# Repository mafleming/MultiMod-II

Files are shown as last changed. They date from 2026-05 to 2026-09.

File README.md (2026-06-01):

HP-71B MultiMod II Repository

# MultiMod II, ROM and RAM Storage for the HP-71B

The MultiMod II is a follow-on development of the MultiMod ROM Emulator for the HP-71B handheld computer. The MultiMod was based on a Microchip PIC processor that stored ROM images in its flash memory and made those ROMs accessible to the HP-71B operator. However, the MultiMod could not provide RAM memory.

The MultiMod II is based on a Lattice iCE40UP5K FPGA with 128KB of single port RAM (SPRAM) and 15KB of dual port RAM. The FPGA fabric provides the logic needed to present the content of the SPRAM as a series of both ROM or RAM devices. The Winbond 16KB serial flash memory serves to hold up to four FPGA configuration bitstreams, and is also used to store ROM images that the HP-71B operator can dynamically plug and unplug into the HP-71B as needed.

# MultiMod II Board Design
The MultiMod II PCB is a four layer, two sided component design. The design was done in Kicad 9.0 and the design files can be found in the **board** directory.

# MultiMod II FPGA Configuration
To configure and provide content for ROM and RAM memories, a soft CPU is instantiated in fabric using the 15KB of dual port RAM for its programs. The J1a Forth CPU was selected in order to implement the intelligent functionality of the MultiMod II HP-71B accessory. The use of Forth as the base language complemented the availability of Forth for the HP-71B itself. The basis files can be found in the **mecrisp-ice-2.7** directory.

The mecrisp-ice project combines the J1a Forth CPU with the Mecrisp ANSI Forth implementation that targets the J1a instruction set. Details about the J1a implementation can be found at James Bowman's [github repository](https://github.com/jamesbowman/swapforth). More information about Mecrisp Forth can be found at its [Sourceforge](https://mecrisp.sourceforge.net/) site. [Unofficial documentation](https://mecrisp-stellaris-folkdoc.sourceforge.io/) for Mecrisp Forth can be found on Sourceforge as well.

This configuration was customized for two purposes; one configuration serves as a programmable bootloader when connected to a host, while the second is the production configuration when the MultiMod II is operating in the HP-71B.

## Bootloader Configuration
The bootloader Verilog and Forth files can be found in the **mmj1boot** subdirectory within the **mecrisp-ice** containing directory.

The bootloader configuration uses the standard mecrisp-ice j1a processor and USB device to communicate with a connected host. Going beyond the standard bootloader ability to update the production configuration, the interactive Forth console provides the means to transfer files and even extend its own capabilities.

## Production Configuration
The bootloader Verilog and Forth files can be found in the **multimod** subdirectory within the **mecrisp-ice** containing directory.

The production bitstream configuration replaces the mecrisp-ice USB device interface with a serial interface. The serial device data and control registers are mapped into the HP-71B address space so that the HP-71B can interact with the Forth console. This gives the HP-71B operator the ability to configure the MultiMod II, plugging and unplugging ROMs at will. Independent RAM (IRAM) device content can be saved to flash, allowing the operator to compose collections of programs that can be saved to flash and later loaded when needed. All the functional capability of an external storage device are provided by the MultiMod II.

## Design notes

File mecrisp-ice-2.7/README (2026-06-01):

-------------------------------------------------------------------------------

Mecrisp-Ice - A conveniently enhanced fork of Swapforth by James Bowman

  It makes your Lattice Icestick FPGA development board
  to behave just like a microcontroller.

The original Swapforth and J1a processor implementation can be found here:
http://www.excamera.com/sphinx/article-j1a-swapforth.html

I would not have been possible without the first open-source FPGA toolchain:
http://www.clifford.at/icestorm/

Many, many thanks to James Bowman and the whole Icestorm team !

http://mecrisp.sourceforge.net/
m-atthias@users.sf.net

-------------------------------------------------------------------------------

HIC SUNT DRACONES - HIC SUNT DRACONES - HIC SUNT DRACONES

This is the first experimental release, so beware: Monsters may be inside !

-------------------------------------------------------------------------------

Shortly after Clifford Wolff, Mathias Lasser and Cotton Seed managed to build
the first working completely open-source FPGA toolchain for the iCE40-HX1K,
James Bowman started porting his elegant J1 processor design.

I have been involved in testing and enhanced the resulting monumental work
with stronger optimisations and a handfull of features for convenience.

-------------------------------------------------------------------------------

What you need:

* A Lattice Icestick with an iCE40-HX1K FPGA
    http://www.latticesemi.com/icestick

* Or a Nandland Go with iCE40-HX1K FPGA
    https://www.nandland.com/goboard/introduction.html

* Or a Lattice HX8K breakout board with an iCE40-HX8K FPGA

* The Iceprog tool to flash the included binary
    http://www.clifford.at/icestorm/

* A terminal, picocom is fine.

-------------------------------------------------------------------------------

Which board for you ?

If you just wish to play with a stack processor,
if you have small ideas,
if you desire to have IrDA communication,
if you wish a cheap, cool looking board,
if you are fine without tinkering with additional logic

  --> HX1K Icestick is your choice.

If you wish to experiment with VGA video,
if you like 7-segment displays,
if you need buttons on your board

  --> HX1K Nandland Go should be the right for you.

If you have large ideas in Forth,
if you need a lot of IO pins,
if you wish to wire in additional peripherals, opcodes or whatever you imagine,
if you love to have single cycle multiplier and barrel shifters

  --> HX8K breakout board will give you a nice time.

-------------------------------------------------------------------------------

Basic usage, same for HX1K and HX8K:

  Flash the binary:
  iceprog -b j1a.bin

  Open a terminal:

(HX1K)  picocom -b 230400 /dev/ttyUSB$n --imap lfcrlf,crcrlf --omap delbs,crlf --send-cmd "ascii-xfr -s -l 30 -n"
(HX8K)  picocom -b 115200 /dev/ttyUSB$n --imap lfcrlf,crcrlf --omap delbs,crlf --send-cmd "ascii-xfr -s -l 30 -n"

  Toggle DTR line to Reset by pressing Crtl+A Ctrl+T Crtl+A Ctrl+T

  You should get a welcome message.

  If you hard crash it, iceprog -t or a power cycle should recover.

-------------------------------------------------------------------------------

Some notes for Forth users new to this target and its peripheral possibilities:

The Icestick has 8 kb of initialised RAM which is mapped from address
$0000 to $1FFF and a SPI flash to store the FPGA bitstream and additional
user generated memory images.

Data and return stack are 16 elements deep. James implemented them as
part of the CPU itself, so they are not accessible through memory.

Pinout and board layout:

       /--------------------------------------
      /                 Header 1:  76543210-+
     /            ________              ++
    /            |        |      R      --
[USB]  FT        |  FPGA  |    R G R    73   Ir
[USB]  DI        |        |      R      62   DA
    \            |________|             51
     \                                  40
      \                 Header 2:  01234567-+
       \--------------------------------------

  Numbers are bit numbers
  + is 3.3 V   - is GND
  G Green LED  R Red LEDs

There is a separate IO address space, with those registers available:

     Addr  Bit READ            WRITE

     0001  0   PMOD in
     0002  1   PMOD out        PMOD out
     0004  2   PMOD dir        PMOD dir
     0008  3   misc.out        misc.out

     0010  4   header 1 in
     0020  5   header 1 out    header 1 out
     0040  6   header 1 dir    header 1 dir
     0080  7

     0100  8   header 2 in
     0200  9   header 2 out    header 2 out
     0400  10  header 2 dir    header 2 dir
     0800  11

     1000  12  UART RX         UART TX
     2000  13  misc.in
     4000  14  ticks           set ticks
     8000  15

Contents of misc.out and misc.in:

   Bitmask Bit  misc.out        misc.in

     0001    0  SPI CS          UART Ready to Transmit
     0002    1  SPI MOSI        UART Character received
     0004    2  SPI SCK         SPI MISO
     0008    3  IrDA-TXD        IrDA-RXD
     0010    4  IrDA-Sleep      RTS
     0020    5  CTS             Random
     0040    6  Green LED
     0080    7  Red LED
     0100    8  Red LED
     0200    9  Red LED
     0400   10  Red LED

If you are already familiar with MSP430 chips,
you will know this IO port style:

* The IN register gives the current electrical state
* The contents of the OUT registers determine what level the outputs should be
* The DIR register let you switch a pin to be an output by writing an one into

You can set two registers at once if you OR together their addresses.
  255 $440 io! should set all header pins as outputs.

Inputs can ORed together the same way and give an ORed result.

You can detect short-circuited pins -
  for example if a pin is set to output and low, but shortened to Vcc,
  then the OUT register will read back low, as set by you, but the
  IN register will read high for that pin.

Misc.out and misc.in are a mixed back of wires and flags available.

No fear to destroy the IrDA transceiver with too long pulses as it turns off
the IR LED itself when IrDA-TXD is high for more than 50 us.

The UART data register is for both incoming and outgoing data,
a read from it will clear the "Character received" flag
and you should only write to it when "Ready to Transmit" is set.

Ticks contains a 16 bit cycle counter that counts up with 48 MHz and
you can set it to any value you wish by writing to it.

Memory location $0002 is an interrupt vector for the ticks counter overflow.
You can place an opcode there, perhaps ALU Exit ($608C) or a JMP to a handler.
Interrupts can be enabled with eint and disabled with dint.

-------------------------------------------------------------------------------

Notes on HX8K:
--------------

This feels very similiar to Mecrisp-Ice on HX1K, just with a few differences:

  + Double amount of memory: 16 kb instead of 8 kb
  + Double stack depth: 32 elements each instead of 16
  + Barrel shifter for single cycle lshift rshift arshift
  + Single cycle multiplication
  + Fast opcodes for 1+ and 1-
  + rdepth
  + 8 LEDs instead of 5
  + Lots of gates free for experiments
  - 36 MHz only
  - No IrDA
  - Variable @ needs 2 instructions and 5 cycles instead of 1 instruction and 2 cycles

The peripheral map is the same, but the IN, OUT and DIR registers
are up to 16 bits wide, with the following connections:

 $0001 Port A IN     $0010 Port B IN     $0100 Port C IN
 $0002 Port A OUT    $0020 Port B OUT    $0200 Port C OUT
 $0004 Port A DIR    $0040 Port B DIR    $0400 Port C DIR

                     Red LEDs
                     76543210
  1.2V 3.3V   oo                 oo   oo
  1.2V B13    oo                 oo   oo
  A12  B12    oo     ________    oo   oo
  GND  GND    oo    |        |   oo   oo
  A11  B11    oo    |  FPGA  |   oo   oo
  A10  B10    oo    |        |   oo   oo
  A9   B9     oo    |________|   oo   oo
  GND  GND    oo                 oo   oo
  A8   B8     oo                 oo   oo
  A7   B7     oo                 oo   oo
  A6   B6     oo  Jumper config: oo   oo
  GND  GND    oo                 oo   oo
  A5   B5     oo     |     ||    oo   oo
  A4   B4     oo                 oo   oo
  A3   B3     oo        Green    oo   oo
  GND  GND    oo        LED      oo   oo
  A2   B2     oo     FT          oo   oo
  A1   B1     oo     DI          oo   oo
  A0   B0     oo                 oo   oo
  GND  GND    oo     [USB]       oo   oo
                     [USB]

  Port C is currently unconnected, you can wire the bits as you wish
  in the constraints PCF file.

Ticks contains a 16 bit cycle counter that counts up with 36 MHz and
you can set it to any value you wish by writing to it.

Memory location $0002 is an interrupt vector for the ticks counter overflow.
You can place an opcode there, perhaps ALU Exit ($608C) or a JMP to a handler.
Interrupts can be enabled with eint and disabled with dint.

-------------------------------------------------------------------------------

Notes on Nandland Go:
---------------------

S4 is Reset button, as DTR line is not connected on this board.

     Addr  Bit READ            WRITE

     0001  0   PMOD in
     0002  1   PMOD out        PMOD out
     0004  2   PMOD dir        PMOD dir
     0008  3   misc.out        misc.out

     0010  4                   VGA Colours
     0020  5                   VGA HSYNC
     0040  6                   VGA VSYNC
     0080  7   Segments        Segments

     0100  8
     0200  9
     0400  10
     0800  11

     1000  12  UART RX         UART TX
     2000  13  misc.in
     4000  14  ticks           set ticks
     8000  15

Contents of misc.out and misc.in:

   Bitmask Bit  misc.out        misc.in

     0001    0  SPI CS          UART Ready to Transmit
     0002    1  SPI MOSI        UART Character received
     0004    2  SPI SCK         SPI MISO
     0008    3  Green LED 1     Random
     0010    4  Green LED 2     S1
     0020    5  Green LED 3     S2
     0040    6  Green LED 4     S3

Note that you can OR together the VGA lines.

    VSYNC HSYNC Blue 2 Blue 1 Blue 0 Green 2 Green 1 Green 0 Red 2 Red 1 Red 0

$10:               256    128     64      32      16       8     4     2     1
$20:        512
$40: 1024

So by writing IO Register $60, you can set HSYNC and VSYNC independently
from the colour register bits. If you prefer to have all VGA signals
in one register, use IO port $70.

Ticks contains a 16 bit cycle counter that counts up with 25 MHz and
you can set it to any value you wish by writing to it.

Memory location $0002 is an interrupt vector for the ticks counter overflow.
You can place an opcode there, perhaps ALU Exit ($608C) or a JMP to a handler.
Interrupts can be enabled with eint and disabled with dint.

-------------------------------------------------------------------------------

Special features included in Mecrisp-Ice:
-----------------------------------------

You can save the complete current memory contents into the SPI flash
sectors 1 to 63. Sector 0 contains the FPGA bitstream, sector 1 will be
loaded automatically on startup if you save a memory image into this.

sector# load
sector# save
sector# erase

There is a variable "init" which is executed after loading an image.

So if you wish to create a turnkey application, prepare everything in RAM
and type:

  ' fireworks init !
  1 save

Replace fireworks with whatever you wish to be executed on startup.
Nothing is executed if init contains a zero, which is the default.

If you are not sure if it will work properly, save to any other sector
and load manually. The init mechanism works the same on all sectors.

On HX8K: Sectors 0, 1 and 2 contain the bitstream.
         Sector 3 will be loaded automatically if available.

The Nandland Go has a smaller SPI Flash with four sectors only:

  0: Bitstream
  1: Autoload
  2:  Free
  3:  Free

-----------------------------------------

For your convenience, some introspection features are preloaded for default.

Things to try:

  0 8192 dump
  insight
  see +

They will be removed by typing "new" so that you have more space available.

-----------------------------------------

Inline optimisations and constant folding are included !

-------------------------------------------------------------------------------

Main differences to Mecrisp and Mecrisp-Stellaris:

Unlike Mecrisp and Mecrisp-Stellaris, this is running completely
in RAM memory. So there is no need for special memory handling !

You can use CREATE with DOES> and if you need a buffer,
just CREATE ... ALLOT it.

By the way: If you save a memory image, the last contents of the variables
are saved during the process and reloaded with the image. Variables are
initialised, but there is no logic to reinitialise them on Reset to the
values assigned at compilation.

-------------------------------------------------------------------------------

If you wish to build the whole package yourself:

* Gforth
* Freepascal
* Yosys for synthesis
* Arachne-PNR for place and route
* Icestorm tools for bitstream generation

... and their dependencies.

In a nutshell, you need to type:

  compile
  iceprog -b j1a.bin

That's all.

;------------------------------------------------------------------------------
Here comes a word list,                                          -- Glossary --
  with short descriptions of all currently included words:
View it with fixed-width font !
;------------------------------------------------------------------------------

;------------------------------------------------------------------------------
; Terminal-IO
;------------------------------------------------------------------------------

        emit?           ( -- Flag ) Ready to send a character ?
        key?            ( -- Flag ) Checks if a key is waiting
        key             ( -- Char ) Waits for and fetches the pressed key
        emit            ( Char -- ) Emits a character.

;------------------------------------------------------------------------------
; Stack Jugglers
;------------------------------------------------------------------------------

Single-Jugglers:

        depth           ( -- +n ) Gives number of single-cell stack items.
        rdepth          ( -- +n ) HX8K only: Number of items on return stack.
        nip             ( x1 x2 -- x2 )
        drop            ( x -- )
        rot             ( x1 x2 x3 -- x2 x3 x1 )
        -rot            ( x1 x2 x3 -- x3 x1 x2 )
        swap            ( x1 x2 -- x2 x1 )
        tuck            ( x1 x2 -- x2 x1 x2 )
        over            ( x1 x2 -- x1 x2 x1 )
        ?dup            ( x -- 0 | x x )
        dup             ( x -- x x )

        >r              ( x -- ) (R: -- x )
        r>              ( -- x ) (R: x -- )
        r@              ( -- x ) (R: x -- x )
        rdrop           (  --  ) (R: x -- )

Double-Jugglers:        They perform the same for double numbers.

        2drop           ( x1 x2 -- )
        2swap           ( x1 x2 x3 x4 -- x3 x4 x1 x2 )
        2over           ( x1 x2 x3 x4 -- x1 x2 x3 x4 x1 x2 )
        2dup            ( x1 x2 -- x1 x2 x1 x2 )

;------------------------------------------------------------------------------
; Logic
;------------------------------------------------------------------------------

        arshift         ( x1 u -- x2 ) Arithmetric right-shift of u bit-places
        rshift          ( x1 u -- x2 ) Logical right-shift of u bit-places
        lshift          ( x1 u -- x2 ) Logical  left-shift of u bit-places
        invert          ( x1 -- x2 )   Invert all bits
        not             ( x1 -- x2 )   Invert all bits = Bitwise not
        xor             ( x1 x2 -- x3 ) Bitwise Exclusive-OR
        or              ( x1 x2 -- x3 ) Bitwise OR
        and             ( x1 x2 -- x3 ) Bitwise AND
        false           ( --  0 ) False-Flag
        true            ( -- -1 ) True-Flag

;------------------------------------------------------------------------------
; Arithmetic for single numbers
;------------------------------------------------------------------------------

        /mod            ( n1 n2 -- n3 n4 ) n1 / n2 = n4 rem n3
        mod             ( n1 n2 -- n3 ) n1 / n2 = remainder n3
        /               ( n1 n2 -- n3 ) n1 / n2 = n3
        *               ( u1|n1 u2|n2 -- u3|n3 ) 16*16 = 16 Multiplication
        min             ( n1 n2 -- n1|n2 ) Keeps smaller of top two items
        max             ( n1 n2 -- n1|n2 ) Keeps greater of top two items
        umin            ( u1 u2 -- u1|u2 ) Keeps unsigned smaller
        umax            ( u1 u2 -- u1|u2 ) Keeps unsigned greater
        1-              ( u1|n1 -- u2|n2 ) Subtracts one, optimized
        1+              ( u1|n1 -- u2|n2 ) Adds one, optimized

        2*              ( n1 -- n2 ) Arithmetric  left-shift
        2/              ( n1 -- n2 ) Arithmetric right-shift
        abs             ( n -- u ) Absolute value
        negate          ( n1 -- n2 ) Negate
        sgn             ( u1 n1 -- n2 ) Give u1 the sign of n2
        -               ( u1|n1 u2|n2 -- u3|n3 ) Subtraction
        +               ( u1|n1 u2|n2 -- u3|n3 ) Addition

;------------------------------------------------------------------------------
; Arithmetic involving double numbers
;------------------------------------------------------------------------------

        um*             ( u1 u2 -- ud )    16*16 = 32 Multiplication

        um/mod          ( ud u1 -- u2 u3 ) ud / u1 = u3 remainder u2

        m+              ( d1 n -- d2 ) Addition of a double with a single
        m*              ( n1 n2 -- d )     n1 * n2 = d
        fm/mod          ( d n1 -- n2 n3 )  d / n1 = n3 remainder r2 floored
        sm/rem          ( d n1 -- n2 n3 )  d / n1 = n3 remainder r2 symmetric

        */              ( n1 n2 n3 -- n4 )     n1 * n2 / n3 = n4
        */mod           ( n1 n2 n3 -- n4 n5 )  n1 * n2 / n3 = n5 remainder n4

        d2*             ( d1 -- d2 ) Arithmetric  left-shift

        dabs            ( d -- ud ) Absolute value
        dnegate         ( d1 -- d2 ) Negate
        d-              ( ud1|d1 ud2|d2 -- ud3|d3 ) Subtraction
        d+              ( ud1|d1 ud2|d2 -- ud3|d3 ) Addition
        s>d             ( n -- d ) Makes a signed single number double length

;------------------------------------------------------------------------------
; Comparisons
;------------------------------------------------------------------------------

        u<=             ( u1 u2 -- flag )   Unsigned comparisons
        u>=             ( u1 u2 -- flag )
        u>              ( u1 u2 -- flag )
        u<              ( u1 u2 -- flag )
        <=              ( n1 n2 -- flag )   Signed comparisons
        >=              ( n1 n2 -- flag )
        >               ( n1 n2 -- flag )
        <               ( n1 n2 -- flag )
        0>              ( n -- flag )       Positive ?
        0<              ( n -- flag )       Negative ?
        0<>             ( x -- flag )
        0=              ( x -- flag )
        <>              ( x1 x2 -- flag )
        =               ( x1 x2 -- flag )

        d0=             ( d -- flag )

        within          ( x1 x2 x3 -- ? )   Check if x1 is within x2 and x3.

;------------------------------------------------------------------------------
; Extension for double and s15.16 fixpoint numbers
;------------------------------------------------------------------------------

        2constant name  ( ud|d -- ) Makes a double constant.
        2variable name  ( ud|d -- ) Makes an initialized double variable

        du<=            ( ud1 ud2 -- flag )   Unsigned double comparisons
        du>=            ( ud1 ud2 -- flag )
        du>             ( ud1 ud2 -- flag )
        du<             ( ud1 ud2 -- flag )

        d<=             ( d1 d2 -- flag )     Signed double comparisons
        d>=             ( d1 d2 -- flag )
        d>              ( d1 d2 -- flag )
        d<              ( d1 d2 -- flag )

        d0<             ( d -- flag )         Negative ?
        d<>             ( xd1 xd2 -- flag )
        d=              ( xd1 xd2 -- flag )

        dmax            ( d1 d2 -- d1|d2 ) Keeps smaller of top two items
        dmin            ( d1 d2 -- d1|d2 ) Keeps greater of top two items

        2rot            ( xd1 xd2 xd3 -- xd2 xd3 xd1 )
        2nip            ( xd1 xd2 -- xd2 )

        2xor            ( xd1 xd2 -- xd3 ) Bitwise Exclusive-OR
        2or             ( xd1 xd2 -- xd3 ) Bitwise OR
        2and            ( xd1 xd2 -- xd3 ) Bitwise AND

        d2/             ( d1 -- d2 )   Arithmetric right-shift
        dshr            ( xd1 -- xd2 ) Logic right-shift

        2arshift        ( xd1 u -- xd2 ) Arithmetric right-shift of u bit-places
        2rshift         ( xd1 u -- xd2 ) Logical right-shift of u bit-places
        2lshift         ( xd1 u -- xd2 ) Logical  left-shift of u bit-places

        ud/mod          ( ud1 ud2 -- ud3 ud4 ) 32/32 = 32 rem 32 Division
                                               ud1 / ud2 = ud4 remainder ud3

Fixpoint numbers are stored ( n-comma n-whole ) and can be handled
like signed double numbers.

        s>f             ( n -- df ) Single integer to s15.16 fixpoint

        f/              ( df1 df2 -- df3 ) Division of two fixpoint numbers
        f*              ( df1 df2 -- df3 ) Multiplication

        hold<           ( char -- )
                        Adds character to pictured number output buffer
                        from behind.
        f#              ( n-comma1 -- n-comma2 )
                        Adds one comma-digit to number output
        f.              ( df -- )
                        Prints a fixpoint number with 16 fractional digits
        f.n             ( df n -- )
                        Prints a fixpoint number with n fractional digits

For internal usage:

        (ud/mod)        ( -- ) Common part of ud/mod and f/
        divisor         ( -- a-addr ) Double variable
        shift           ( -- a-addr ) Double variable
        dividend        ( -- a-addr ) Double variable

;------------------------------------------------------------------------------
; Tools for number input
;------------------------------------------------------------------------------

        number          ( c-addr len -- 0 )
                                     -- n 1 )
                                     -- n-low n-high 2 )
                        Tries to convert a string to a number.

;------------------------------------------------------------------------------
; Number base
;------------------------------------------------------------------------------

        binary          ( -- ) Sets base to 2
        decimal         ( -- ) Sets base to 10
        hex             ( -- ) Sets base to 16
        base            ( -- a-addr ) Base variable address

;------------------------------------------------------------------------------
; Memory access
;------------------------------------------------------------------------------

        cmove           ( c-addr1 c-addr2 u -- ) Moves backward
        cmove>          ( c-addr1 c-addr2 u -- ) Moves forward
        move            ( c-addr1 c-addr2 u -- ) Moves u Bytes in Memory
        fill            ( c-addr u c ) Fill u Bytes of Memory with value c

        constant  name  ( u|n -- )  Makes a single constant.
        variable  name  ( u|n -- )  Makes an initialized single variable

        2@              ( a-addr -- ud|d ) Fetches double number from memory
        2!              ( ud|d a-addr -- ) Stores double number in memory

        @               ( a-addr -- u|n ) Fetches single number from memory
        !               ( u|n a-addr -- ) Stores single number in memory
        +!              ( u|n a-addr -- ) Add to memory location

        c@              ( c-addr -- char ) Fetches byte from memory
        c!              ( char c-addr ) Stores byte in memory

IO memory area:

        io@             ( c-addr -- x ) Fetches from IO register
        io!             ( x c-addr -- ) Stores  into IO register

        xor!            ( mask c-addr -- ) Toggle bits
        bic!            ( mask c-addr -- ) Clear BIts
        bis!            ( mask c-addr -- ) Set BIts

;------------------------------------------------------------------------------
; Strings and beautiful output
;------------------------------------------------------------------------------

String routines:

        type            ( c-addr length -- )
                        Prints a string.

        rtype           ( c-addr length u -- )
                        Prints a string in a field u characters wide.

        s" Hello"       Compiles a string and
                        ( -- c-addr length )
                        gives back its address and length when executed.

        ." Hello"       Compiles a string and
                        ( -- )
                        prints it when executed.

        ( Comment )     Ignore Comment
        \ Comment       Comment to end of line

        cr              ( -- ) Emits line feed
        bl              ( -- 32 ) ASCII code for Space
        space           ( -- ) Emits space
        spaces          ( n -- ) Emits n spaces if n is positive

        accept          ( c-addr maxlength -- length ) Read input into a string.

Counted string routines:

        count           ( cstr-addr -- c-addr length )
                        Convert counted string into addr-length string

Pictured numerical output:

        [char] *        Compiles code of following char
                        ( -- char ) when executed

        char *          ( -- char ) gives code of following char
        hold            ( char -- ) Adds character to pictured number
                                    output buffer from the front.

        sign            ( n -- ) Add a minus sign to pictured number
                                 output buffer, if n is negative

        #S              ( ud1|d1 -- 0 0 ) Add all remaining digits
                        from the double length number to output buffer
        #               ( ud1|d1 -- ud2|d2 ) Add one digit from the
                        double length number to output buffer
        #>              ( ud|d -- c-addr len )
                        Drops double-length number and finishes
                        pictured numeric output ready for type
        <#              ( -- ) Prepare pictured number output buffer
        u.              ( u -- ) Print unsigned single number
        .               ( n -- ) Print single number
        ud.             ( ud -- ) Print unsigned double number
        d.              ( d -- ) Print double number

        u.r             ( u width -- ) Print      unsigned right aligned
         .r             ( n width -- ) Print        signed right aligned
        d.r             ( d width -- ) Print double signed right aligned

        buf0            ( -- a-addr ) Start of number output buffer
        buf             ( -- a-addr ) End   of number output buffer
        hld             ( -- a-addr ) Variable with current position

Deep insights:

        words           ( -- ) Prints list of defined words.
        .x2             ( c -- ) Prints  8 bit unsigned in hex base
        .x              ( u -- ) Prints 16 bit unsigned in hex base
                                 This is independent of number subsystem.

;------------------------------------------------------------------------------
; User input and its interpretation
;------------------------------------------------------------------------------

        tib             ( -- c-addr ) Input buffer
        pad             ( -- c-addr ) Location to hold temporary data

        refill          ( -- ? ) Refill input buffer, return true if successful
        source!         ( c-addr len -- ) Change source
        source          ( -- c-addr len ) Current source
        >in             ( -- addr ) Variable with current offset into source

        /string         ( c-addr1 u1 n -- c-addr2 u2 ) Cut n leading characters
        parse-name      ( -- c-addr len ) Get next token from input buffer
        parse           ( char -- c-addr len )
                        Cuts anything delimited by char out of input buffer

        evaluate        ( any addr len -- any ) Interpret given string
        quit            ( many -- ) (R: many -- ) Resets Stacks
        abort           ( many -- ) (R: many -- ) Print ? and quit

;------------------------------------------------------------------------------
; Dictionary expansion
;------------------------------------------------------------------------------

        align           ( -- ) Aligns dictionary pointer
        aligned         ( c-addr -- a-addr ) Advances to next aligned address
        cell+           ( x -- x+2 ) Add size of one cell
        cells           ( n -- 2*n ) Calculate size of n cells

        allot           ( n -- ) Tries to advance Dictionary Pointer by n bytes
        here            ( -- a-addr|c-addr )
                        Gives current position in Dictionary

        ,               ( u|n -- ) Appends a single number to dictionary
        c,              ( char -- ) Appends a byte to dictionary

        unused          ( -- u ) How many free space is still available ?

        cornerstone name    Create a permanent dictionary wayback point
        new                 Core wayback point.

;------------------------------------------------------------------------------
; Dictionary expansion  (more internal)
;------------------------------------------------------------------------------

        s,              ( c-addr len -- ) Inserts a string with a maximum
                                          of 255 characters without runtime
        sliteral        ( c-addr len -- ) Insert a string with runtime

        literal         ( u|n -- ) Compiles a literal

        compile,        ( a-addr -- ) Compiles a call to a subroutine

        forth           ( -- a-addr ) Variable with entry point for dictionary

        ahead           ( -- a-addr ) Prepare a forward jump

;------------------------------------------------------------------------------
; Flags and inventory
;------------------------------------------------------------------------------

        immediate       ( -- ) Makes current definition immediate.
        foldable        ( n -- ) Current word becomes foldable with n constants

        sfind           ( c-addr len -- c-addr len 0 | a-addr flags )
                               Searches for a string in Dictionary.

;------------------------------------------------------------------------------
; Compiler essentials
;------------------------------------------------------------------------------

        execute         ( a-addr -- ) Calls subroutine
        recurse         ( -- ) Lets the current definition call itself
        ' name          ( -- a-addr ) Tries to find name in dictionary
                                      gives back executable address
        ['] name        ( -- a-addr)  Tick that compiles the executable address
                                      of found word as literal
        postpone name   ( -- ) Helps compiling immediate words.
        does>           ( -- ) executes: ( -- a-addr )
                               Gives address to where you have stored data.
        create name     ( -- ) Create a definition with default action
        >body           ( a-addr -- a-addr ) Address of data field after create
        state           ( -- a-addr ) Address of state variable
        ]               ( -- ) Switch to compile state
        [               ( -- ) Switch to execute state
        ;               ( -- ) Finishes new definition
        : name          ( -- ) Opens new definition
        :noname         ( -- a-addr ) Opens new definition without name

;------------------------------------------------------------------------------
; Control structures
;------------------------------------------------------------------------------

Decisions:

flag if ... then
flag if ... else ... then

        then            ( -- )           This is the common
        else            ( -- )           flag if ... [else ...] then
        if              ( flag -- )      structure.

Case:

n case
     m1   of ... endof
     m2   .. ... .....
    all others
  endcase

        case            ( n -- n )       Begins case structure
        of              ( m -- )         Compares m with n, choose this if n=m
        endof           ( -- )           End of one possibility
        endcase         ( n -- )         Ends case structure, discards n

Indefinite Loops:

begin ... again
begin ... flag until
begin ... flag while ... repeat

        repeat          ( -- ) Finish of a middle-flag-checking loop.

        while           ( flag -- ) Check a flag in the middle of a loop

        until           ( flag -- ) begin ... flag until
                                    loops until flag is true
        again           ( -- )  begin ... again
                                is an endless loop
        begin           ( -- )

Definite Loops:

limit index   do ... [one or more leave(s)] ... loop
             ?do ... [one or more leave(s)] ... loop
              do ... [one or more leave(s)] ... n +loop
             ?do ... [one or more leave(s)] ... n +loop

        j               ( -- u|n ) Gives second loop index
        i               ( -- u|n ) Gives innermost loop index

        unloop          (R: old-limit old-index -- )
                        Drops innermost loop structure,
                        pops back old loop structures to loop registers

        exit            ( -- ) Returns from current definition.

        leave           ( -- ) (R: old-limit old-index -- )
                        Leaves current innermost loop promptly

        +loop           ( u|n -- )
                        (R: unchanged | old-limit old-index -- )
                        Adds number to current loop index register
                        and checks whether to continue or not

        loop            ( -- )
                        (R: unchanged | old-limit old-index -- )
                        Increments current loop index register by one
                        and checks whether to continue or not.

        ?do             ( Limit Index -- )
                        (R: unchanged | -- old-limit old-index )
                        Begins a loop if limit and index are not equal

        do              ( Limit Index -- )
                        (R: -- old-limit old-index )
                        Begins a loop

        bounds          ( addr len -- limit index )
                        Calculate values to loop over a string

;------------------------------------------------------------------------------
; SPI and low-level flash memory access
;------------------------------------------------------------------------------

        spix            ( c1 -- c2 ) Exchange one byte on SPI
        >spi            ( c -- ) Send one byte to SPI
        spi>            ( -- c ) Receive one byte from SPI
        idle            ( -- ) Set SPI flash to idle state
        spiwe           ( -- ) Write enable on SPI flash
        waitspi         ( -- ) Wait for write or erase to finish

;------------------------------------------------------------------------------
; Memory images
;------------------------------------------------------------------------------

Sectors from 1 to 63. Sector 1 is automatically loaded after Reset.

        load            ( sector# -- ) Loads an image
        save            ( sector# -- ) Saves an image
        erase           ( sector# -- ) Erase an image

        init            ( -- a-addr ) Variable containing either zero
                                      or the address of a turnkey definition
                                      which is executed automatically

;------------------------------------------------------------------------------
; Misc hardware
;------------------------------------------------------------------------------

        us              ( u -- ) Wait u microseconds
        ms              ( u -- ) Wait u milliseconds

        ticks           ( -- u ) Read current ticks
        nextirq         ( u -- ) Trigger next interrupt u cycles
                                 after the last one

        randombit       ( -- 0 | 1 ) Gives a random bit
        random          ( -- x ) Gives a random number

        eint?           ( -- ? ) Are interrupts enabled ?
        eint            ( -- ) Enable ticks counter overflow interrupt
        dint            ( -- ) Disable interrupt

;------------------------------------------------------------------------------
; Insight tools that are gone after NEW in targets with 8 kb only
;------------------------------------------------------------------------------

        .s              ( many -- many ) Prints stack contents

        dump            ( addr len -- ) Dump memory contents

        insight         ( -- ) Complete printout of dictionary structure

        name.           ( a-addr -- ) If this is the code-start of a definition,
                                      try to print its name.
        memstamp        ( a-addr -- ) Show memory location nicely
        disasm-$        ( -- a-addr ) Variable for current disasm position
        disasm-cont     ( -- a-addr ) Variable: Continue up to this position
        disasm-step     ( -- ) Disassemble one more instruction

        seec            ( -- ) Continue to see at disasm-$
        see name        ( -- ) See the definition

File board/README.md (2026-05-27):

# MultiMod-II Production Board Design
The Kicad design files and BOM for the MultiMod-II are contained here. An image of the board and its components appear below.

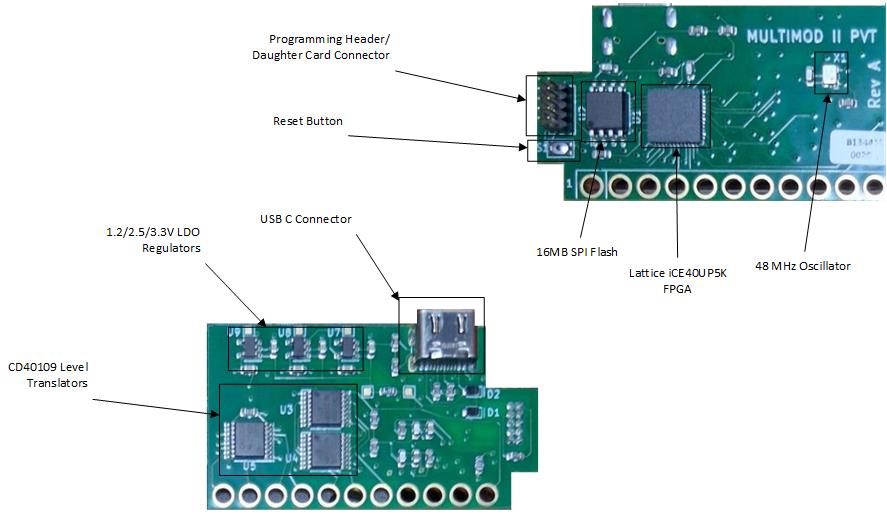
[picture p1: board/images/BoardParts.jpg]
MultiMod-II Board Components


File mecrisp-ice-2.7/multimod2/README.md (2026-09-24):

# Forth HP-71B Memory Manager for the MultiMod II
The J1a soft Forth CPU was selected in order to implement the intelligent functionality of the MultiMod II as an HP-71B accessory. The use of Forth as the base language complemented the availability of Forth for the 71B itself.

The mecrisp-ice project combines the J1a Forth CPU with the Mecrisp ANSI Forth implementation that targets the J1a instruction set. Details about the J1a implementation can be found at James Bowman's [github repository](https://github.com/jamesbowman/swapforth). More information about Mecrisp Forth can be found at its [Sourceforge](https://mecrisp.sourceforge.net/) site. [Unofficial documentation](https://mecrisp-stellaris-folkdoc.sourceforge.io/) for Mecrisp Forth can be found on Sourceforge as well.

This FPGA configuration consists of two parts; the j1a processor, and the HP71B bus Memory Manager. The manager presents the content of the 128KB SPRAM memory in the FPGA as a set of 16KB ROM or RAM devices to the HP71B Saturn processor. Up to eight 16KB devices can be connected to the HP71B four-bit bus, and respond to bus commands to read or write data to the devices.

This version of the J1a is designed to support the 71B Memory Manager by configuring the manager and copying images between SPRAM memory and SPI flash memory. The Forth console is a serial device whose data and control registers are mapped to the HP71B address space so that a program can communicate commands and receive responses.

## Project Layout
Board design and documentation for the mecrisp Forth implementation can be found in separate directories beneath the main MultiMod-II directory. The ```mecrisp-ice-x.xx``` directory contains only the board support directories for the MultiMod II. The ```multimod2``` directory contains the necessary build scripts, the default Forth files that support MultiMod II operation, and the board definition files. See the Build section of this documentation for details.

## Forth Operation
The current mecrisp-ice configuration supports the default implementation that communicates using a serial device for the default user console. Details are provided in the appropriate sections of the Notes directory.

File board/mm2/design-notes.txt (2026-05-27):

Some comments on the design for the FPGA-based MultiMod II.

I'm basing the design on the iCE40UP5K Fomu development board found at
     https://github.com/im-tomu/fomu-hardware

The FPGA flash has a boot image that can interface directly to USB. Controlled
by a RISC-V core, the Fomu appears as a DFU device for programming the attached
SPI flash chip. The FPGA is then reset to load a new configuration bitstream
from SPI flash. The RISC-V core can be directed to execute custom code on reset.
This feature has been used to configure the Fomu as a RISC-V CPU running
micropython. More details on the boot loader can be found at
     https://github.com/im-tomu/foboot

I have a few questions on the design, some of which are comments on the
schematic pages.

On the Power schematic page (second page, 3/6) I added a pullup resistor on the
Done output as you did with the Timer board. Both Fomu and Upduino leave this
pin unconnected. The datasheet notes it has a weak pullup internally. I assume
you added this because of your warning about pullups and Iq. The boot and reset
section is also from the Fomu.

You mentioned the problem of high current consumption on powering up, which you
resolved with a 47 ohm resistor in the Vcc path. Was that between the 1.2V or
the 3.3V LDO and the FPGA?

Although two power sources are shown, the 71B battery and the USB connector,
both sources are mutually exclusive. No one will be able to connect a USB cable
while the board is in the 71B. The Schottky diode is there so I can determine
which source is used and respond accordingly.

On the fourth page with the FPGA and SPI flash I just copied your Timer
connector. I'm considering just having pads that pogo pins can make contact with
and making a programming jig for boards. The Fomu does something similar and their
schematic notes that the FPGA should be reset to program the SPI flash and the
flash should have Hold asserted to program the FPGA. I believe this setup will
allow me to configure both devices on a new board.

The last page has an oscillator needed for the USB device when it is in use. It
will also be used for the Forth CPU that controls the MultiMod II operation.
I'm hoping to gate the clock to the CPU when it's not in use to save power, and
I'm considering gating the oscillator itself. Startup time is given as 5 ms max
and I think that should be more than fast enough to respond to interrupt events.
We'll see. I can switch to an internal oscillator to respond more quickly while
waiting for the external oscillator, or just use the external oscillator only
when connected to USB.

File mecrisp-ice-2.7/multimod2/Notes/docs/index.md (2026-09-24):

# Forth Embedded Controller for the MultiMod II
The J1a soft Forth CPU was selected in order to implement the intelligent functionality of the MultiMod II as an HP-71B accessory. The use of Forth as the base language complemented the availability of Forth for the 71B itself.

The **mecrisp-ice** project combines the J1a Forth CPU with the Mecrisp ANSI Forth implementation that targets the J1a instruction set. Details about the J1a implementation can be found at James Bowman's [github repository](https://github.com/jamesbowman/swapforth). More information about Mecrisp Forth can be found at its [Sourceforge](https://mecrisp.sourceforge.net/) site. [Unofficial documentation](https://mecrisp-stellaris-folkdoc.sourceforge.io/) for Mecrisp Forth can be found on Sourceforge as well.

This version of the J1a has the software functionality and the hardware needed to interact with the HP-71B peripheral bus in order to present RAM and ROM device plug-ins. The 128 KB of Single Port RAM (SPRAM) in the FPGA can present up to eight 16 KB ROM, RAM, or Independent RAM (IRAM) devices. The 16 KB devices can be chained together to form larger storage units. The content of those storage units can be initialized from the 16 MB boot flash device, giving the HP-71B owner the impression of plugging in ROM memory modules on demand.

## MultiMod II Embedded Controller Purpose
An FPGA will load its design configuration, stored as a bitstream in external flash memory, when it first powers up or is forced to reset. Putting this configuration in flash requires equipment that is likely unavailable to a MultiMod II owner. A bootloader is a design configuration that will sense whether the MultiMod II is connected to a USB host. If so, it allows the host to update a working design configuration and then transfer control to that "production" configuration. If not connected to a USB host, control is immediately transferred to the working production configuration. In addition to updating the production FPGA configuration, the bootloader also allows the owner to transfer ROM and IRAM images between their personal computer and the MultiMod II flash memory.

The production configuration contains the digital logic necessary to present the 128 KB of SPRAM as memory devices to the HP-71B Saturn processor. The role of the j1a Forth CPU and its software is to configure the SPRAM as one or more memory devices and transfer content from the 16 MB boot flash device to these devices through owner command.

The owner communicates with the Forth console via control and data registers that appear as a pseudo-serial device in the HP-71B address space, specifically the register space reserved for the HP-71B Card Reader device. The owner uses commands such as **PLUG** and **UNPLUG** to emulate the action of inserting or removing actual physical ROM or RAM modules. Independent RAM (IRAM) modules can also be loaded, modified, and later saved back to the 16 MB boot flash.

## Project Layout
Board design and documentation for the mecrisp Forth implementation can be found in separate directories beneath the main MultiMod-II directory. The `mecrisp-ice-x.xx` directory contains the board support directories for the MultiMod II. The `mmj1boot` directory contains the necessary build scripts, the default Forth files that support MultiMod II bootloader operation, and the board definition files. The `multimod2` directory (this directory) contains the FPGA configuration, Forth files, and build scripts to create the production FPGA bitstream. See the Build section of this documentation for details.

## Forth Operation
The current mecrisp-ice configuration supports a serial device implementation that communicates with the default user console. An initial Forth dictionary that is a part of the production configuration bitstream contains Forth words needed to support desired interactivity.

The j1a hardware design controls the HP-71B memory management logic via registers mapped into the j1a I/O address space. The j1a hardware design has also been augmented with the necessary warm boot design components so that control can be transferred to alternative FPGA bitstream configurations. Details are provided in the appropriate sections of these Notes.

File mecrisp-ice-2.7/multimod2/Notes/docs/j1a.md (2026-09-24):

# The J1A Forth CPU Verilog File

## iCE40UP5K FPGA Pin Assignments
The various MultiMod II signal connections are given in the table below. Signals are grouped by function rather than IO block/pin number.

**HP-71B Bus Signals**
```
Signal         FPGA Name           SG48 Pin
------------   -----------------   ------------
Data IO 0      IOB_0a              46
Data IO 1      IOB_2a              47
Data IO 2      IOB_5b              45
Data IO 3      IOB_3b_G6           44
StrobeN        IOT_45a_G1          37
Cmd/DatN       IOT_48b             36
DaisyIn        IOT_44b             34
```
**HP-71B Bus Level Shifter Control Signals**
```
Signal         FPGA Name           SG48 Pin
------------   -----------------   ------------
Data Out Enb   IOB_4a              48
Data In Enb    IOT_51a             42
Cntrl In Enb   IOB_50b             38
```
**External Device Control Signals**
```
Signal         FPGA Name           SG48 Pin
------------   -----------------   ------------
USB Pos        IOT_38b             27
USB Neg        IOT39a              26
USB Active     IOB_6a               2
USB Pullup     IOT_42b             31
Osc Enable     IOT_46b_G0          35
Osc Output     IOT_36b             25
```
**External Flash Storage Signals**
```
Signal         FPGA Name           SG48 Pin       Flash         Pin
------------   -----------------   ------------   -----------   -----
SPI_SO         IOB_32a             14             DI (IO0)       5
SPI_SI         IOB_33b             17             DO (IO1)       2
SPI_SCK        IOB_34a             15             CLK            6
SPI_SS         IOB_35b             16             /CS            1
GPIO           IOB_24a             13             IO3 (/HOLD)    7
GPIO           IOB_25b_G3          20             IO2 (/WP)      3
```

## CPU External Signal Modifications
The J1A module definition was modified to include an output pin for the external clock oscillator enable signal. The ```clk_en``` signal should be set to logic high by default.

The pins associated with the USB data signals and pullup are ```usb_dn```, ```usb_dp```, and ```usb_pu```. These signals are mapped to FPGA pins not enumerated in the default J1a CPU.

Likewise, the ```to71```, ```from71```, and ```ctrl71``` outputs that control the tristate level shifters are added to the default J1a CPU interface. These also should be set to logic low so that the buffers are tri-stated. These may not be necessary since the enable inputs are pulled low and unconfigured IO pins are likely left floating.

> ***Check this in the FPGA data sheet***

The header is 
```
module top (
    input  clki,   // 48 MHz clock input
    output clk_en, // Enable external clock

    inout  data_1,   // Four user pins
    inout  data_2,
    inout  data_3,
    inout  data_4,

    output rgb0,   // LED outputs
    output rgb1,
    output rgb2,

    output spi_cs,      // SPI Flash
    output spi_clk,
    inout  spi_mosi,
    inout  spi_miso,
    inout  spi_io2,
    inout  spi_io3,

    inout  usb_dp,    // USB pins
    inout  usb_dn,
    output usb_dp_pu,
    input  usb_activ,

    output to71,  // Tristate buffer control
    output from71,
    output ctrl71,

    input  din71,  // HP71B bus control signals
    input  cdn71,
    input  strn71
);
```

The three RGB pins could be removed for power saving reasons, though doing so would require further modification to the Verilog source to remove references to the signals. The pins are unconnected to any external device.

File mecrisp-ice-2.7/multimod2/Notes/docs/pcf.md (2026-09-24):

# The MultiMod II Pin Definitions
The pin assignments in the ```multimod-evt.pcf``` file map the signals declared in the module header of ```j1a.v``` to actual pins in the Lattice FPGA SG48 package.

## Pin Assignments
The ```pmod_(1,2,3,4)``` names match those declared in the j1a.v module declaration and will need to be renamed in both files to something like the ```Bio(0,1,2,3)``` names found on the MultiMod II schematic.

```
set_io rgb0 39
set_io rgb1 40
set_io rgb2 41

set_io data_0 46
set_io data_1 47
set_io data_2 45
set_io data_3 44

set_io to71   48
set_io from71 42
set_io ctrl71 38

set_io din71  34
set_io cdn71  36
set_io strn71 37

set_io spi_mosi 17
set_io spi_miso 14
set_io spi_clk  15
set_io spi_io2  20
set_io spi_io3  13
set_io spi_cs   16

set_io usb_dn    26
set_io usb_dp    27
set_io usb_dp_pu 31
set_io usb_activ  2

set_io clki    25
set_io clki_en 35
```

## Trivia
In the original MultiMod II design the pins for ```clki``` and ```clki_en``` were swapped. This worked fine for the mecrisp-ice design and so four test boards were ordered. It quickly turned out after receiving the test boards that the two candidate bootloader designs could not be synthesized using this pin assignment, and so the pins were swapped, new boards were orderd, and the old test boards were scrapped.

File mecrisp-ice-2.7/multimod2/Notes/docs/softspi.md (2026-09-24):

# Acknowledgements
Select Forth code in this file is derived from UPduino-Mecrisp-Ice-15kB by Igor-m
BSD 3-Clause license

See: https://github.com/igor-m/UPduino-Mecrisp-Ice-15kB

# Flash Memory Structure
Flash memory can't be written on an individual memory cell basis; a cell must be erased and then the contents of the cell written back. An entire sector must be erased before data can be written to cells in the sector. In the Winbond standard SPI flash device, sectors can be erased in 4 KB, 32 KB or 64 KB sized blocks.

The MultiMod II treats its 16 MB flash memory as a array of 1024 blocks of 16 KB size, with each block on a 16 KB address boundary. The flash memory is divided into three sections; section one for FPGA bitstreams and their associated data, section two for Forth dictionary images and data files, and the third section for 71B ROM and IRAM images. ROM and IRAM images are 1,  2, or 4 blocks in size (16/32/64 KB).

# SPI Flash Memory Support
The words in this file provide support for SPI flash memory devices using a "bit-bang" approach to communication. This admittedly simple approach to implementing an SPI interface is nonetheless fast enough for purposes of the MultiMod II project.

The Low Level Support section describes the software implementation of the SPI hardware protocol. Should the built-in hard SPI fabric be used (or soft SPI driver), its code would replace the words found in the Low Level Support section.

The API Functions section are words used by the remainder of the MultiMod II support code. These functions treat the SPI flash memory as a sequence of 16 KB pages - in the case of a 16 MB flash device, pages 0 to 1023.

## Constants and Variables
The following definitions define boundaries within flash for bitstream, Forth dictionaries, and ROM/IRAM images. Low level words use these values to partition flash and protect critical sections.

- **core4th -** Mark The End Of Mecrisp Forth Words.  
This word marks the default dictionary words provided by Mecrisp Forth. It cn be used to purge all dictionary entries that follow if the entirety of the MultiMod II words are to be completely replaced with a new version, starting here at the SPI interface found in the *soft-spi.fs* file.  
<br>

- **bitfence (constant 8) - ** Bitstream Partition Point.  
The 16KB page below which no writes can occur. Flash address $20000 or 128KB.  

- **frtstart (constant 64) - ** Start Of Forth Dictionary Images.  
Starting 16KB page where Forth dictionary image storage begins. The first two pages are reserved for the image directory. Flash address $100000 or 1MB.  

- **romstart (constant 128) - ** Start Of HP-71B ROM/IRAM Images.  
Starting 16KB page where HP-71B image storage begins. The first two pages are reserved for the image directory. Flash address $200000 or 2MB.  
<br>

## Low Level Support
The Forth words in this section implement the software-based SPI interface. These functions are not used by ordinary user functions.

- **spimode_std ( -- ) -** Set FPGA I/O to Standard mode.  
Commands and Data are sent in Standard transfer mode wherein **MISO** is an input to the FPGA and **MOSI**, **IO2**, and **IO3** are outputs.  

- **spidual_out ( -- ) -** Set FPGA I/O to Dual output mode.  
Data is sent in Dual transfer mode wherein **MISO** and **MOSI** are outputs.  

- **spidual_in ( -- ) -** Set FPGA I/O to Dual input mode.  
Data is received in Dual transfer mode wherein **MISO** and **MOSI** are inputs.  

- **spiquad_out ( -- ) -** Set FPGA I/O to Quad output mode.  
Data is sent in Quad transfer mode wherein **MISO**, **MOSI**, **IO2** and **IO3** are outputs.  

- **spiquad_in ( -- ) -** Set FPGA I/O to Quad input mode.  
Data is received in Quad transfer mode wherein **MISO**, **MOSI**, **IO2**, and **IO3** are inputs.  

- **idle ( -- ) -** Disable Device.  
Deasserting the Chip Select pin will put the flash memory chip in a quiescent power mode. But it is also needed for other commands, such as the sector erase commands where the chip must be deselected immediately after sending the command. The SPI transfer mode is also set to Standard.  

- **spixbit ( x -- y ) -** Read/Write Data Bit.  
The high order bit of the 16-bit word **x** is shifted out to the SPI data out pin and then the SPI data in pin is shifted into the low bit of **x** returning **y**.  

- **spix ( outdata -- indata ) -** Read/Write Data Byte.  
Used follow a Read or Write command. Data on the stack is written to flash following a Write command but is ignored following a Read command. Data returned by this function is valid following a Read command but is an undefined value following a Write command.   

- **\>spi ( -- byte ) -** Read Data Byte.  
Use `spix` to return a read data byte (zero if used with a write command).  

- **spi\> ( byte -- ) -** Write Data Byte.  
A zero byte is shifted out while the read data is shifted in and the data byte is returned on the stack.  

- **waitspi ( -- ) -** Wait For Device Ready.  
Checking for the Write In Progress flag to go low is needed immediately after sending an Erase Sector command.  

- **spiwe ( -- ) -** Enable Writing To Device.  
On application of power, the flash device will not allow erase or write commands until it is unlocked. There is a corresponding disable command. though it is currently not needed. In addition, there are sector write disable commands that could be added to protect the bitstream section of the chip from accidental overwrite.  

- **spi_powerdn ( -- ) -** Power Down The Flash Device.
The standby current can drop from 10uA to 1uA in power down mode. The drawback is the delay needed to power up the device before it will respond to commands. Best used when the HP-71B CPU issues the Shutdown command.

- **spi_powerup ( -- ) -** Restore From Power Down Sleep.
Brings the flash device back to the operational state, ready to accept commands.  

## API Support Functions
The words in this section are used only by the API function words. These functions do not implement any address range restrictions.

- **sect2addr ( sector16k -- double_rom_addr ) -** Sector Number to 24-bit Address.  
Convert a 10-bit sector address word ( 0~1023 ) into a 24-bit double-word address suitable for an SPI Read or Write command.  

- **addr2sect ( double_rom_addr -- sector16k ) -** 24-bit Address to Sector Number.  
Convert a double-word containing a 24-bit flash address to a sector number. The lower 14 bits are truncated.  

- **addr2spi ( double_rom_addr -- ) -** Output 24-bit Address to SPI.  
The 24-bit address in a double-word is written as three bytes to the SPI interface, high byte first. Bytes are written high bit first.  

- **spiread ( double_rom_addr -- ) -** Address A General Memory Location.  
This function can be used to read from flash memory starting at any location. Subsequent >spi commands will return each sequential data byte after a first dead read cycle.  

- **spiread16k ( sector16k -- ) -** Address Start Of Memory Sector.  
This function is passed a 16 KB sector number in the range of 0 to 1023 for the 16 MB SPI flash memory device. Sets up a read operation like the `spiread` command.  

## SPI Utility Functions

- **spiflush ( Nbytes -- ) -** Read And Discard Memory Bytes.  
This function is provided as a means of advancing the read memory address without having to reissue an spiread/spiread16k command.  

- **spidump ( Nbytes -- ) -** Read And Display Memory Bytes.  
This function is provided as a means of examining the read memory address content.  

- **numsectors ( -- sector16k_count ) -** Return Number Of Memory Sectors.  
This function uses the second byte from a Manufacturer ID, returned by the Read JEDEC ID command, to determine flash memory capacity. Useful in place of a hard coded size value.

## API Functions
These words, developed for the MultiMod II, are the formal interface to flash memory. User programs can use them to access or update image or data files. These words prevent write access to bitstream data in section one of flash memory. They **do not** limit Forth dictionary images to section two of flash memory.

- **erase4k ( sector4k -- ) -** Erase A 4 KB Sector.  
This command uses a standard JEDEC command to erase the smallest size sector in flash memory. Rather than pass a full 24 bit memory address, the function is given a sector number from 0 to 4095. This insures the address sent in the command is at the beginning of a given sector.  

- **erase ( sector16k -- ) -** Erase A 16 KB Page.  
Since the MultiMod II treats flash memory as a sequence of 16 KB blocks, this command is used to erase one such block in preparation for writing. The function takes a block number from 0 to 1023.  

- **load ( sector16k -- ) -** Load Forth Dictionary.  
The Forth CPU dictionary is in the 15 KB Dual-Port Memory of the FPGA. This command will overwrite that internal memory with the content of a specified 16 KB block in flash memory. Input is the range 0 to 1023.  

- **save ( sector16k -- ) -** Save Forth Dictionary.  
The content of the Forth CPU dictionary is written to a specified 16 KB block location in flash memory. The state of the Forth CPU can thus be restored using this command, allowing different Forth configurations for different tasks.  

- **hp71b-1 -** Mark Top of Fixed Dictionary Words.  
The words defined in this and the constants file are the basis of all other code accessing the SPI flash memory. This marks the root of all other versions of the Forth dictionary.

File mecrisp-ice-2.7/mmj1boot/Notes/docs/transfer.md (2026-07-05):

# File Transfer Support
These Forth words support the transfer of ROM/IRAM images to and from the MultiMod II as well as transferring FPGA bitstream images to the MultiMod II flash storage. The latter capability is used to update the production configuration of the MultiMod II as well as to install optional configurations.

File transfer is done using the Kermit protocol, which is supported by most terminal emulators.

## Forth Dictionary Images
Forth dictionary images can be loaded or saved via the Forth dictionary using the following commands. Note that Forth words in a text file can be simply sent via a terminal emulator to the Forth console rather than typing in definitions by hand.

- **forthsave ( name -- ) -** Save Forth Dictionary Image.  
If `name` doesn't exist in the dictionary it is created, otherwise the current image updates the image stored in flash.  

- **forthload ( name -- ) -** Load Forth Dictionary By Name.  
The current Forth dictionary is replaced by the `name` image in flash. If that name doesn't exist in the dictionary, then no change occurs.  

- **forthlist ( -- ) -** List Forth Dictionary Entries.  
This uses the `dir_list` command from the `directory.fs` set of words to list entries in the Forth directory.  

## HP-71B ROM/IROM Images
ROM image `.bin` files can be sent using the Kermit protocol. ROM/IRAM images in flash can be downloaded and automatically given the `.bin` extension.

- **romverify ( ram# name -- ram_addr flag ) -** Verify Flash Image By Name.  
Given a name in the ROM directory and the starting point of an image in SPRAM, verify the content in SPRAM matches that of the image in SPRAM. The size of the image in the directory entry is used to determine the length of the image in 16KB sectors. The last memory address examined is returned along with a Pass/Fail flag. If the images don't match the **ram_addr** indicates the point of first mismatch.  

- **writeflash ( name type -- ) -** Upload ROM/IROM Image To Flash.  
Uploads a file and stores the file in flash, adding *name* to the ROM/IROM directory.  

- **readflash ( name -- ) -** Download Flash Image By Name.  
Downloads the *name* ROM/IROM image using the Kermit receive protocol.  

- **romlist ( -- ) -** List HP-71B Directory Entries.  
This uses the `dir_list` command from the `directory.fs` set of words to list ROM/IRAM image entries in the HP-71B directory.

## FPGA Bitstream Images
There are four locations, slots 0 through 3, in the first megabyte of flash memory that store bitstream images. The first, slot 0, is the bootloader and cannot be erased or altered. The second, slot 1, is the MultiMod II production configuration that is loaded while the MultiMod II is in the HP-71B card reader cavity. Slots 2 and 3 are for alternate configurations that can be loaded via a warm boot.

- **bitstream ( slot -- ) -** Transfer FPGA Bitstream.
<br>
Uploads a bitstream file to flash and loads it as bitstream number `slot`. The slot number does not include 0, the bootloader bitstream image itself.
<br>

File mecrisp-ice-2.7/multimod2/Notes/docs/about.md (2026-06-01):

# MultiMod II for the Hewlett Packard HP-71B Pocket Computer
The MultiMod II is a successor to the [MultiMod ROM](https://github.com/mafleming/HP71MultiMod) emulator board for the HP71B. The original board fit into the card reader slot of the HP-71B and could emulate up to 120 KB of ROMs.

The MultiMod II can emulate up to 128 KB of mixed ROM, RAM, and Independent RAM (IRAM). ROM and IRAM images are stored in a 16 MB flash memory device. Images can be loaded, unloaded, or saved by user command. The HP-71B owner can configure ROM and RAM on the fly to match current needs, and backup IRAM content to flash so that no work is lost if batteries fail.

## Design Decision Issues
There are several design decisions that affect the functionality and usability of the MultiMod II. First and formost is the choice of a bootloader. The are a number of suitable bootloaders for the Lattice FPGA platform, but they are limited to making production updates, with little or no support for other operations.

The choice of how to implement a file system in flash for Forth dictionary images and for HP-71B ROM/IRAM images has a number of constraints that must be managed. Another issue is whether to have separate directories for Forth images and HP-71B images, or just a single combined directory.

The user interface for the MultiMod II when plugged into a USB host has important implications for ease of use by owners of differing technical sophistication. The interface should make software updates simple, while also supporting files transfers with a minimal host-side client requirement.

## Future Enhancements

The MultiMod II is designed to easily update the FPGA configuration and Forth support software via its USB connection. Plans also include support for the embedded Forth machine to access IRAM file systems when installed in an HP-71B and to act as a coprocessor for the 71B itself.

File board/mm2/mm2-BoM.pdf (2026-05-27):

Source: | C:\Users\Mark\Documents\GitHub\HP71MultiMod2\board\mm2\mm2.kicad_sch
Date: | | 11/24/2023 11:04
Tool: | | Eeschema 7.0.6
Generator: | C:\Program Files\KiCad\7.0\bin\scripting\plugins/bom_csv_grouped_by_value.py
Component Count: | 44

Collated Components:

Item | Qty | Reference(s) | Value
1 | 5 | C1, C2, C3, C4, C5 | 100nF
2 | 7 | C6, C7, C8, C9, C10, C11, C12 | 1uF
3 | 1 | C13 | 4.7uF
4 | 2 | D1, D2 | CDBUC00340‐HF
5 | 1 | J1 | Conn_01x11
6 | 1 | J2 | USB_C_Receptacle_USB2.0
7 | 1 | J3 | Conn_02x05_Odd_Even_1.27
8 | 1 | R1 | 1 Ohm, 1%
9 | 2 | R2, R3 | 22 Ohm
10 | 1 | R4 | 100 Ohm
11 | 2 | R5, R6 | 5K1
12 | 3 | R7, R8, R9 | 10K
13 | 1 | R10 | 51K
14 | 4 | R11, R12, R13, R15 | 100K
15 | 1 | S1 | Alps PB SW
16 | 2 | TP1, TP2 | TestPoint
17 | 1 | U1 | ICE40UP5K‐SG48ITR
18 | 1 | U2 | W25Q128JVS
19 | 3 | U3, U4, U5 | CD40109BPWR
20 | 1 | U7 | AP2127K‐1.2
21 | 1 | U8 | AP2127K‐3.3
22 | 1 | U9 | AP2127K‐2.5
23 | 1 | X1 | ECS‐2520MV‐480‐BN

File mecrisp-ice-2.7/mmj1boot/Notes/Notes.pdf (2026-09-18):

# MultiMod II Bootloader

A Forth CPU Based Customizable Bootloader

Mark A Fleming

BSD 3-Clause "New" or "Revised" License

Table of contents

1. Home | 4
1.1 Forth Bootloader for the MultiMod II | 4
1.2 MultiMod II for the Hewlett Packard HP-71B Pocket Computer | 6
1.3 License | 7
2. Build Instructions | 8
2.1 MultiMod II Bootloader Build Instructions | 8
3. Build Files | 12
3.1 The J1A Forth CPU Verilog File | 12
3.2 The MultiMod II Pin Definitions | 14
4. Functionality | 15
4.1 Features and Requirements for the MultiMod II Bootloader | 15
4.2 MultiMod II Flash Memory | 17
5. File System | 19
5.1 MultiMod II Flash File System | 19
5.2 Directory Implementation | 21
6. Forth System | 23
6.1 The j1a Forth CPU | 23
6.2 Mecrisp Forth Implementation | 25
7. Forth Files | 26
7.1 Acknowledgements | 26
7.2 Flash Memory Structure | 26
7.3 SPI Flash Memory Support | 26
7.4 Lattice FPGA Multiboot Support | 32
7.5 SPI Flash Security Related Functions | 33
7.6 Flash <--> SPRAM Transfer Support | 34
7.7 Hex File Transfer Support | 36
7.8 Flash File System Directory | 37

Table of contents

- 2/44 - | BSD 3-Clause "New" or "Revised" License

7.9 File Transfer Support | 43 Table of contents
- 3/44 - | BSD 3-Clause "New" or "Revised" License

### 1. Home

### 1.1 Forth Bootloader for the MultiMod II

The J1a soft Forth CPU was selected in order to implement the intelligent functionality of the MultiMod II as an HP-71B accessory. The use of Forth as the base language complemented the availability of Forth for the 71B itself.

The mecrisp-ice project combines the J1a Forth CPU with the Mecrisp ANSI Forth implementation that targets the J1a instruction set. Details about the J1a implementation can be found at James Bowman's github repository. (https://github.com/jamesbowman/swapforth) More information about Mecrisp Forth can be found at its Sourceforge (https://mecrisp.sourceforge.net/) site. Unofficial documentation (https://mecrisp-stellaris-folkdoc.sourceforge.io/) for Mecrisp Forth can be found on Sourceforge as well.

This version of the J1a its functionality with the hardware needed to perform USB detection and warm boot of a selected bitstream. The warm boot capability will also be present in the default working bitstream configuration so that the MultiMod II can be rebooted into a different configuration of the owners choice.

### 1.1.1 Bootloader Purpose

An FPGA will load its design configuration, stored as a bitstream in external flash memory, when it first powers up or is forced to reset. Putting this configuration in flash requires equipment that is likely unavailable to a MultiMod II owner. A bootloader is a design configuration that will sense whether the MultiMod II is connected to a USB host. If so, it allows the host to update a working design configuration and then transfer control to that "production" configuration. If not connected to a USB host, control is immediately transferred to the working production configuration.

There are a number of available bootloaders for the Lattice iCE40 FPGAs. A bootloader provides the means of updating the working FPGA bitstream configuration without the need for equipment to update the flash memory storing the configuration. Most bootloaders are a simple affair, providing only the means of updating the working FPGA bitstream configuration. However, the MultiMod II also requires a means of transferring user data files between the MultiMod II flash memory and the user PC.

1. Home
- 4/44 - | BSD 3-Clause "New" or "Revised" License

The desired interactivity with the MultiMod II is complex enough to use the J1A Forth CPU in place of a simple single-purpose bootloader. This also means that the bootloader program itself can be augmented by the MultiMod II owner to extend its capability even after its purchase.

### 1.1.2 Project Layout

Board design and documentation for the mecrisp Forth implementation can be found in
separate directories beneath the main MultiMod-II directory. The | mecrisp-ice-x.xx | directory
contains only the board support directories for the MultiMod II. The | mmj1boot | directory
contains the necessary build scripts, the default Forth files that support MultiMod II operation, and the board definition files. See the Build section of this documentation for details.

### 1.1.3 Forth Operation

The current mecrisp-ice configuration supports the default implementation that communicates using the USB device for the default user console. An initial Forth dictionary that is a part of the bootloader configuration bitstream contains Forth words needed to support desired interactivity. The J1A hardware design has also been augmented with the necessary warm boot design components so that control can be transferred by loading an alternative FPGA bitstream configuration such as the production bitstream design to interface the MultiMod II with the HP-71B bus. Details are provided in the appropriate sections of these Notes.

1.1.2 Project Layout

- 5/44 - | BSD 3-Clause "New" or "Revised" License

### 1.2 MultiMod II for the Hewlett Packard HP-71B Pocket Computer

The MultiMod II is a successor to the MultiMod ROM (https://github.com/mafleming/HP71MultiMod) emulator board for the HP71B. The original board fit into the card reader slot of the HP-71B and could emulate up to 120 KB of ROMs.

The MultiMod II can emulate up to 128 KB of mixed ROM, RAM, and Independent RAM (IRAM). ROM and IRAM images are stored in a 16 MB flash memory device. Images can be loaded, unloaded, or saved by user command. The HP-71B owner can configure ROM and RAM on the fly to match current needs, and backup IRAM content to flash so that no work is lost if batteries fail.

### 1.2.1 Design Decision Issues

There are several design decisions that affect the functionality and usability of the MultiMod II. First and formost is the choice of a bootloader. The are a number of suitable bootloaders for the Lattice FPGA platform, but they are limited to making production updates, with little or no support for other operations.

The choice of how to implement a file system in flash for Forth dictionary images and for HP-71B ROM/IRAM images has a number of constraints that must be managed. Another issue is whether to have separate directories for Forth images and HP-71B images, or just a single combined directory.

The user interface for the MultiMod II when plugged into a USB host has important implications for ease of use by owners of differing technical sophistication. The interface should make software updates simple, while also supporting files transfers with a minimal host-side client requirement.

### 1.2.2 Future Enhancements

The MultiMod II is designed to easily update the FPGA configuration and Forth support software via its USB connection. Plans also include support for the embedded Forth machine to access IRAM file systems when installed in an HP-71B and to act as a coprocessor for the 71B itself.

1.2 MultiMod II for the Hewlett Packard HP-71B Pocket Computer

- 6/44 - | BSD 3-Clause "New" or "Revised" License

### 1.3 License

The Forth software and modified Verilog for the MultiMod II adheres to the overall license for James Bowman's mecrisp-ice (BSD 3-Clause "New" or "Revised" License) distribution.

1.3 License

- 7/44 - | BSD 3-Clause "New" or "Revised" License

### 2. Build Instructions

### 2.1 MultiMod II Bootloader Build Instructions

These instructions assume a Linux build environment, specifically Pop!_OS. (https://pop.system76.com/) Other Linux distributions are likely sufficient if they are supported by the toolchains used herein. The author has used WSL (Windows System for Linux) as well for early exploration.

### 2.1.1 Setup

This version begins by building the design in the | mmj1boot | directory using the Fomu (https://www.crowdsupply.com/sutajio-kosagi/fomu)
development platform's designer-provided toolset. The tar file containing the icestorm tools (https://github.com/im-tomu/fomu-toolchain) should be installed in /opt/fomu-toolchain-Linux. Place its bin subdirectory FIRST in your PATH environment variable.

export PATH=/opt/fomu-toolchain-Linux/bin:$PATH

Use | sudo apt install gforth | to install an old version of gforth in order to compile the latest
Gforth (https://gforth.org) source files. The older default version of gforth works fine, though I did build the latest version from source just in case any significant changes or improvements to gforth occurred.

### 2.1.2 Compilation and Synthesis

Within the | mmj1boot | directory use the | compile | command script to create an initial Forth
dictionary image using | compilenucleus | and using the above icestorm toolset to synthesize the
J1A CPU design. An unrecognized option appears in the first command in the compile script
that invokes yosys, the | -noabc9 | option. The build completes successfully with this option
removed.
The script needs a seed value when invoking the | nextpnr-ice40 | place and route program. The
value used (11) was determined by successively trying values, starting with 1, until a seed was found that allowed synthesis to complete with all clock constraints satisfied. At the end of the
build the bitstream file | j1a.dfu | will appear in the | mmj1boot | directory.
Within the build directory will be found the | j1a.bin | and | multiboot.bin | files. These binary files
can be used to program flash memory on the MultiMod II board. The | multiboot.bin | file
incorporates both this bootloader bitstream and the production bitstream configuration as the second image.
2. Build Instructions
- 8/44 - | BSD 3-Clause "New" or "Revised" License

### 2.1.3 Development Testbed

Developing the Forth code to support interaction with the FPGA and the external SPI flash memory can be done with a development environment that replicates some of the MultiMod II physical board. One such testbed is the Fomu (https://github.com/im-tomu/fomu-hardware) development board that fits in a USB slot.

Using the Fomu testbed:

Run | ./compile | in the | fomu | subdirectory to build a new bitstream image.
Run | sudo /opt/fomu-toolchain-Linux/bin/dfu-util -l | to list the attached DFU device(s) identification
status.
Run | sudo /opt/fomu-toolchain-Linux/bin/dfu-util -D j1a.dfu | in the fomu subdirectory to load the
newly built bitstream image. You may need to supply the vendor and device id as parameters to the command if more than one DFU capable device is attached. I recommend having only the Fomu attached to avoid confusion or mistake.
Run | sudo /opt/fomu-toolchain-Linux/bin/dfu-util -e | in the fomu subdirectory.
Run | sudo dmesg | grep tty | to identify the tty to which Fomu is attached. By default it should be /
dev/ttyACM0```

Communication

Use | minicom -b 115200 -D /dev/ttyACM0 | to connect to the Forth CPU. Note that you'll need to add
yourself to the dialout group. An alternative terminal program is GTKTerm, which is more easily configurable.

Invoke minicom communication (control-A Z) then set lineWrap on/off (control-A Z W) followed by Add Carriage Ret (control-A Z U). Set the comm parameters to 8N2 (control-A Z P X). You'll need to add some delay to each character sent by minicom to the Forth console via the terminal settings (control-A Z T). Set the character send delay to 1 milliseconds and the line end delay to 50 milliseconds. The same character delay will be needed by other terminal emulators, such as TeraTerm.

For the above settings to work properly, use the | dint | command at the start of your
working session to disable interrupts.

2.1.3 Development Testbed

- 9/44 - | BSD 3-Clause "New" or "Revised" License

Note: to avoid using sudo each time you run dfu-util, you can change the permissions for the
usb device. First, identify the device using the lsusb command

lsusb Bus 004 Device 001: ID 1d6b:0003 Linux Foundation 3.0 root hub Bus 003 Device 113: ID 1209:5bf0 Generic Fomu PVT running DFU Bootloader v2.0.3 Bus 003 Device 111: ID 0c45:7692 Microdia USB Keyboard Bus 003 Device 110: ID 045e:0773 Microsoft Corp. Microsoft® Nano Transceiver v1.0 Bus 003 Device 112: ID 1209:2211 Generic Mathpad Bus 003 Device 109: ID 1a40:0101 Terminus Technology Inc. Hub Bus 003 Device 004: ID 8087:0033 Intel Corp. Bus 003 Device 098: ID 0483:5740 STMicroelectronics Virtual COM Port Bus 003 Device 001: ID 1d6b:0002 Linux Foundation 2.0 root hub Bus 002 Device 001: ID 1d6b:0003 Linux Foundation 3.0 root hub Bus 001 Device 001: ID 1d6b:0002 Linux Foundation 2.0 root hub
The device is identified as Generic Fomu PVT running DFU Bootloader v2.0.3. Note the Bus
and Device numbers. For the above example, go to /dev/bus/usb/003, then do a chmod 0777
113 to give permissions to all. From there, you can run dfu_util as a regular user.

### 2.1.4 Production Build

To build a bitstream image for the MultiMod II board itself, change to the | mmj1boot
subdirectory then execute the ./compile script. Use the | build/multiboot.bin | file to program the
MultiMod II flash memory.

MultiMod II Board Programming With The CH341A

First, if not already present, install IMSProg using the commands

sudo add-apt-repository ppa:bigmdm/imsprog sudo apt update sudo apt install imsprog
Using the programming adapter board, connect the header cable to the MultiMod II header and to the programming adapter board. The red orientation stripe should be at the top of the MultiMod II header and at the top of the programming board header. Put the pins of the adapter board in the lower half of the CH431A programmer socket, then plug the programmer
into a USB socket. The programmer presence can be verified with the | lsusb | command and
should appear similarly to that below.

Bus 003 Device 053: ID 1a86:5512 Qin Heng Electronics CH341 in EPP/MEM/I2C mode, EPP/I2C adapter
The following command will bring up the program utility GUI (be sure you are in the dialout group)

IMSProg

2.1.4 Production Build

- 10/44 - | BSD 3-Clause "New" or "Revised" License

Pressing the | Detect | button should show the Winbond 16 MB SPI flash device with JEDEC ID EF
40 18. Use the Open button to read in the | multiboot.bin | file, then press Go to program the
bootloader into flash.

2.1.4 Production Build

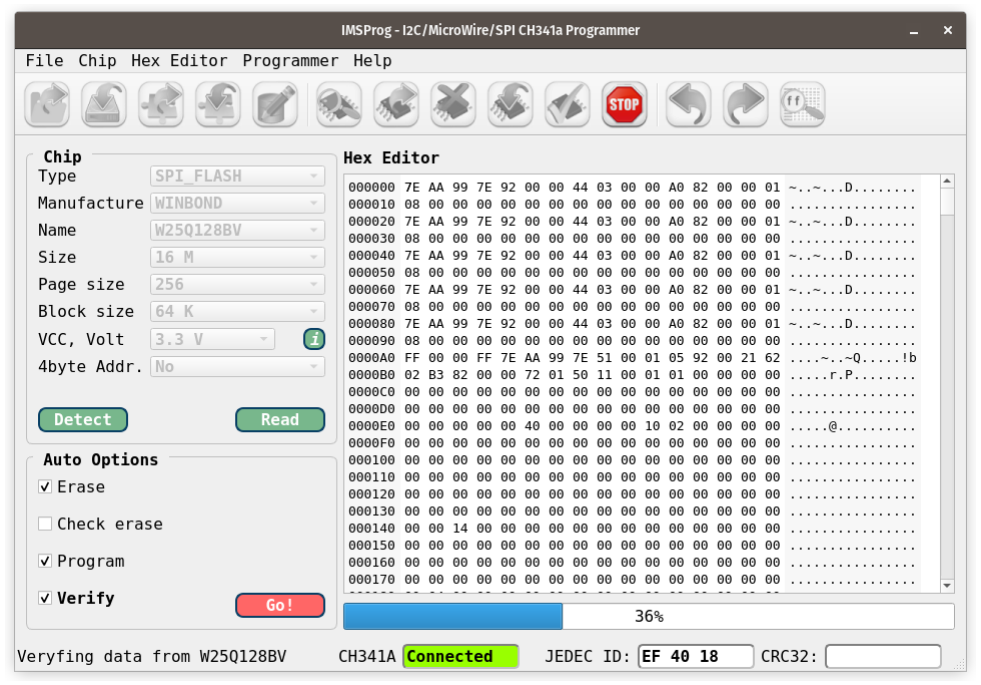
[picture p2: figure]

- 11/44 - | BSD 3-Clause "New" or "Revised" License

### 3. Build Files

### 3.1 The J1A Forth CPU Verilog File

### 3.1.1 iCE40UP5K FPGA Pin Assignments

The various MultiMod II signal connections are given in the table below. Signals are grouped by function rather than IO block/pin number.

HP-71B Bus Signals

Signal FPGA Name SG48 Pin ------------ ----------------- ------------ Data IO 0 IOB_0a 46 Data IO 1 IOB_2a 47 Data IO 2 IOB_5b 45 Data IO 3 IOB_3b_G6 44 StrobeN IOT_45a_G1 37 Cmd/DatN IOT_48b 36 DaisyIn IOT_44b 34
HP-71B Bus Level Shifter Control Signals

Signal FPGA Name SG48 Pin ------------ ----------------- ------------ Data Out Enb IOB_4a 48 Data In Enb IOT_51a 42 Cntrl In Enb IOB_50b 38
External Device Control Signals

Signal FPGA Name SG48 Pin ------------ ----------------- ------------ USB Pos IOT_38b 27 USB Neg IOT39a 26 USB Active IOB_6a 2 USB Pullup IOT_42b 31 Osc Enable IOT_46b_G0 35 Osc Output IOT_36b 25
External Flash Storage Signals

Signal FPGA Name SG48 Pin Flash Pin ------------ ----------------- ------------ ----------- ----- SPI_SO IOB_32a 14 DI (IO0) 5 SPI_SI IOB_33b 17 DO (IO1) 2 SPI_SCK IOB_34a 15 CLK 6 SPI_SS IOB_35b 16 /CS 1 GPIO IOB_24a 13 IO3 (/HOLD) 7 GPIO IOB_25b_G3 20 IO2 (/WP) 3

### 3.1.2 CPU External Signal Modifications

The J1A module definition was modified to include an output pin for the external clock
oscillator enable signal. The | clk_en | signal should be set to logic high by default.
The pins associated with the USB data signals and pullup are | usb_dn | , | usb_dp | , and | usb_pu | .
Additionally there is a | usb_activ | signal that indicates power is being supplied by the USB C
connector and therefore serves as a host detection signal.

The header is

module top ( input clki, // 48 MHz clock input output clk_en, // Enable external clock inout data_1, // Four user pins inout data_2, inout data_3, inout data_4, output rgb0, // LED outputs output rgb1, output rgb2, output spi_cs, // SPI Flash output spi_clk, inout spi_miso, inout spi_mosi, inout spi_io2, inout spi_io3, inout usb_dp, // USB pins inout usb_dn, output usb_dp_pu, input usb_activ );
Note that the four user pins | data_(1,2,3,4) | are bidirectional with separate input and output
registers in the I/O address space, along with a direction register that indicates whether they
are inputs or outputs.
3. Build Files
- 12/44 - | BSD 3-Clause "New" or "Revised" License

The three RGB pins could be removed for power saving reasons, though doing so would require further modification to the Verilog source to remove references to the signals. The pins are unconnected to any external device.

Note that the SPI signals | spi_miso | , | spi_mosi | , | spi_io2 | , and | spi_io3 | are defined as bidirectional.
These four signals now use the same SB_IO definitions as the four data signals. Normally
spi_miso | is set as an input and the other three are outputs. The | spi_io2 | (WP/) and | spi_io3
(HOLD/) default to logic 1 while the SPI flash communication is in Standard transfer mode.

One set of external signals currently missing from the module header are those that interface to control inputs from the 71B bus. These signals are named and assigned to FPGA pins in the pcf file, and eventually need to be incorporated for a J1A Forth implementation operating in production mode within the 71B card reader cavity.

### 3.1.3 CPU Internal Modifications

Changes to the j1a Verilog design were made include

Support for bidirectional SPI signals to enable Dual and Quad data transfers,
Warm Boot support to allow both bootloader and HP-71B embedded configurations, Changes to the I/O address space to support the above enhancements.

The I/O address modifications are

Address Read Access Write Access ------- ----------- ------------ $0100 SPI signals SPI signals $0101 SPIO direction $0200 USB status Warm Boot Ctl

IO Address $0100, SPI Read/Write +------+------+------+------+------+------+ | CLK | CS | IO3 | IO2 | MOSI | MISO | +-----5+-----4+-----3+-----2+-----1+-----0+ IO Address $0101, SPI Direction 1:output, 0:input +------+------+------+------+ | IO3 | IO2 | MOSI | MISO | +-----3+-----2+-----1+-----0+
The SPI signals are arranged in such a fashion to make it easy to support Dual and Quad mode
transfers. The SPI Direction register is by default set to the Standard transfer mode
configuration in which MISO is an input from the flash device and the remaining three
signals are outputs from the FPGA to the flash device.
IO Address $0200 USB Active/State Read Boot Write +------+------+------+ +------+------+------+ | ACTV | P_TX | N_TX | | BOOT | S1 | S0 | +-----2+-----1+-----0+ +-----2+-----1+-----0+
The Warm Boot control register | BOOTCTL | specifies which of four bitstream images are to be
loaded using the lower two bits of the register ('00' for the bootloader, '01' for the HP-71B
embedded configuration). Bit 02, when set to logic 1, will initiate the boot sequence.
The USB State includes the status of the USB data pins | USB-P | and | USB-N | along with the
usb_activ | signal that indicates power is present on the USB C connector.

•
•
•

3.1.3 CPU Internal Modifications

- 13/44 - | BSD 3-Clause "New" or "Revised" License

### 3.2 The MultiMod II Pin Definitions

The pin assignments in the | multimod-evt.pcf | file map the signals declared in the module header
of | j1a.v | to actual pins in the Lattice FPGA SG48 package.

### 3.2.1 Pin Assignments

The | pmod_(1,2,3,4) | names match those declared in the j1a.v module declaration and will need
to be renamed in both files to something like the | Bio(0,1,2,3) | names found on the MultiMod II
schematic.

set_io rgb0 39 set_io rgb1 40 set_io rgb2 41 set_io pmod_1 46 set_io pmod_2 47 set_io pmod_3 45 set_io pmod_4 44 set_io data_0 46 set_io data_1 47 set_io data_2 45 set_io data_3 44 set_io to71 48 set_io from71 42 set_io ctrl71 38 set_io din71 34 set_io cdn71 36 set_io strn71 37 set_io spi_mosi 17 set_io spi_miso 14 set_io spi_clk 15 set_io spi_io2 20 set_io spi_io3 13 set_io spi_cs 16 set_io usb_dn 26 set_io usb_dp 27 set_io usb_dp_pu 31 set_io clki 25 set_io clki_en 35

### 3.2.2 Trivia

In the original MultiMod II design the pins for | clki | and | clki_en | were swapped. This worked
fine for the mecrisp-ice design and so four test boards were ordered. It quickly turned out
after receiving the test boards that the two candidate bootloader designs could not be synthesized using this pin assignment, and so the pins were swapped, new boards were orderd, and the old test boards were scrapped.

3.2 The MultiMod II Pin Definitions

- 14/44 - | BSD 3-Clause "New" or "Revised" License

### 4. Functionality

### 4.1 Features and Requirements for the MultiMod II Bootloader

As an accessory for the HP-71B, the MultiMod II is meant to provide both ROM and RAM plugin modules. All known ROMs should be available for access by a MultiMod II owner. The owner should also be able to plug in RAM modules, either in merged form or as independent RAM (IRAM). The content of IRAM modules should also be able to be saved to flash memory so its content can be accessed at a later time.

In addition to providing regular relocatable ROM and RAM modules, the MultiMod II will also support fixed memory at two locations; a fixed hard ROM at location $E0000 and a takeover ROM at location $00000. The former is used by the Forth/Assembler ROM among others. The latter requires a separate shorting module in Port 1.

### 4.1.1 Bootloader

The Forth bootloader serves three purposes; to act as a bootloader that updates the MultiMod II production configuration under user control, to transfer files between the MultiMod II and a user host PC, and to develop Forth applications for use by the production Forth CPU in the HP-71B.

First, a hardware modification to the mecrisp-ice J1a CPU is needed to support warm boot. The modification allows a Forth program to initiate the warm boot process by supplying the address of a new bitstream pattern in flash and initiating the warm boot design confirguration replacement process.

Second, a user interface is needed for updating the FPGA production configuration and transferring files between the MultiMod II and the user host. Given the USB-based Forth console for communication, a terminal application like TeraTerm with a file transfer protocol like Kermit should be a sufficient client for the owner.

### 4.1.2 File Storage

Transferring files implies a file system, and that means some form of a file identification structure is needed. There are a number of open source flash file systems, but these assume small sector sizes (256/512 bytes) and plenty of host RAM. Neither condition is true for the MultiMod II where flash sector size is 4KB and only a fraction of the 15KB Forth dictionary is available for scratch space.

4. Functionality
- 15/44 - | BSD 3-Clause "New" or "Revised" License

The 16MB flash memory will be treated as a structure of 1024 blocks of 16KB each, where 16KB is the size of a Forth dictionary image or a size multiple of HP-71B ROM and RAM images.

Transfer of ROM image data in the MultiMod was by sending ASCII Hex representation of ROM data via a serial port. While this mode is still supported by the MultiMod II, the Kermit protocol will be used to transfer raw binary image files between the MultiMod II flash and a host PC. This protocol is also suitable for transferring updates to the production FPGA bitstream image.

### 4.1.3 Forth Development

There is little reason to develop Forth applications on the HP-71B itself when one can interact with the USB-based Forth console from a host using a terminal client. Furthermore, adding words to the Forth dictionary is a simple matter of sending a text file containing Forth definitions via the client. Thus, text development can be performed on the host, and a target dictionary can be saved to flash for later use in the HP-71B production environment.

### 4.1.4 Optional: HP-71B Emulation

If an owner wishes to develop a Forth application that can interact with the HP-71B in actual production operation, then some means is needed to simulate the 71B behaviour. One example would be to develop words that can interact with and modify an IRAM filesystem. A Forth application could then read and write data to local files in their FPGA SPRAM environment.

4.1.3 Forth Development

- 16/44 - | BSD 3-Clause "New" or "Revised" License

### 4.2 MultiMod II Flash Memory

The MultiMod II board has a 16MB Winbond flash device. When the FPGA exits power-up or reset, it reads its initial configuration bitstream from flash starting at address 0. It can optionally read alternative configuration bitstreams from other locations in flash, a process known as warm boot.

Flash memory is a byte-serial device rather than random access memory. A flash memory location must first be erased (all one's) before it can be written. The smallest block of flash that can be erased is 4 kilobytes. A read or write operation is always preceded by a command byte followed by a three byte (24-bit) memory address. Data can then be streamed to or from the flash device on a bit serial basis. The design of the MultiMod II allows an optional quad serial transfer interface.

The MultiMod II treats its 16 MB flash memory as a array of 1024 blocks of 16 KB size, with each block on a 16 KB address boundary. The flash memory is divided into three sections; section one for FPGA bitstreams and their associated data, section two for Forth dictionary images and data files, and the remaining third section for 71B ROM and IRAM images. ROM and IRAM images are 1, 2, or 4 blocks in size (16/32/64 KB).

Need a picture here of flash memory and sector addressing

### 4.2.1 Boot Section

The first megabyte of flash memory is reserved for configuration bitstreams as well as any data associated with a given FPGA configuration. In the foboot bootloader, the starting address of a bitstream varies according to post-boot data requirements, but roughly $020000 (128KB) is reserved for each bitstream. For the MultiMod II, four bitstream areas will be reserved in the lower half of the boot section, with the upper half serving as optional data storage for a given bitstream device.

### 4.2.2 Forth Section

The J1a Forth CPU has its dictionary in the 15KB dual port RAM of the Lattice FPGA. There are load and save commands which allow the dictionary to be written to flash or read from flash in its entirety. This gives a programmer the ability to develop applications and save them to flash for later use.

4.2 MultiMod II Flash Memory

- 17/44 - | BSD 3-Clause "New" or "Revised" License

The second megabyte of flash memory is reserved for Forth dictionary images. Since an image occupies a 16KB block of flash, the Forth Section has room for 64 dictionary images. The first two blocks are reserved for a directory of images and a scratch block for image manipulation. The remaining 62 blocks store dictionary images.

### 4.2.3 HP-71B Section

The remaining 14MB of flash is reserved for ROM images and IRAM images. These images are multiples of 16KB in size, hence like the Forth Section storage is divided into 768 blocks. The first two of these blocks are reserved for a directory of images and a scratch block for image manipulation.

4.2.3 HP-71B Section

- 18/44 - | BSD 3-Clause "New" or "Revised" License

### 5. File System

### 5.1 MultiMod II Flash File System

Although a MultiMod II owner developing Forth applications might be able to keep track of in which block number a dictionary is stored, the task is far more difficult for the many HP-71B ROM/IRAM images stored in flash. Each image varies in size (16KB, 32KB, 64KB), access (Read-Only, Read-Write), and type (Forth, ROM, hard ROM, IRAM). There may even be different versions of ROMs, as with the MATH ROM.

Thus a file system is needed to support creating, deleting, or renaming a storage entity. In the case of both Forth dictionaries and HP-71B memories, the supported operations are as follows

New - For the HP-71B a new IRAM can be created by giving a name and size.
Load - A named image is loaded into memory.
Save - A Forth dictionary image or a HP-71B IRAM image in memory can be saved to flash under its existing name (Save), or can be saved with a new name (Save As) so as not to overwrite the old image.

### 5.1.1 Directory Structure

A directory consists of 1024 directory entries in a 16KB flash block. The structure of an individual entry is defined in the next section. Since new entries can only be written to previously erased sections of the flash block, new or modified entries are written after the last entry in the directory list.

Entries grow upward within the directory block, with deleted entries marked as reclaimable. When updating an existing HP771B ROM/IRAM image, the size of the image remains the same as when the image directory entry was first created. That is, the resizing of an image is not supported.

### 5.1.2 Directory Entry

A directory entry is sixteen bytes in length, with twelve bytes devoted to the entry object name, two bytes to the image starting block number, and two bytes devoted to the attributes of the object. To support directory relocatability, the image starting block number is a offset from the beginning block of the directory itself.

•
•
•
5. File System
- 19/44 - | BSD 3-Clause "New" or "Revised" License

Flash bytes are all ones when erased, so writing to flash consists of setting ones to zeros in a given byte. If bits are considered flags with default value set to one, then a bit in one of the attribute bytes can be forced to zero to indicate the entry is no longer valid.

### 5.1.3 Directory Operations

As mutable images are updated and stored to flash, the most recent entry for an image is located at the upper end of active, unerased flash. Thus directory search starts at the most recently written directory entry, working downward towards the beginning of a directory block.

Directory entries and images both grow upwards within the flash storage allocated to them. Entries and/or images eventually reach the top of their allocated storage area, and so entries and images that are no longer valid must be eliminated in a process called packing.

### 5.1.4 Directory/Storage Packing

The packing process begins by scanning upwards in the directory searching for reclaimable entries. For each such entry, the 16KB blocks making up the image that the directory entry points to are erased. This erased space will later be occupied by valid images as part of the packing process.

Directory packing involves copying valid directory entries over to an erased scratch block the same size as the directory block. As directory entries are copied, their corresponding images they point to are also moved downward in flash address space.

Downward movement of images involves keeping track of the lowest erased block, then copying the image one block at a time. Each image block copied downward is erased after the copy completes. This step is necessary not only to provide room for images above the current image, but also to handle the case when there are not enough empty blocks below the image to hold the complete image. Erasing blocks as they are copied provides the needed space for subsequent image blocks.

5.1.3 Directory Operations

- 20/44 - | BSD 3-Clause "New" or "Revised" License

### 5.2 Directory Implementation

The following provides implementation detail for an image directory. As per the previous section, a directory occupies a single 16KB block of flash memory, and is divided into 1024 directory entries of 16 bytes each. A directory is thus able to addess the entirety of flash memory, which itself is divided into 1024 images blocks of 16KB each.

Multiple directories and their associated image blocks can exist in flash. The initial implementation will have separate directories for Forth dictionary images and HP-71B ROM/ IRAM images. The bulk of flash storage will be allocated to HP-71B images, which can be up to 14 MB. The base implementation will have only these two directories.
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

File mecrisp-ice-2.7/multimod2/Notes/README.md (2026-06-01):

# MultiMod II Bootloader Notes
These files are part of a mkdocs markup document. To view the notes, run the following command in the Notes directory

mkdocs serve [>/dev/null 2>/dev/null]

The optional parameters in the brackets serve to divert status data from the server away from the console. Once the server has started, open the following URL in a browser of choice

https://127.0.0.1:8000/

For more information on mkdocs, including installation and use, see
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

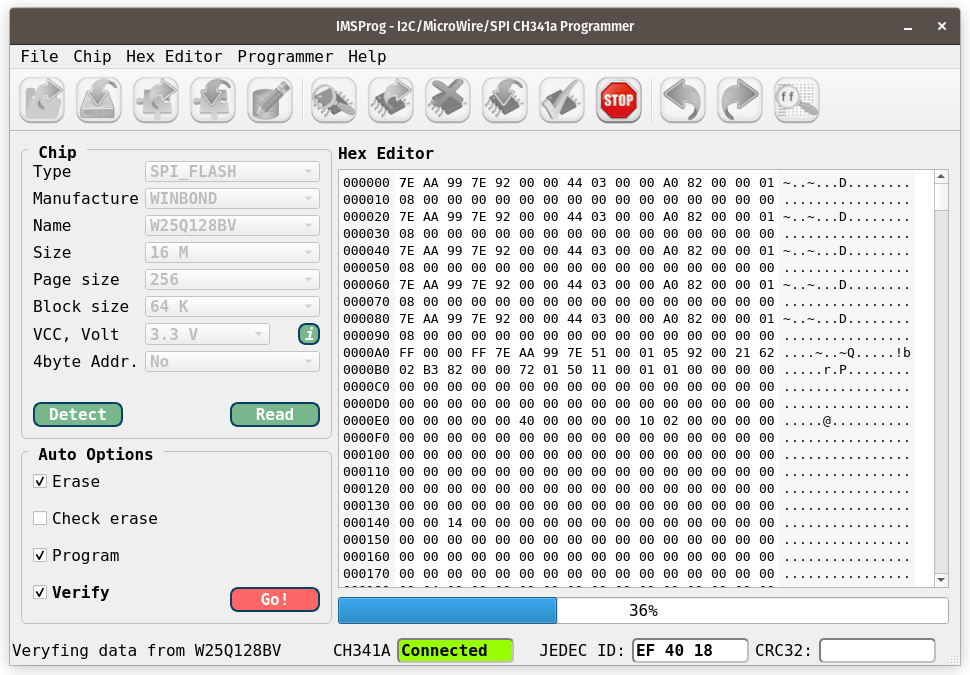
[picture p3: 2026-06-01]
mecrisp-ice-2.7/multimod2/Notes/docs/img/IMSProg.png

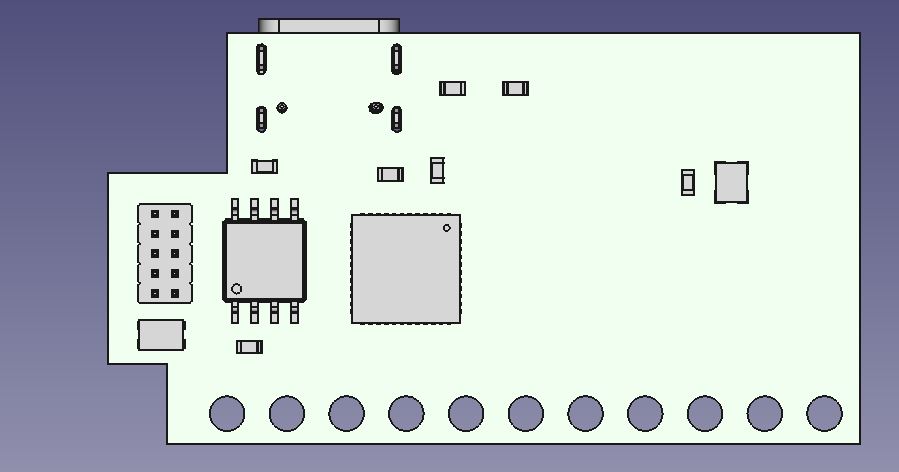
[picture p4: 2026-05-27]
board/MM2-top.JPG

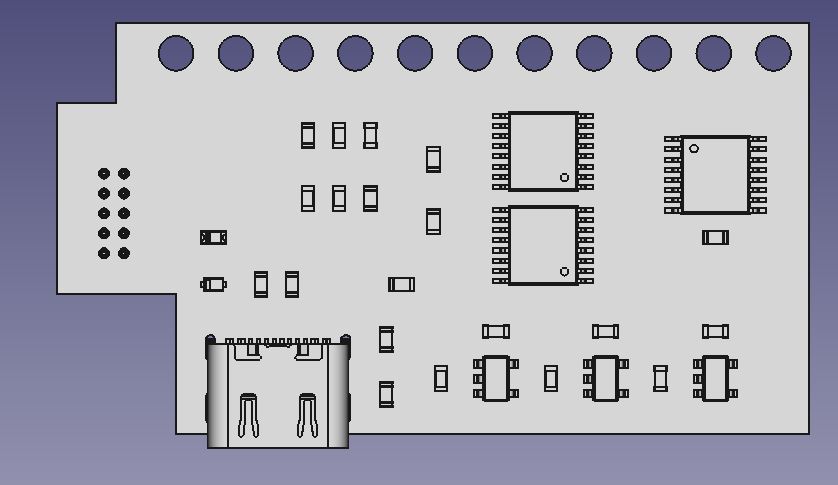
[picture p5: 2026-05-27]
board/MM2-bottom.JPG

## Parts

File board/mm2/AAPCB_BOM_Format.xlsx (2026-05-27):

Best Practice Bill of Materials (BOM) Template
1. Reference Designators - Place all designators with the same part number in one cell
2. Description Value Package - Advanced Assembly's system perfers this to be combined into one cell
3. Alternate Part Numbers - Place in additional columns to the right on the same line
4. Do Not Install (DNI) Parts - Indicate quantity zero and/or add DNI column
5. Notes - Place in additional column on the same line
6. Refrain from using merged cells
7. Mfg - If you require a specific manufacturer, specify here
*Please contact your account executive with any questions.*
 |  |  |  | êAuto-populates as you fill in the previous cellsê
Mfg Part # | Description | Value | Pkg | Description Value Pkg *AAPCB Format* | Ref. Des. | Qty | DNI | Notes | Mfg (Optional) | Vendor (Optional) | Vendor Part # (Optional) | Alternate Mfg Part # (Optional) | Type (Optional)
C1608X5R1A105M080AC | CAP CER | 100 nF 10V X5R 20% | 0603 SMD |  | C1, C2, C3, C4, C5 | 5 |  |  | TDK | Mouser
885012106010' | CAP CER | 1 uF 10V X5R 20% | 0603 SMD | CAP CER 1 uF 10V X5R 20% 0603 SMD | C6, C7, C8, C9, C10, C11, C12 | 7 |  |  | WURTH | Mouser
CGB3B1X5R1A475M055AC | CAP CER | 4.7 uF 10V X5R 20% | 0603 SMD | CAP CER 4.7 uF 10V X5R 20% 0603 SMD | C13 | 1 |  | EOL | TDK | Mouser
CDBU00340 | SCHOTTKY DIODE | 30mA 40V | 0603 SMD | SCHOTTKY DIODE 30mA 40V 0603 SMD | D1, D2 | 2 |  |  | COMCHIP | Mouser
DX07S016JA1R1500 | USB CONNECTOR |  |  | USB CONNECTOR | J2 | 1 |  |  | JAE | Mouser
20021111-00010T4LF | PIN HEADER | 2x5 1.27 MM PITCH |  | PIN HEADER 2x5 1.27 MM PITCH | J3 | 1 |  |  |  | Digi-Key
ERJ-3RSFR10V | RES | 0.1 OHM CURR SENSE | 0603 SMD | RES 0.1 OHM CURR SENSE 0603 SMD | R1 | 1 |  |  |  | Mouser
CPF0603F2R21C1 | RES | 22 OHM 1% | 0603 SMD | RES 22 OHM 1% 0603 SMD | R2, R3 | 2 |  |  |  | Mouser
CPF0603F100RC1 | RES | 100 OHM 1% | 0603 SMD | RES 100 OHM 1% 0603 SMD | R4 | 1 |  |  |  | Mouser
CPF0603F5K11C1 | RES | 5.1K OHM 1% | 0603 SMD | RES 5.1K OHM 1% 0603 SMD | R5, R6 | 2 |  |  |  | Mouser
5-1879337-9 | RES | 10K OHM 1% | 0603 SMD | RES 10K OHM 1% 0603 SMD | R7, R8, R9 | 3 |  |  |  | Mouser
CPF0603F49K9C1 | RES | 49.9K OHM 1% | 0603 SMD | RES 49.9K OHM 1% 0603 SMD | R10 | 1 |  |  |  | Mouser
CPF0603F100KC1 | RES | 100K OHM 1% | 0603 SMD | RES 100K OHM 1% 0603 SMD | R11, R12, R13, R15 | 4 |  |  |  | Mouser
SKSVCBE010 | SWITCH | TACTILE | SMD | SWITCH TACTILE SMD | S1 | 1 |  |  | ALPS | Mouser
ICE40UP5K-SG48I | LATTICE FPGA | ICE40 ULTRA PLUS | QFN-48 | LATTICE FPGA ICE40 ULTRA PLUS QFN-48 | U1 | 1 |  |  | LATTICE | Mouser
W25Q128JVS | SPI FLASH | 16 MB | SOIC-8 | SPI FLASH 16 MB SOIC-8 | U2 | 1 |  |  | WINBOND | Mouser
CD40109BPWR | LEVEL SHIFTER | QUAD L-H | TSSOP-16 | LEVEL SHIFTER QUAD L-H TSSOP-16 | U3, U4, U5 | 3 |  |  | TI | Mouser
AP2127K-1.2TRG1 | LDO REGULATOR | 1.2V 300mA | SOT-23-5 SMD | LDO REGULATOR 1.2V 300mA SOT-23-5 SMD | U7 | 1 |  |  | DIODES INC | Mouser
AP2127K-3.3TRG1 | LDO REGULATOR | 3.3V 300mA | SOT-23-5 SMD | LDO REGULATOR 3.3V 300mA SOT-23-5 SMD | U8 | 1 |  |  | DIODES INC | Mouser
AP2127K-2.5TRG1 | LDO REGULATOR | 2.5V 300mA | SOT-23-5 SMD | LDO REGULATOR 2.5V 300mA SOT-23-5 SMD | U9 | 1 |  |  | DIODES INC | Mouser
ECS-2520MV-480-DN-TR | CLOCK OSC | 48 MHZ | SMD | CLOCK OSC 48 MHZ SMD | X1 | 1 |  |  | ECS | Mouser

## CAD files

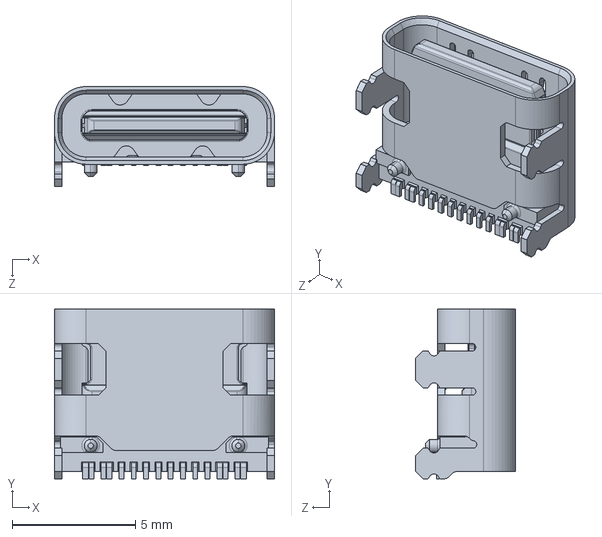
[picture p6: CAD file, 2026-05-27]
board/MM2.step
8.94 x 6.90 x 4.06 mm

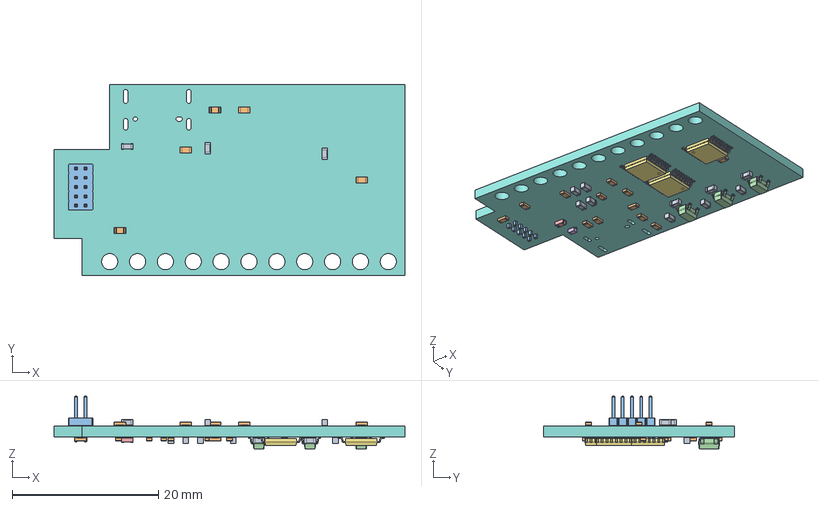
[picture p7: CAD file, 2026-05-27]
board/mm2/mm2.step
48.0 x 26.2 x 7.23 mm
C_0603_1608Metric x 13
R_0603_1608Metric x 17
PinHeader_2x05_P1.27mm_Vertical
SOT-23-5 x 3
D_0603_1608Metric
D_SOD-523 x 2
TSSOP-16_4.4x5mm_P0.65mm x 3
mm2_PCB

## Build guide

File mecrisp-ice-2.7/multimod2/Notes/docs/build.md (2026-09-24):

# MultiMod II Production Build Instructions
These instructions assume a Linux build environment, specifically [Pop!_OS](https://pop.system76.com/), a Debian variant. Other Linux distributions are likely sufficient if they are supported by the toolchains used herein. The author has used WSL (Windows System for Linux) as well for early exploration.

## Setup
This version begins by building the design in the `multimod2` directory using
the [Fomu](https://www.crowdsupply.com/sutajio-kosagi/fomu) development platform's designer-provided toolset. The tar file containing the [icestorm tools](https://github.com/im-tomu/fomu-toolchain)
should be installed in /opt/fomu-toolchain-Linux. Place its bin subdirectory
FIRST in your PATH environment variable.

```export PATH=/opt/fomu-toolchain-Linux/bin:$PATH```

Use `sudo apt install gforth` to install an old version of gforth in order  to compile the [latest Gforth](https://gforth.org) source files. The older default version of gforth works fine, though I did build the latest version from
source just in case any significant changes or improvements to gforth occurred.

## Compilation and Synthesis
Within the `multimod2` directory use the `compile` command script to create an initial Forth dictionary image using `compilenucleus` and using the above icestorm toolset to synthesize the J1A CPU design. The resulting bitstream file, j1a.bin in the `build` directory, is copied over to the `mmj1boot` directory for inclusion in the multiboot bitstream build.

There is a correction made to the stock build scripts. An unrecognized option appears in the first command in the compile script that invokes yosys, the `-noabc9` option. The build completes successfully with this option removed.

The script needs a seed value when invoking the `nextpnr-ice40` place and route program. The value used (11) was determined by successively trying values, starting with 1, until a seed was found that allowed synthesis to complete with all clock constraints satisfied. At the end of the build, the bitstream file `j1a.dfu` will appear in the `multimod2` directory. Usable files for loading by the bootloader also appear as `j1a-prod.bin` and `j1a-prod.dat` in the `build` directory.

### Communication

Development and testing of the production bitstream is done within the bootloader environment with the MultiMod II connected to the development computer using a USB C cable. Instructions for using a specific Linux client to communicate with the bootloader is given here. The details can be used as a guideline if a different communications client (eg TeraTerm) is used.

Use ```minicom -b 115200 -D /dev/ttyACM0``` to connect to the Forth CPU. Note that you'll need to add yourself to the dialout group. An alternative terminal program is GTKTerm, which is more easily configurable.

Invoke minicom communication (control-A Z) then set lineWrap on/off (control-A Z W) followed by Add Carriage Ret (control-A Z U). Set the comm parameters to 8N2 (control-A Z P X). You'll need to add some delay to each character sent by minicom to the Forth console via the terminal settings (control-A Z T). Set the character send delay to 1 milliseconds and the line end delay to 50 milliseconds. **The same character delay will be needed by other terminal emulators, such as TeraTerm.**

***For the above settings to work properly, use the `dint` command at the start of your working session to disable interrupts.***

## Production Build
Use the `compile` command to build a production bitstream image for the MultiMod II board. The build will copy the resulting **.bin** file to the `mmj1boot` directory and also create an ASCII file that can be transferred to the bootloader.

After connecting the MultiMod II to your host via a USB-C cable, establish communication as outlined in the previous section. Then execute the following command in the Forth console

```
1 bitstream   \ Program bitstream image slot 1
```

With minicom, use control-A Z, then S for Send. Select ascii transfer then highlight the `j1a-prod.dat` in the `build` directory. Press return to start the transfer and a second return to initiate flash programming. Programming the new production bitstream takes around six to eight seconds before the Forth *ok* response appears.

Once the production bitstream is loaded, use the following command to load the bitstream into the FPGA

```
5 warmboot
```

***ASCII transfers may in the future be augmented a with Kermit option***

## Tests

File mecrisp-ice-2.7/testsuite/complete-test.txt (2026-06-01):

\ ------------------------------------------------------------------------
\  These definitions have a different behaviour in Mecrisp-Ice:
\ ------------------------------------------------------------------------

:  variable ( -- ) 0 variable ;
: 2variable ( -- ) 0. 2variable ;

\ ------------------------------------------------------------------------
\  These CORE definitions are not part of Mecrisp-Ice for default:
\ ------------------------------------------------------------------------

: word ( c -- c-addr )
    begin
        source >r >in @ + c@ over =
        r> >in @ xor and
    while
        1 >in +!
    repeat

    parse
    dup BUF0 c!
    BUF0 1+ swap move
    BUF0
;

\ : >number ( ud1 c-addr1 u1 -- ud2 c-addr2 u2 )
\     begin
\         dup
\     while
\         over c@ digit
\         0= if drop exit then
\         >r 2swap base @
\         tuck * >r um* r> + \ Inlined Swapforth ud* ( ud1 u -- ud2 )
\         r> s>d d+ 2swap
\         1 /string
\     repeat
\ ;

: chars ( u -- u ) ; 0 foldable
: char+ ( u -- u+1 ) 1+ ; 1 foldable

: erase ( addr u -- ) 0 fill ;

\ ------------------------------------------------------------------------
\  These CORE-EXT definitions are not part of Mecrisp-Ice for default:
\ ------------------------------------------------------------------------

: roll
    ?dup if
        swap >r
        1- recurse
        r> swap
    then
;

: .( ( -- )
    [char] ) parse type
; immediate

: pick
    ?dup if
        swap >r
        1- recurse
        r> swap
    else
        dup
    then
;

: 2>r ( x1 x2 -- ) ( R: -- x1 x2 )  r> -rot swap >r >r >r ;

: 2r> ( -- x1 x2 ) ( R: x1 x2 -- )
    postpone r>
    postpone r>
    postpone swap
; immediate

: 2r@ ( -- x1 x2 ) ( R: x1 x2 -- x1 x2 ) r> 2r> 2dup 2>r rot >r ;

\ ------------------------------------------------------------------------
\  These DOUBLE definitions are not part of Mecrisp-Ice for default:
\ ------------------------------------------------------------------------

 0 CONSTANT <FALSE>
-1 CONSTANT <TRUE>

: 2literal ( d -- )
    swap postpone literal postpone literal
; immediate

: d>s ( d -- n ) drop ;

\ From Wil Baden's "FPH Popular Extensions"
\ http://www.wilbaden.com/neil_bawd/fphpop.txt

: tnegate                           ( t . . -- -t . . )
    >r  2dup or dup if drop  dnegate 1  then
    r> +  negate ;

: t*                                ( d . n -- t . . )
                                    ( d0 d1 n)
    2dup xor >r                     ( r: sign)
    >r dabs r> abs
    2>r                             ( d0)( r: sign d1 n)
    r@ um* 0                        ( t0 d1 0)
    2r> um*                         ( t0 d1 0 d1*n .)( r: sign)
    d+                              ( t0 t1 t2)
    r> 0< if tnegate then ;

: t/                                ( t . . u -- d . )
                                    ( t0 t1 t2 u)
    over >r >r                      ( t0 t1 t2)( r: t2 u)
    dup 0< if tnegate then
    r@ um/mod                       ( t0 rem d1)
    rot rot                         ( d1 t0 rem)
    r> um/mod                       ( d1 rem' d0)( r: t2)
    nip swap                        ( d0 d1)
    r> 0< if dnegate then ;

: m*/  ( d . n u -- d . )  >r t*  r> t/ ;

\ ------------------------------------------------------------------------
\ For testing of the ansification layer. Slightly changed, some parts are commented out.
\ See original at https://github.com/gerryjackson/forth2012-test-suite/tree/master
\ ------------------------------------------------------------------------

\ From: John Hayes S1I
\ Subject: tester.fr
\ Date: Mon, 27 Nov 95 13:10:09 PST

\ (C) 1995 JOHNS HOPKINS UNIVERSITY / APPLIED PHYSICS LABORATORY
\ MAY BE DISTRIBUTED FREELY AS LONG AS THIS COPYRIGHT NOTICE REMAINS.
\ VERSION 1.2

\ 24/11/2015 Replaced Core Ext word <> with = 0=
\ 31/3/2015 Variable #ERRORS added and incremented for each error reported.
\ 22/1/09 The words { and } have been changed to T{ and }T respectively to
\ agree with the Forth 200X file ttester.fs. This avoids clashes with
\ locals using { ... } and the FSL use of }

HEX

\ SET THE FOLLOWING FLAG TO TRUE FOR MORE VERBOSE OUTPUT; THIS MAY
\ ALLOW YOU TO TELL WHICH TEST CAUSED YOUR SYSTEM TO HANG.
VARIABLE VERBOSE
   FALSE VERBOSE !
\   TRUE VERBOSE !

: EMPTY-STACK   \ ( ... -- ) EMPTY STACK: HANDLES UNDERFLOWED STACK TOO.
   DEPTH ?DUP IF DUP 0< IF NEGATE 0 DO 0 LOOP ELSE 0 DO DROP LOOP THEN THEN ;

VARIABLE #ERRORS 0 #ERRORS !

: ERROR      \ ( C-ADDR U -- ) DISPLAY AN ERROR MESSAGE FOLLOWED BY
      \ THE LINE THAT HAD THE ERROR.
   CR TYPE SOURCE TYPE       \ DISPLAY LINE CORRESPONDING TO ERROR
   EMPTY-STACK               \ THROW AWAY EVERY THING ELSE
   #ERRORS @ 1 + #ERRORS !
\   QUIT  \ *** Uncomment this line to QUIT on an error
;

VARIABLE ACTUAL-DEPTH         \ STACK RECORD
CREATE ACTUAL-RESULTS 20 CELLS ALLOT

: T{      \ ( -- ) SYNTACTIC SUGAR.
   ;

: ->      \ ( ... -- ) RECORD DEPTH AND CONTENT OF STACK.
   DEPTH DUP ACTUAL-DEPTH !      \ RECORD DEPTH
   ?DUP IF            \ IF THERE IS SOMETHING ON STACK
      0 DO ACTUAL-RESULTS I CELLS + ! LOOP \ SAVE THEM
   THEN ;

: }T      \ ( ... -- ) COMPARE STACK (EXPECTED) CONTENTS WITH SAVED
      \ (ACTUAL) CONTENTS.
   DEPTH ACTUAL-DEPTH @ = IF      \ IF DEPTHS MATCH
      DEPTH ?DUP IF         \ IF THERE IS SOMETHING ON THE STACK
         0  DO            \ FOR EACH STACK ITEM
           ACTUAL-RESULTS I CELLS + @   \ COMPARE ACTUAL WITH EXPECTED
           = 0= IF S" INCORRECT RESULT: " ERROR LEAVE THEN
         LOOP
      THEN
   ELSE               \ DEPTH MISMATCH
      S" WRONG NUMBER OF RESULTS: " ERROR
   THEN ;

: TESTING   \ ( -- ) TALKING COMMENT.
  SOURCE VERBOSE @
   IF DUP >R TYPE CR R> >IN !
   ELSE >IN ! DROP [CHAR] * EMIT
   THEN ;
\ From: John Hayes S1I
\ Subject: core.fr
\ Date: Mon, 27 Nov 95 13:10

\ (C) 1995 JOHNS HOPKINS UNIVERSITY / APPLIED PHYSICS LABORATORY
\ MAY BE DISTRIBUTED FREELY AS LONG AS THIS COPYRIGHT NOTICE REMAINS.
\ VERSION 1.2
\ THIS PROGRAM TESTS THE CORE WORDS OF AN ANS FORTH SYSTEM.
\ THE PROGRAM ASSUMES A TWO'S COMPLEMENT IMPLEMENTATION WHERE
\ THE RANGE OF SIGNED NUMBERS IS -2^(N-1) ... 2^(N-1)-1 AND
\ THE RANGE OF UNSIGNED NUMBERS IS 0 ... 2^(N)-1.
\ I HAVEN'T FIGURED OUT HOW TO TEST KEY, QUIT, ABORT, OR ABORT"...
\ I ALSO HAVEN'T THOUGHT OF A WAY TO TEST ENVIRONMENT?...

CR
TESTING CORE WORDS
HEX

\ ------------------------------------------------------------------------
TESTING BASIC ASSUMPTIONS

T{ -> }T               \ START WITH CLEAN SLATE
( TEST IF ANY BITS ARE SET; ANSWER IN BASE 1 )
T{ : BITSSET? IF 0 0 ELSE 0 THEN ; -> }T
T{  0 BITSSET? -> 0 }T      ( ZERO IS ALL BITS CLEAR )
T{  1 BITSSET? -> 0 0 }T      ( OTHER NUMBER HAVE AT LEAST ONE BIT )
T{ -1 BITSSET? -> 0 0 }T

\ ------------------------------------------------------------------------
TESTING BOOLEANS: INVERT AND OR XOR

T{ 0 0 AND -> 0 }T
T{ 0 1 AND -> 0 }T
T{ 1 0 AND -> 0 }T
T{ 1 1 AND -> 1 }T

T{ 0 INVERT 1 AND -> 1 }T
T{ 1 INVERT 1 AND -> 0 }T

0    CONSTANT 0S
0 INVERT CONSTANT 1S

T{ 0S INVERT -> 1S }T
T{ 1S INVERT -> 0S }T

T{ 0S 0S AND -> 0S }T
T{ 0S 1S AND -> 0S }T
T{ 1S 0S AND -> 0S }T
T{ 1S 1S AND -> 1S }T

T{ 0S 0S OR -> 0S }T
T{ 0S 1S OR -> 1S }T
T{ 1S 0S OR -> 1S }T
T{ 1S 1S OR -> 1S }T

T{ 0S 0S XOR -> 0S }T
T{ 0S 1S XOR -> 1S }T
T{ 1S 0S XOR -> 1S }T
T{ 1S 1S XOR -> 0S }T

\ ------------------------------------------------------------------------
TESTING 2* 2/ LSHIFT RSHIFT

( WE TRUST 1S, INVERT, AND BITSSET?; WE WILL CONFIRM RSHIFT LATER )
1S 1 RSHIFT INVERT CONSTANT MSB
T{ MSB BITSSET? -> 0 0 }T

T{ 0S 2* -> 0S }T
T{ 1 2* -> 2 }T
T{ 4000 2* -> 8000 }T
T{ 1S 2* 1 XOR -> 1S }T
T{ MSB 2* -> 0S }T

T{ 0S 2/ -> 0S }T
T{ 1 2/ -> 0 }T
T{ 4000 2/ -> 2000 }T
T{ 1S 2/ -> 1S }T            \ MSB PROPOGATED
T{ 1S 1 XOR 2/ -> 1S }T
T{ MSB 2/ MSB AND -> MSB }T

T{ 1 0 LSHIFT -> 1 }T
T{ 1 1 LSHIFT -> 2 }T
T{ 1 2 LSHIFT -> 4 }T
T{ 1 F LSHIFT -> 8000 }T         \ BIGGEST GUARANTEED SHIFT
T{ 1S 1 LSHIFT 1 XOR -> 1S }T
T{ MSB 1 LSHIFT -> 0 }T

T{ 1 0 RSHIFT -> 1 }T
T{ 1 1 RSHIFT -> 0 }T
T{ 2 1 RSHIFT -> 1 }T
T{ 4 2 RSHIFT -> 1 }T
T{ 8000 F RSHIFT -> 1 }T         \ BIGGEST
T{ MSB 1 RSHIFT MSB AND -> 0 }T      \ RSHIFT ZERO FILLS MSBS
T{ MSB 1 RSHIFT 2* -> MSB }T

\ ------------------------------------------------------------------------
TESTING COMPARISONS: 0= = 0< < > U< MIN MAX
0 INVERT         CONSTANT MAX-UINT
0 INVERT 1 RSHIFT      CONSTANT MAX-INT
0 INVERT 1 RSHIFT INVERT   CONSTANT MIN-INT
0 INVERT 1 RSHIFT      CONSTANT MID-UINT
0 INVERT 1 RSHIFT INVERT   CONSTANT MID-UINT+1

0S CONSTANT <FALSE>
1S CONSTANT <TRUE>

T{ 0 0= -> <TRUE> }T
T{ 1 0= -> <FALSE> }T
T{ 2 0= -> <FALSE> }T
T{ -1 0= -> <FALSE> }T
T{ MAX-UINT 0= -> <FALSE> }T
T{ MIN-INT 0= -> <FALSE> }T
T{ MAX-INT 0= -> <FALSE> }T

T{ 0 0 = -> <TRUE> }T
T{ 1 1 = -> <TRUE> }T
T{ -1 -1 = -> <TRUE> }T
T{ 1 0 = -> <FALSE> }T
T{ -1 0 = -> <FALSE> }T
T{ 0 1 = -> <FALSE> }T
T{ 0 -1 = -> <FALSE> }T

T{ 0 0< -> <FALSE> }T
T{ -1 0< -> <TRUE> }T
T{ MIN-INT 0< -> <TRUE> }T
T{ 1 0< -> <FALSE> }T
T{ MAX-INT 0< -> <FALSE> }T

T{ 0 1 < -> <TRUE> }T
T{ 1 2 < -> <TRUE> }T
T{ -1 0 < -> <TRUE> }T
T{ -1 1 < -> <TRUE> }T
T{ MIN-INT 0 < -> <TRUE> }T
T{ MIN-INT MAX-INT < -> <TRUE> }T
T{ 0 MAX-INT < -> <TRUE> }T
T{ 0 0 < -> <FALSE> }T
T{ 1 1 < -> <FALSE> }T
T{ 1 0 < -> <FALSE> }T
T{ 2 1 < -> <FALSE> }T
T{ 0 -1 < -> <FALSE> }T
T{ 1 -1 < -> <FALSE> }T
T{ 0 MIN-INT < -> <FALSE> }T
T{ MAX-INT MIN-INT < -> <FALSE> }T
T{ MAX-INT 0 < -> <FALSE> }T

T{ 0 1 > -> <FALSE> }T
T{ 1 2 > -> <FALSE> }T
T{ -1 0 > -> <FALSE> }T
T{ -1 1 > -> <FALSE> }T
T{ MIN-INT 0 > -> <FALSE> }T
T{ MIN-INT MAX-INT > -> <FALSE> }T
T{ 0 MAX-INT > -> <FALSE> }T
T{ 0 0 > -> <FALSE> }T
T{ 1 1 > -> <FALSE> }T
T{ 1 0 > -> <TRUE> }T
T{ 2 1 > -> <TRUE> }T
T{ 0 -1 > -> <TRUE> }T
T{ 1 -1 > -> <TRUE> }T
T{ 0 MIN-INT > -> <TRUE> }T
T{ MAX-INT MIN-INT > -> <TRUE> }T
T{ MAX-INT 0 > -> <TRUE> }T

T{ 0 1 U< -> <TRUE> }T
T{ 1 2 U< -> <TRUE> }T
T{ 0 MID-UINT U< -> <TRUE> }T
T{ 0 MAX-UINT U< -> <TRUE> }T
T{ MID-UINT MAX-UINT U< -> <TRUE> }T
T{ 0 0 U< -> <FALSE> }T
T{ 1 1 U< -> <FALSE> }T
T{ 1 0 U< -> <FALSE> }T
T{ 2 1 U< -> <FALSE> }T
T{ MID-UINT 0 U< -> <FALSE> }T
T{ MAX-UINT 0 U< -> <FALSE> }T
T{ MAX-UINT MID-UINT U< -> <FALSE> }T

T{ 0 1 MIN -> 0 }T
T{ 1 2 MIN -> 1 }T
T{ -1 0 MIN -> -1 }T
T{ -1 1 MIN -> -1 }T
T{ MIN-INT 0 MIN -> MIN-INT }T
T{ MIN-INT MAX-INT MIN -> MIN-INT }T
T{ 0 MAX-INT MIN -> 0 }T
T{ 0 0 MIN -> 0 }T
T{ 1 1 MIN -> 1 }T
T{ 1 0 MIN -> 0 }T
T{ 2 1 MIN -> 1 }T
T{ 0 -1 MIN -> -1 }T
T{ 1 -1 MIN -> -1 }T
T{ 0 MIN-INT MIN -> MIN-INT }T
T{ MAX-INT MIN-INT MIN -> MIN-INT }T
T{ MAX-INT 0 MIN -> 0 }T

T{ 0 1 MAX -> 1 }T
T{ 1 2 MAX -> 2 }T
T{ -1 0 MAX -> 0 }T
T{ -1 1 MAX -> 1 }T
T{ MIN-INT 0 MAX -> 0 }T
T{ MIN-INT MAX-INT MAX -> MAX-INT }T
T{ 0 MAX-INT MAX -> MAX-INT }T
T{ 0 0 MAX -> 0 }T
T{ 1 1 MAX -> 1 }T
T{ 1 0 MAX -> 1 }T
T{ 2 1 MAX -> 2 }T
T{ 0 -1 MAX -> 0 }T
T{ 1 -1 MAX -> 1 }T
T{ 0 MIN-INT MAX -> 0 }T
T{ MAX-INT MIN-INT MAX -> MAX-INT }T
T{ MAX-INT 0 MAX -> MAX-INT }T

\ ------------------------------------------------------------------------
TESTING STACK OPS: 2DROP 2DUP 2OVER 2SWAP ?DUP DEPTH DROP DUP OVER ROT SWAP

T{ 1 2 2DROP -> }T
T{ 1 2 2DUP -> 1 2 1 2 }T
T{ 1 2 3 4 2OVER -> 1 2 3 4 1 2 }T
T{ 1 2 3 4 2SWAP -> 3 4 1 2 }T
T{ 0 ?DUP -> 0 }T
T{ 1 ?DUP -> 1 1 }T
T{ -1 ?DUP -> -1 -1 }T
T{ DEPTH -> 0 }T
T{ 0 DEPTH -> 0 1 }T
T{ 0 1 DEPTH -> 0 1 2 }T
T{ 0 DROP -> }T
T{ 1 2 DROP -> 1 }T
T{ 1 DUP -> 1 1 }T
T{ 1 2 OVER -> 1 2 1 }T
T{ 1 2 3 ROT -> 2 3 1 }T
T{ 1 2 SWAP -> 2 1 }T

\ ------------------------------------------------------------------------
TESTING >R R> R@

T{ : GR1 >R R> ; -> }T
T{ : GR2 >R R@ R> DROP ; -> }T
T{ 123 GR1 -> 123 }T
T{ 123 GR2 -> 123 }T
T{ 1S GR1 -> 1S }T   ( RETURN STACK HOLDS CELLS )

\ ------------------------------------------------------------------------
TESTING ADD/SUBTRACT: + - 1+ 1- ABS NEGATE

T{ 0 5 + -> 5 }T
T{ 5 0 + -> 5 }T
T{ 0 -5 + -> -5 }T
T{ -5 0 + -> -5 }T
T{ 1 2 + -> 3 }T
T{ 1 -2 + -> -1 }T
T{ -1 2 + -> 1 }T
T{ -1 -2 + -> -3 }T
T{ -1 1 + -> 0 }T
T{ MID-UINT 1 + -> MID-UINT+1 }T

T{ 0 5 - -> -5 }T
T{ 5 0 - -> 5 }T
T{ 0 -5 - -> 5 }T
T{ -5 0 - -> -5 }T
T{ 1 2 - -> -1 }T
T{ 1 -2 - -> 3 }T
T{ -1 2 - -> -3 }T
T{ -1 -2 - -> 1 }T
T{ 0 1 - -> -1 }T
T{ MID-UINT+1 1 - -> MID-UINT }T

T{ 0 1+ -> 1 }T
T{ -1 1+ -> 0 }T
T{ 1 1+ -> 2 }T
T{ MID-UINT 1+ -> MID-UINT+1 }T

T{ 2 1- -> 1 }T
T{ 1 1- -> 0 }T
T{ 0 1- -> -1 }T
T{ MID-UINT+1 1- -> MID-UINT }T

T{ 0 NEGATE -> 0 }T
T{ 1 NEGATE -> -1 }T
T{ -1 NEGATE -> 1 }T
T{ 2 NEGATE -> -2 }T
T{ -2 NEGATE -> 2 }T

T{ 0 ABS -> 0 }T
T{ 1 ABS -> 1 }T
T{ -1 ABS -> 1 }T
T{ MIN-INT ABS -> MID-UINT+1 }T

\ ------------------------------------------------------------------------
TESTING MULTIPLY: S>D * M* UM*

T{ 0 S>D -> 0 0 }T
T{ 1 S>D -> 1 0 }T
T{ 2 S>D -> 2 0 }T
T{ -1 S>D -> -1 -1 }T
T{ -2 S>D -> -2 -1 }T
T{ MIN-INT S>D -> MIN-INT -1 }T
T{ MAX-INT S>D -> MAX-INT 0 }T

T{ 0 0 M* -> 0 S>D }T
T{ 0 1 M* -> 0 S>D }T
T{ 1 0 M* -> 0 S>D }T
T{ 1 2 M* -> 2 S>D }T
T{ 2 1 M* -> 2 S>D }T
T{ 3 3 M* -> 9 S>D }T
T{ -3 3 M* -> -9 S>D }T
T{ 3 -3 M* -> -9 S>D }T
T{ -3 -3 M* -> 9 S>D }T
T{ 0 MIN-INT M* -> 0 S>D }T
T{ 1 MIN-INT M* -> MIN-INT S>D }T
T{ 2 MIN-INT M* -> 0 1S }T
T{ 0 MAX-INT M* -> 0 S>D }T
T{ 1 MAX-INT M* -> MAX-INT S>D }T
T{ 2 MAX-INT M* -> MAX-INT 1 LSHIFT 0 }T
T{ MIN-INT MIN-INT M* -> 0 MSB 1 RSHIFT }T
T{ MAX-INT MIN-INT M* -> MSB MSB 2/ }T
T{ MAX-INT MAX-INT M* -> 1 MSB 2/ INVERT }T

T{ 0 0 * -> 0 }T            \ TEST IDENTITIES
T{ 0 1 * -> 0 }T
T{ 1 0 * -> 0 }T
T{ 1 2 * -> 2 }T
T{ 2 1 * -> 2 }T
T{ 3 3 * -> 9 }T
T{ -3 3 * -> -9 }T
T{ 3 -3 * -> -9 }T
T{ -3 -3 * -> 9 }T

T{ MID-UINT+1 1 RSHIFT 2 * -> MID-UINT+1 }T
T{ MID-UINT+1 2 RSHIFT 4 * -> MID-UINT+1 }T
T{ MID-UINT+1 1 RSHIFT MID-UINT+1 OR 2 * -> MID-UINT+1 }T

T{ 0 0 UM* -> 0 0 }T
T{ 0 1 UM* -> 0 0 }T
T{ 1 0 UM* -> 0 0 }T
T{ 1 2 UM* -> 2 0 }T
T{ 2 1 UM* -> 2 0 }T
T{ 3 3 UM* -> 9 0 }T

T{ MID-UINT+1 1 RSHIFT 2 UM* -> MID-UINT+1 0 }T
T{ MID-UINT+1 2 UM* -> 0 1 }T
T{ MID-UINT+1 4 UM* -> 0 2 }T
T{ 1S 2 UM* -> 1S 1 LSHIFT 1 }T
T{ MAX-UINT MAX-UINT UM* -> 1 1 INVERT }T

\ ------------------------------------------------------------------------
TESTING DIVIDE: FM/MOD SM/REM UM/MOD */ */MOD / /MOD MOD

T{ 0 S>D 1 FM/MOD -> 0 0 }T
T{ 1 S>D 1 FM/MOD -> 0 1 }T
T{ 2 S>D 1 FM/MOD -> 0 2 }T
T{ -1 S>D 1 FM/MOD -> 0 -1 }T
T{ -2 S>D 1 FM/MOD -> 0 -2 }T
T{ 0 S>D -1 FM/MOD -> 0 0 }T
T{ 1 S>D -1 FM/MOD -> 0 -1 }T
T{ 2 S>D -1 FM/MOD -> 0 -2 }T
T{ -1 S>D -1 FM/MOD -> 0 1 }T
T{ -2 S>D -1 FM/MOD -> 0 2 }T
T{ 2 S>D 2 FM/MOD -> 0 1 }T
T{ -1 S>D -1 FM/MOD -> 0 1 }T
T{ -2 S>D -2 FM/MOD -> 0 1 }T
T{  7 S>D  3 FM/MOD -> 1 2 }T
T{  7 S>D -3 FM/MOD -> -2 -3 }T
T{ -7 S>D  3 FM/MOD -> 2 -3 }T
T{ -7 S>D -3 FM/MOD -> -1 2 }T
T{ MAX-INT S>D 1 FM/MOD -> 0 MAX-INT }T
T{ MIN-INT S>D 1 FM/MOD -> 0 MIN-INT }T
T{ MAX-INT S>D MAX-INT FM/MOD -> 0 1 }T
T{ MIN-INT S>D MIN-INT FM/MOD -> 0 1 }T
T{ 1S 1 4 FM/MOD -> 3 MAX-INT }T
T{ 1 MIN-INT M* 1 FM/MOD -> 0 MIN-INT }T
T{ 1 MIN-INT M* MIN-INT FM/MOD -> 0 1 }T
T{ 2 MIN-INT M* 2 FM/MOD -> 0 MIN-INT }T
T{ 2 MIN-INT M* MIN-INT FM/MOD -> 0 2 }T
T{ 1 MAX-INT M* 1 FM/MOD -> 0 MAX-INT }T
T{ 1 MAX-INT M* MAX-INT FM/MOD -> 0 1 }T
T{ 2 MAX-INT M* 2 FM/MOD -> 0 MAX-INT }T
T{ 2 MAX-INT M* MAX-INT FM/MOD -> 0 2 }T
T{ MIN-INT MIN-INT M* MIN-INT FM/MOD -> 0 MIN-INT }T
T{ MIN-INT MAX-INT M* MIN-INT FM/MOD -> 0 MAX-INT }T
T{ MIN-INT MAX-INT M* MAX-INT FM/MOD -> 0 MIN-INT }T
T{ MAX-INT MAX-INT M* MAX-INT FM/MOD -> 0 MAX-INT }T

T{ 0 S>D 1 SM/REM -> 0 0 }T
T{ 1 S>D 1 SM/REM -> 0 1 }T
T{ 2 S>D 1 SM/REM -> 0 2 }T
T{ -1 S>D 1 SM/REM -> 0 -1 }T
T{ -2 S>D 1 SM/REM -> 0 -2 }T
T{ 0 S>D -1 SM/REM -> 0 0 }T
T{ 1 S>D -1 SM/REM -> 0 -1 }T
T{ 2 S>D -1 SM/REM -> 0 -2 }T
T{ -1 S>D -1 SM/REM -> 0 1 }T
T{ -2 S>D -1 SM/REM -> 0 2 }T
T{ 2 S>D 2 SM/REM -> 0 1 }T
T{ -1 S>D -1 SM/REM -> 0 1 }T
T{ -2 S>D -2 SM/REM -> 0 1 }T
T{  7 S>D  3 SM/REM -> 1 2 }T
T{  7 S>D -3 SM/REM -> 1 -2 }T
T{ -7 S>D  3 SM/REM -> -1 -2 }T
T{ -7 S>D -3 SM/REM -> -1 2 }T
T{ MAX-INT S>D 1 SM/REM -> 0 MAX-INT }T
T{ MIN-INT S>D 1 SM/REM -> 0 MIN-INT }T
T{ MAX-INT S>D MAX-INT SM/REM -> 0 1 }T
T{ MIN-INT S>D MIN-INT SM/REM -> 0 1 }T
T{ 1S 1 4 SM/REM -> 3 MAX-INT }T
T{ 2 MIN-INT M* 2 SM/REM -> 0 MIN-INT }T
T{ 2 MIN-INT M* MIN-INT SM/REM -> 0 2 }T
T{ 2 MAX-INT M* 2 SM/REM -> 0 MAX-INT }T
T{ 2 MAX-INT M* MAX-INT SM/REM -> 0 2 }T
T{ MIN-INT MIN-INT M* MIN-INT SM/REM -> 0 MIN-INT }T
T{ MIN-INT MAX-INT M* MIN-INT SM/REM -> 0 MAX-INT }T
T{ MIN-INT MAX-INT M* MAX-INT SM/REM -> 0 MIN-INT }T
T{ MAX-INT MAX-INT M* MAX-INT SM/REM -> 0 MAX-INT }T

T{ 0 0 1 UM/MOD -> 0 0 }T
T{ 1 0 1 UM/MOD -> 0 1 }T
T{ 1 0 2 UM/MOD -> 1 0 }T
T{ 3 0 2 UM/MOD -> 1 1 }T
T{ MAX-UINT 2 UM* 2 UM/MOD -> 0 MAX-UINT }T
T{ MAX-UINT 2 UM* MAX-UINT UM/MOD -> 0 2 }T
T{ MAX-UINT MAX-UINT UM* MAX-UINT UM/MOD -> 0 MAX-UINT }T

: IFFLOORED
   [ -3 2 / -2 = INVERT ] LITERAL IF POSTPONE \ THEN ;

: IFSYM
   [ -3 2 / -1 = INVERT ] LITERAL IF POSTPONE \ THEN ;

\ THE SYSTEM MIGHT DO EITHER FLOORED OR SYMMETRIC DIVISION.
\ SINCE WE HAVE ALREADY TESTED M*, FM/MOD, AND SM/REM WE CAN USE THEM IN TEST.

IFFLOORED : T/MOD  >R S>D R> FM/MOD ;
IFFLOORED : T/     T/MOD SWAP DROP ;
IFFLOORED : TMOD   T/MOD DROP ;
IFFLOORED : T*/MOD >R M* R> FM/MOD ;
IFFLOORED : T*/    T*/MOD SWAP DROP ;
IFSYM     : T/MOD  >R S>D R> SM/REM ;
IFSYM     : T/     T/MOD SWAP DROP ;
IFSYM     : TMOD   T/MOD DROP ;
IFSYM     : T*/MOD >R M* R> SM/REM ;
IFSYM     : T*/    T*/MOD SWAP DROP ;

T{ 0 1 /MOD -> 0 1 T/MOD }T
T{ 1 1 /MOD -> 1 1 T/MOD }T
T{ 2 1 /MOD -> 2 1 T/MOD }T
T{ -1 1 /MOD -> -1 1 T/MOD }T
T{ -2 1 /MOD -> -2 1 T/MOD }T
T{ 0 -1 /MOD -> 0 -1 T/MOD }T
T{ 1 -1 /MOD -> 1 -1 T/MOD }T
T{ 2 -1 /MOD -> 2 -1 T/MOD }T
T{ -1 -1 /MOD -> -1 -1 T/MOD }T
T{ -2 -1 /MOD -> -2 -1 T/MOD }T
T{ 2 2 /MOD -> 2 2 T/MOD }T
T{ -1 -1 /MOD -> -1 -1 T/MOD }T
T{ -2 -2 /MOD -> -2 -2 T/MOD }T
T{ 7 3 /MOD -> 7 3 T/MOD }T
T{ 7 -3 /MOD -> 7 -3 T/MOD }T
T{ -7 3 /MOD -> -7 3 T/MOD }T
T{ -7 -3 /MOD -> -7 -3 T/MOD }T
T{ MAX-INT 1 /MOD -> MAX-INT 1 T/MOD }T
T{ MIN-INT 1 /MOD -> MIN-INT 1 T/MOD }T
T{ MAX-INT MAX-INT /MOD -> MAX-INT MAX-INT T/MOD }T
T{ MIN-INT MIN-INT /MOD -> MIN-INT MIN-INT T/MOD }T

T{ 0 1 / -> 0 1 T/ }T
T{ 1 1 / -> 1 1 T/ }T
T{ 2 1 / -> 2 1 T/ }T
T{ -1 1 / -> -1 1 T/ }T
T{ -2 1 / -> -2 1 T/ }T
T{ 0 -1 / -> 0 -1 T/ }T
T{ 1 -1 / -> 1 -1 T/ }T
T{ 2 -1 / -> 2 -1 T/ }T
T{ -1 -1 / -> -1 -1 T/ }T
T{ -2 -1 / -> -2 -1 T/ }T
T{ 2 2 / -> 2 2 T/ }T
T{ -1 -1 / -> -1 -1 T/ }T
T{ -2 -2 / -> -2 -2 T/ }T
T{ 7 3 / -> 7 3 T/ }T
T{ 7 -3 / -> 7 -3 T/ }T
T{ -7 3 / -> -7 3 T/ }T
T{ -7 -3 / -> -7 -3 T/ }T
T{ MAX-INT 1 / -> MAX-INT 1 T/ }T
T{ MIN-INT 1 / -> MIN-INT 1 T/ }T
T{ MAX-INT MAX-INT / -> MAX-INT MAX-INT T/ }T
T{ MIN-INT MIN-INT / -> MIN-INT MIN-INT T/ }T

T{ 0 1 MOD -> 0 1 TMOD }T
T{ 1 1 MOD -> 1 1 TMOD }T
T{ 2 1 MOD -> 2 1 TMOD }T
T{ -1 1 MOD -> -1 1 TMOD }T
T{ -2 1 MOD -> -2 1 TMOD }T
T{ 0 -1 MOD -> 0 -1 TMOD }T
T{ 1 -1 MOD -> 1 -1 TMOD }T
T{ 2 -1 MOD -> 2 -1 TMOD }T
T{ -1 -1 MOD -> -1 -1 TMOD }T
T{ -2 -1 MOD -> -2 -1 TMOD }T
T{ 2 2 MOD -> 2 2 TMOD }T
T{ -1 -1 MOD -> -1 -1 TMOD }T
T{ -2 -2 MOD -> -2 -2 TMOD }T
T{ 7 3 MOD -> 7 3 TMOD }T
T{ 7 -3 MOD -> 7 -3 TMOD }T
T{ -7 3 MOD -> -7 3 TMOD }T
T{ -7 -3 MOD -> -7 -3 TMOD }T
T{ MAX-INT 1 MOD -> MAX-INT 1 TMOD }T
T{ MIN-INT 1 MOD -> MIN-INT 1 TMOD }T
T{ MAX-INT MAX-INT MOD -> MAX-INT MAX-INT TMOD }T
T{ MIN-INT MIN-INT MOD -> MIN-INT MIN-INT TMOD }T

T{ 0 2 1 */ -> 0 2 1 T*/ }T
T{ 1 2 1 */ -> 1 2 1 T*/ }T
T{ 2 2 1 */ -> 2 2 1 T*/ }T
T{ -1 2 1 */ -> -1 2 1 T*/ }T
T{ -2 2 1 */ -> -2 2 1 T*/ }T
T{ 0 2 -1 */ -> 0 2 -1 T*/ }T
T{ 1 2 -1 */ -> 1 2 -1 T*/ }T
T{ 2 2 -1 */ -> 2 2 -1 T*/ }T
T{ -1 2 -1 */ -> -1 2 -1 T*/ }T
T{ -2 2 -1 */ -> -2 2 -1 T*/ }T
T{ 2 2 2 */ -> 2 2 2 T*/ }T
T{ -1 2 -1 */ -> -1 2 -1 T*/ }T
T{ -2 2 -2 */ -> -2 2 -2 T*/ }T
T{ 7 2 3 */ -> 7 2 3 T*/ }T
T{ 7 2 -3 */ -> 7 2 -3 T*/ }T
T{ -7 2 3 */ -> -7 2 3 T*/ }T
T{ -7 2 -3 */ -> -7 2 -3 T*/ }T
T{ MAX-INT 2 MAX-INT */ -> MAX-INT 2 MAX-INT T*/ }T
T{ MIN-INT 2 MIN-INT */ -> MIN-INT 2 MIN-INT T*/ }T

T{ 0 2 1 */MOD -> 0 2 1 T*/MOD }T
T{ 1 2 1 */MOD -> 1 2 1 T*/MOD }T
T{ 2 2 1 */MOD -> 2 2 1 T*/MOD }T
T{ -1 2 1 */MOD -> -1 2 1 T*/MOD }T
T{ -2 2 1 */MOD -> -2 2 1 T*/MOD }T
T{ 0 2 -1 */MOD -> 0 2 -1 T*/MOD }T
T{ 1 2 -1 */MOD -> 1 2 -1 T*/MOD }T
T{ 2 2 -1 */MOD -> 2 2 -1 T*/MOD }T
T{ -1 2 -1 */MOD -> -1 2 -1 T*/MOD }T
T{ -2 2 -1 */MOD -> -2 2 -1 T*/MOD }T
T{ 2 2 2 */MOD -> 2 2 2 T*/MOD }T
T{ -1 2 -1 */MOD -> -1 2 -1 T*/MOD }T
T{ -2 2 -2 */MOD -> -2 2 -2 T*/MOD }T
T{ 7 2 3 */MOD -> 7 2 3 T*/MOD }T
T{ 7 2 -3 */MOD -> 7 2 -3 T*/MOD }T
T{ -7 2 3 */MOD -> -7 2 3 T*/MOD }T
T{ -7 2 -3 */MOD -> -7 2 -3 T*/MOD }T
T{ MAX-INT 2 MAX-INT */MOD -> MAX-INT 2 MAX-INT T*/MOD }T
T{ MIN-INT 2 MIN-INT */MOD -> MIN-INT 2 MIN-INT T*/MOD }T

\ ------------------------------------------------------------------------
TESTING HERE , @ ! CELL+ CELLS C, C@ C! CHARS 2@ 2! ALIGN ALIGNED +! ALLOT

HERE 1 ALLOT
HERE
CONSTANT 2NDA
CONSTANT 1STA
T{ 1STA 2NDA U< -> <TRUE> }T      \ HERE MUST GROW WITH ALLOT
T{ 1STA 1+ -> 2NDA }T         \ ... BY ONE ADDRESS UNIT
( MISSING TEST: NEGATIVE ALLOT )

\ Added by GWJ so that ALIGN can be used before , (comma) is tested
1 ALIGNED CONSTANT ALMNT   \ -- 1|2|4|8 for 8|16|32|64 bit alignment
ALIGN
T{ HERE 1 ALLOT ALIGN HERE SWAP - ALMNT = -> <TRUE> }T
\ End of extra test

HERE 1 ,
HERE 2 ,
CONSTANT 2ND
CONSTANT 1ST
T{ 1ST 2ND U< -> <TRUE> }T         \ HERE MUST GROW WITH ALLOT
T{ 1ST CELL+ -> 2ND }T         \ ... BY ONE CELL
T{ 1ST 1 CELLS + -> 2ND }T
T{ 1ST @ 2ND @ -> 1 2 }T
T{ 5 1ST ! -> }T
T{ 1ST @ 2ND @ -> 5 2 }T
T{ 6 2ND ! -> }T
T{ 1ST @ 2ND @ -> 5 6 }T
T{ 1ST 2@ -> 6 5 }T
T{ 2 1 1ST 2! -> }T
T{ 1ST 2@ -> 2 1 }T
T{ 1S 1ST !  1ST @ -> 1S }T      \ CAN STORE CELL-WIDE VALUE

HERE 1 C,
HERE 2 C,
CONSTANT 2NDC
CONSTANT 1STC
T{ 1STC 2NDC U< -> <TRUE> }T      \ HERE MUST GROW WITH ALLOT
T{ 1STC CHAR+ -> 2NDC }T         \ ... BY ONE CHAR
T{ 1STC 1 CHARS + -> 2NDC }T
T{ 1STC C@ 2NDC C@ -> 1 2 }T
T{ 3 1STC C! -> }T
T{ 1STC C@ 2NDC C@ -> 3 2 }T
T{ 4 2NDC C! -> }T
T{ 1STC C@ 2NDC C@ -> 3 4 }T

ALIGN 1 ALLOT HERE ALIGN HERE 3 CELLS ALLOT
CONSTANT A-ADDR  CONSTANT UA-ADDR
T{ UA-ADDR ALIGNED -> A-ADDR }T
T{    1 A-ADDR C!  A-ADDR C@ ->    1 }T
T{ 1234 A-ADDR  !  A-ADDR  @ -> 1234 }T
T{ 123 456 A-ADDR 2!  A-ADDR 2@ -> 123 456 }T
T{ 2 A-ADDR CHAR+ C!  A-ADDR CHAR+ C@ -> 2 }T
T{ 3 A-ADDR CELL+ C!  A-ADDR CELL+ C@ -> 3 }T
T{ 1234 A-ADDR CELL+ !  A-ADDR CELL+ @ -> 1234 }T
T{ 123 456 A-ADDR CELL+ 2!  A-ADDR CELL+ 2@ -> 123 456 }T

: BITS ( X -- U )
   0 SWAP BEGIN DUP WHILE DUP MSB AND IF >R 1+ R> THEN 2* REPEAT DROP ;
( CHARACTERS >= 1 AU, <= SIZE OF CELL, >= 8 BITS )
T{ 1 CHARS 1 < -> <FALSE> }T
T{ 1 CHARS 1 CELLS > -> <FALSE> }T
( TBD: HOW TO FIND NUMBER OF BITS? )

( CELLS >= 1 AU, INTEGRAL MULTIPLE OF CHAR SIZE, >= 16 BITS )
T{ 1 CELLS 1 < -> <FALSE> }T
T{ 1 CELLS 1 CHARS MOD -> 0 }T
T{ 1S BITS 10 < -> <FALSE> }T

T{ 0 1ST ! -> }T
T{ 1 1ST +! -> }T
T{ 1ST @ -> 1 }T
T{ -1 1ST +! 1ST @ -> 0 }T

\ ------------------------------------------------------------------------
TESTING CHAR [CHAR] [ ] BL S"

T{ BL -> 20 }T
T{ CHAR X -> 58 }T
T{ CHAR HELLO -> 48 }T
T{ : GC1 [CHAR] X ; -> }T
T{ : GC2 [CHAR] HELLO ; -> }T
T{ GC1 -> 58 }T
T{ GC2 -> 48 }T
T{ : GC3 [ GC1 ] LITERAL ; -> }T
T{ GC3 -> 58 }T
T{ : GC4 S" XY" ; -> }T
T{ GC4 SWAP DROP -> 2 }T
T{ GC4 DROP DUP C@ SWAP CHAR+ C@ -> 58 59 }T

\ ------------------------------------------------------------------------
TESTING ' ['] FIND EXECUTE IMMEDIATE COUNT LITERAL POSTPONE STATE

T{ : GT1 123 ; -> }T
T{ ' GT1 EXECUTE -> 123 }T
T{ : GT2 ['] GT1 ; IMMEDIATE -> }T
T{ GT2 EXECUTE -> 123 }T

\ HERE 3 C, CHAR G C, CHAR T C, CHAR 1 C, CONSTANT GT1STRING
\ HERE 3 C, CHAR G C, CHAR T C, CHAR 2 C, CONSTANT GT2STRING
\ T{ GT1STRING FIND -> ' GT1 -1 }T
\ T{ GT2STRING FIND -> ' GT2 1 }T
\ ( HOW TO SEARCH FOR NON-EXISTENT WORD? )
\ T{ : GT3 GT2 LITERAL ; -> }T
\ T{ GT3 -> ' GT1 }T
\ T{ GT1STRING COUNT -> GT1STRING CHAR+ 3 }T
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

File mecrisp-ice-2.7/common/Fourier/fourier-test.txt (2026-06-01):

: fft-test ( -- )
  N_WAVE 0 do
    i 16 * n_wave 2/ 1- and sinewave@ 2/floored  i fft-real!
    0                                            i fft-imag!
  loop

  ." FFT Scale: " LOG2_N_WAVE false fix-fft . cr
  LOG2_N_WAVE fftswap

  \ LOG2_N_WAVE fftswap
  \ ." iFFT Scale: " LOG2_N_WAVE true fix-fft . cr

  N_WAVE 0 do
    i 16 * n_wave 2/ 1- and sinewave@ 2/floored .  0           .
    i                fft-real@                  .  i fft-imag@ .
    cr
  loop
;

fft-test

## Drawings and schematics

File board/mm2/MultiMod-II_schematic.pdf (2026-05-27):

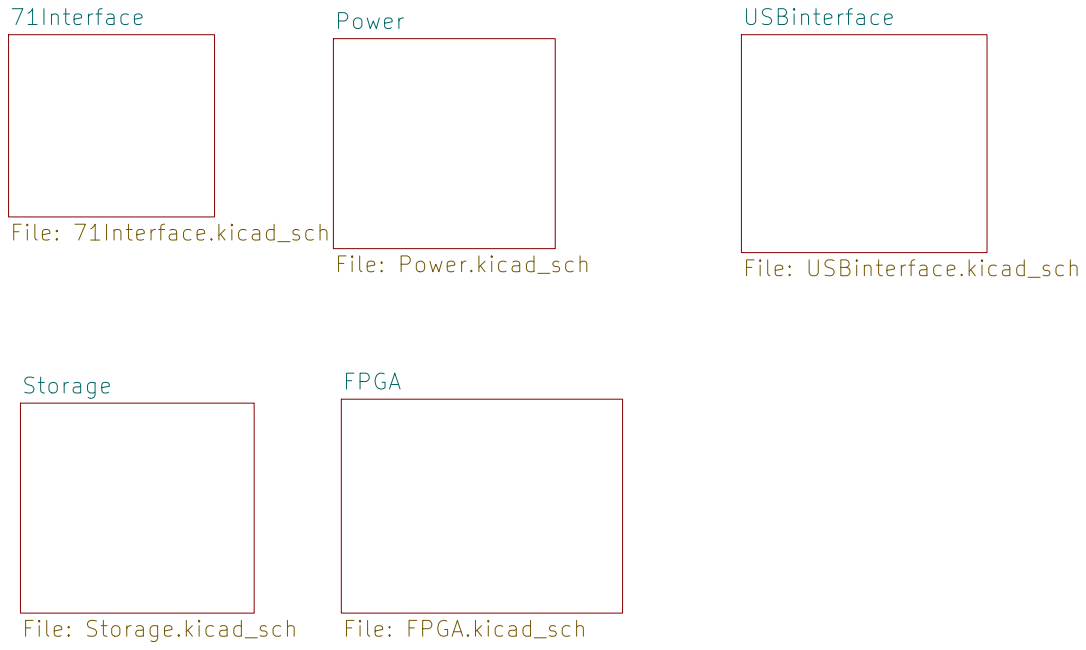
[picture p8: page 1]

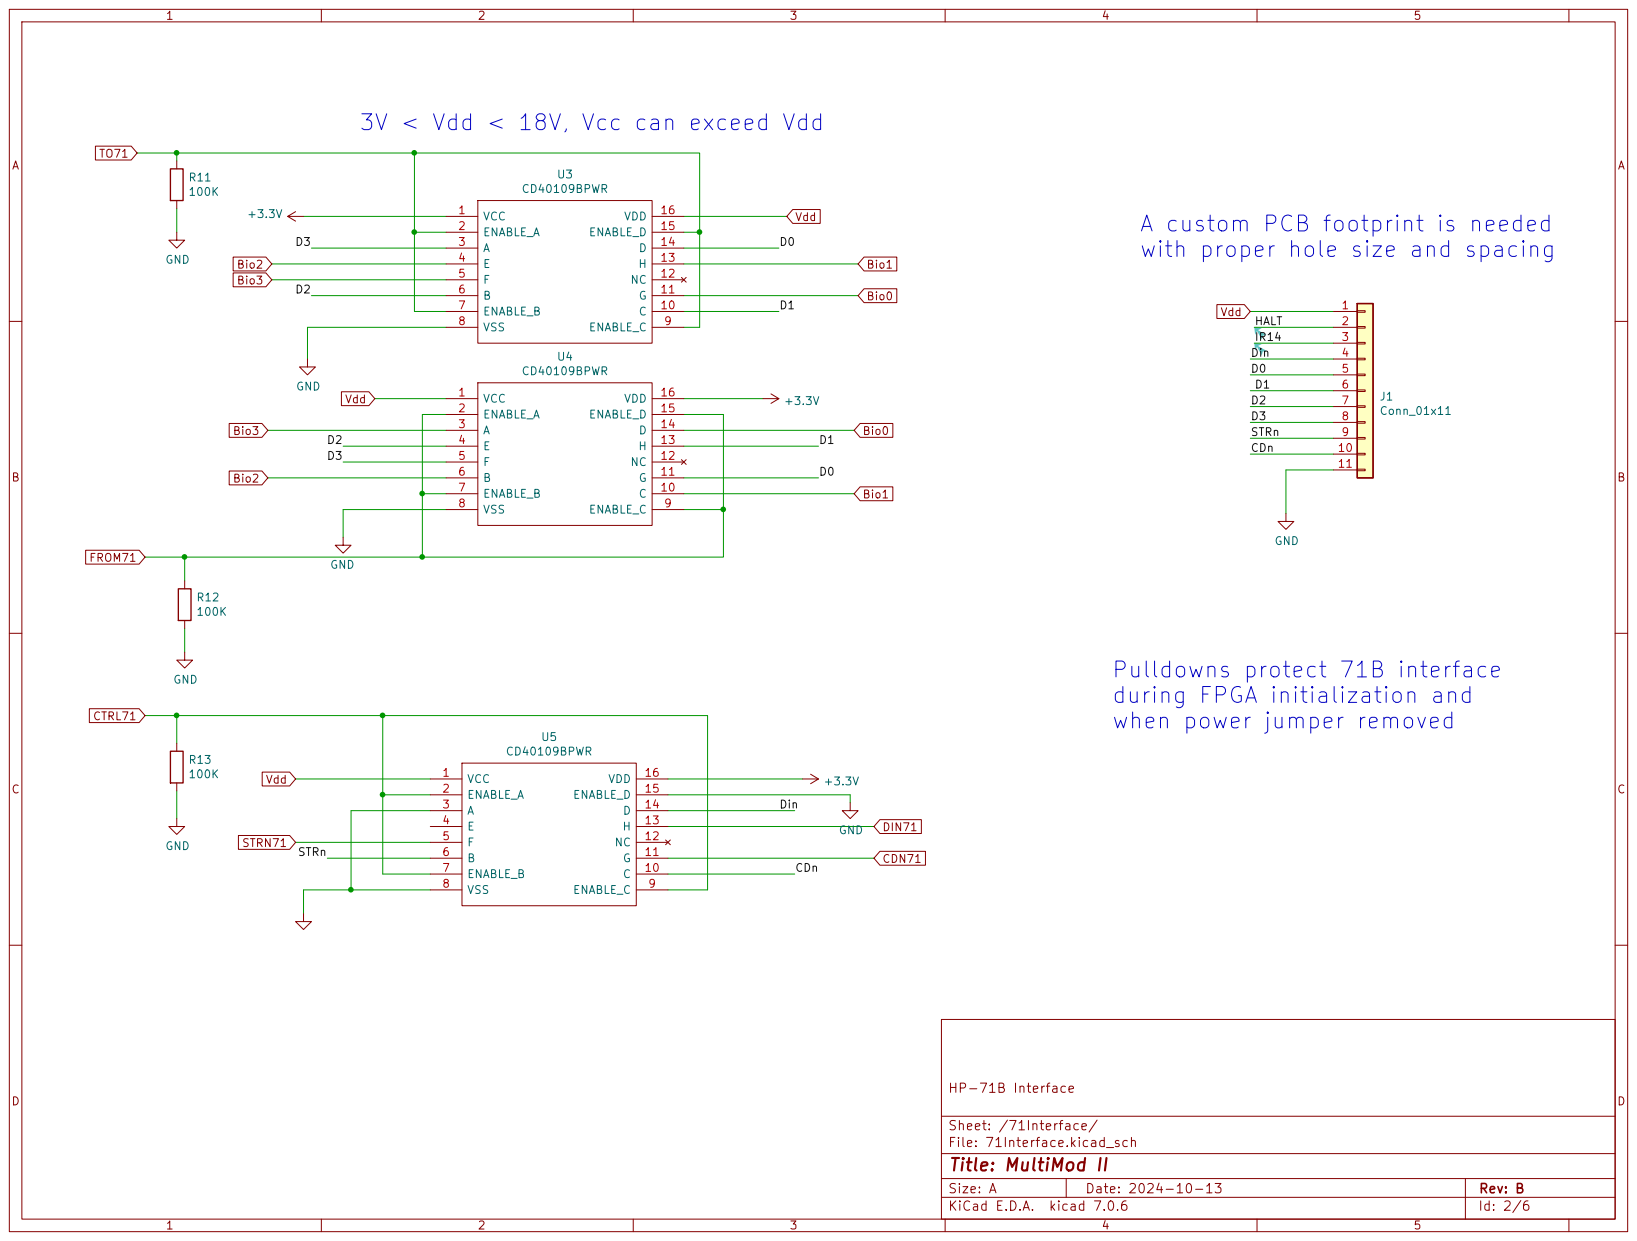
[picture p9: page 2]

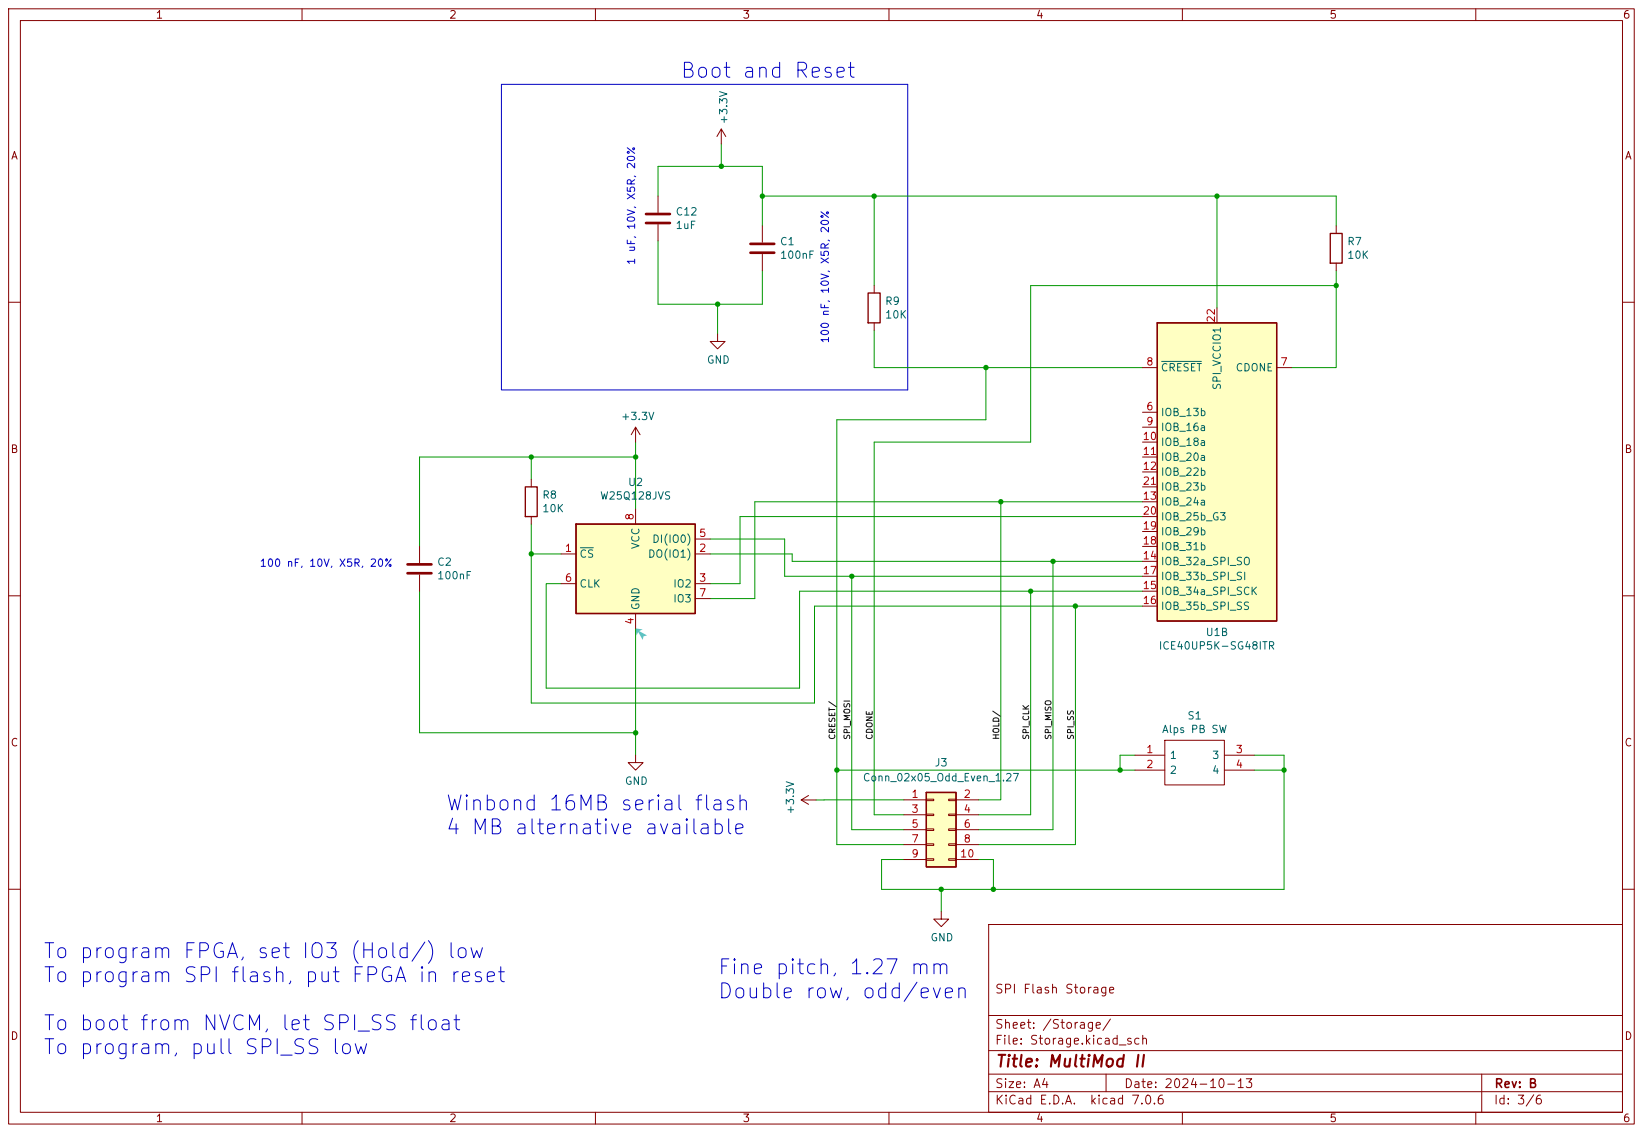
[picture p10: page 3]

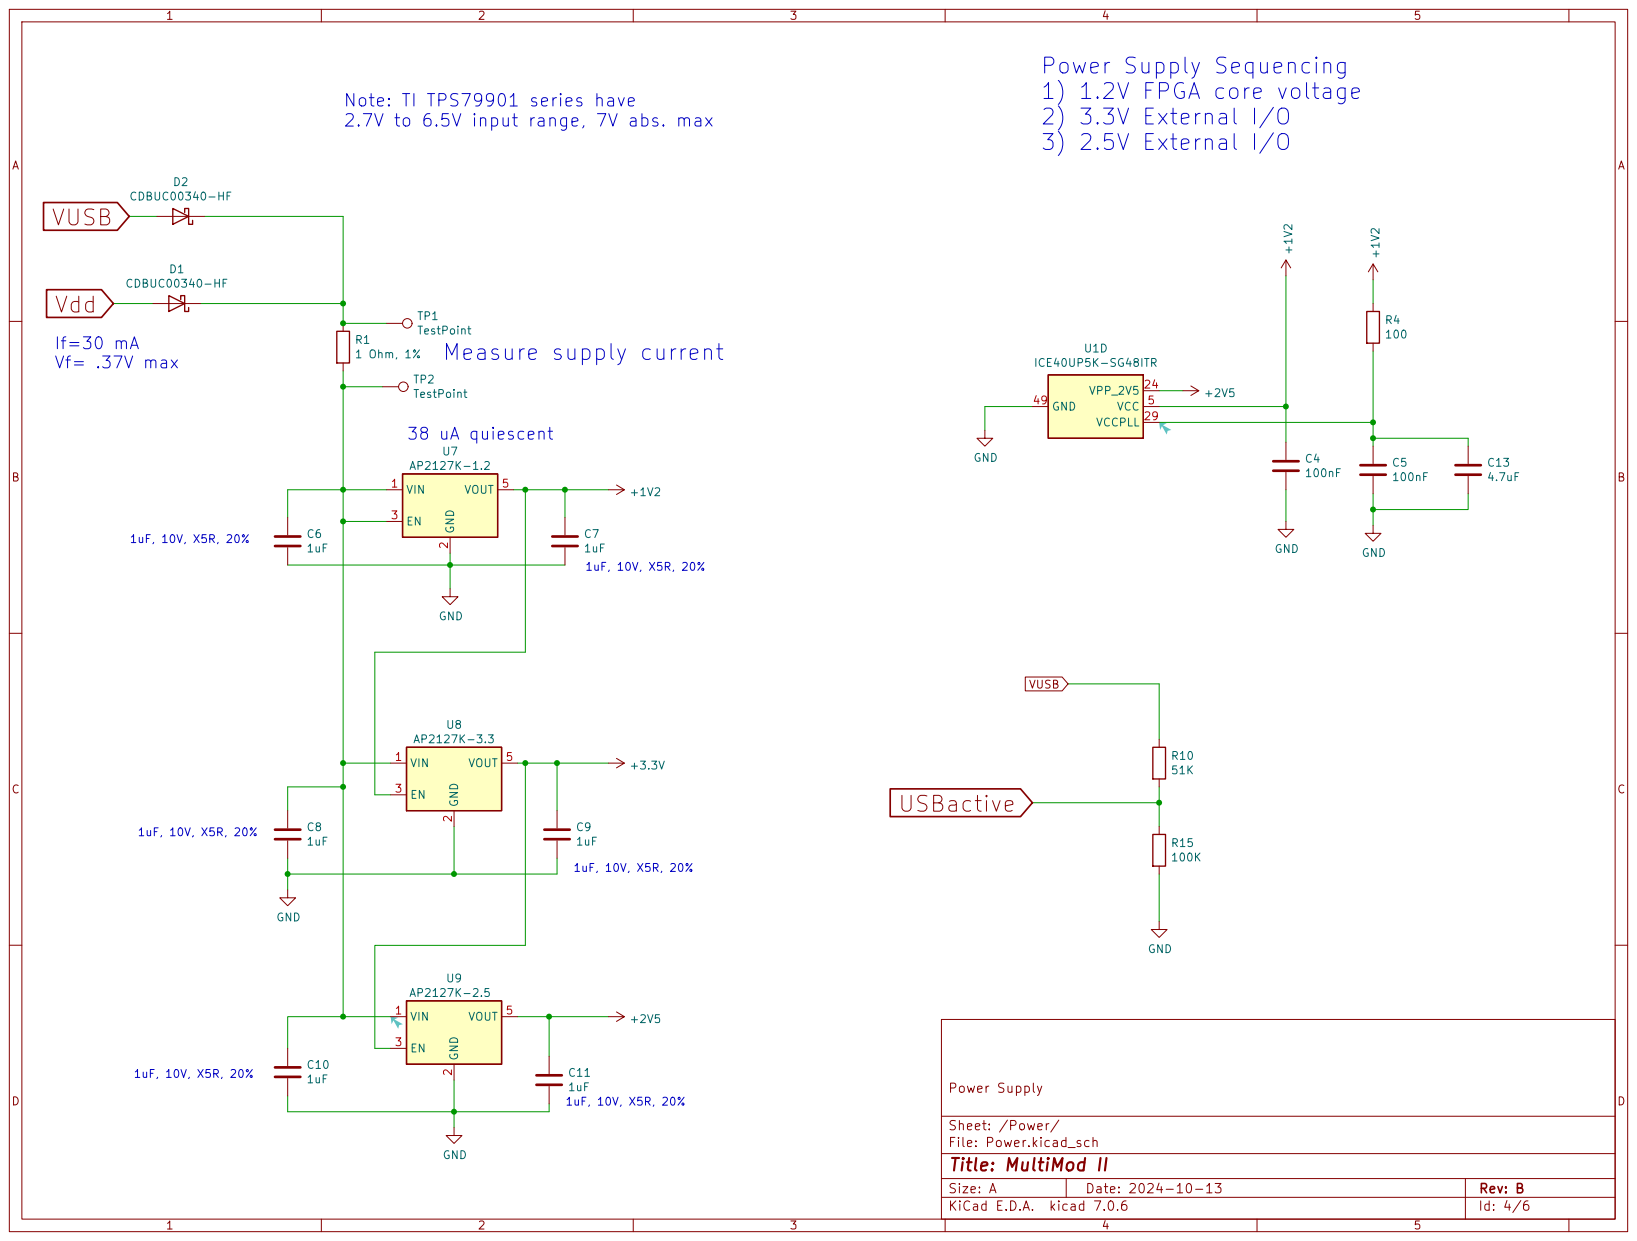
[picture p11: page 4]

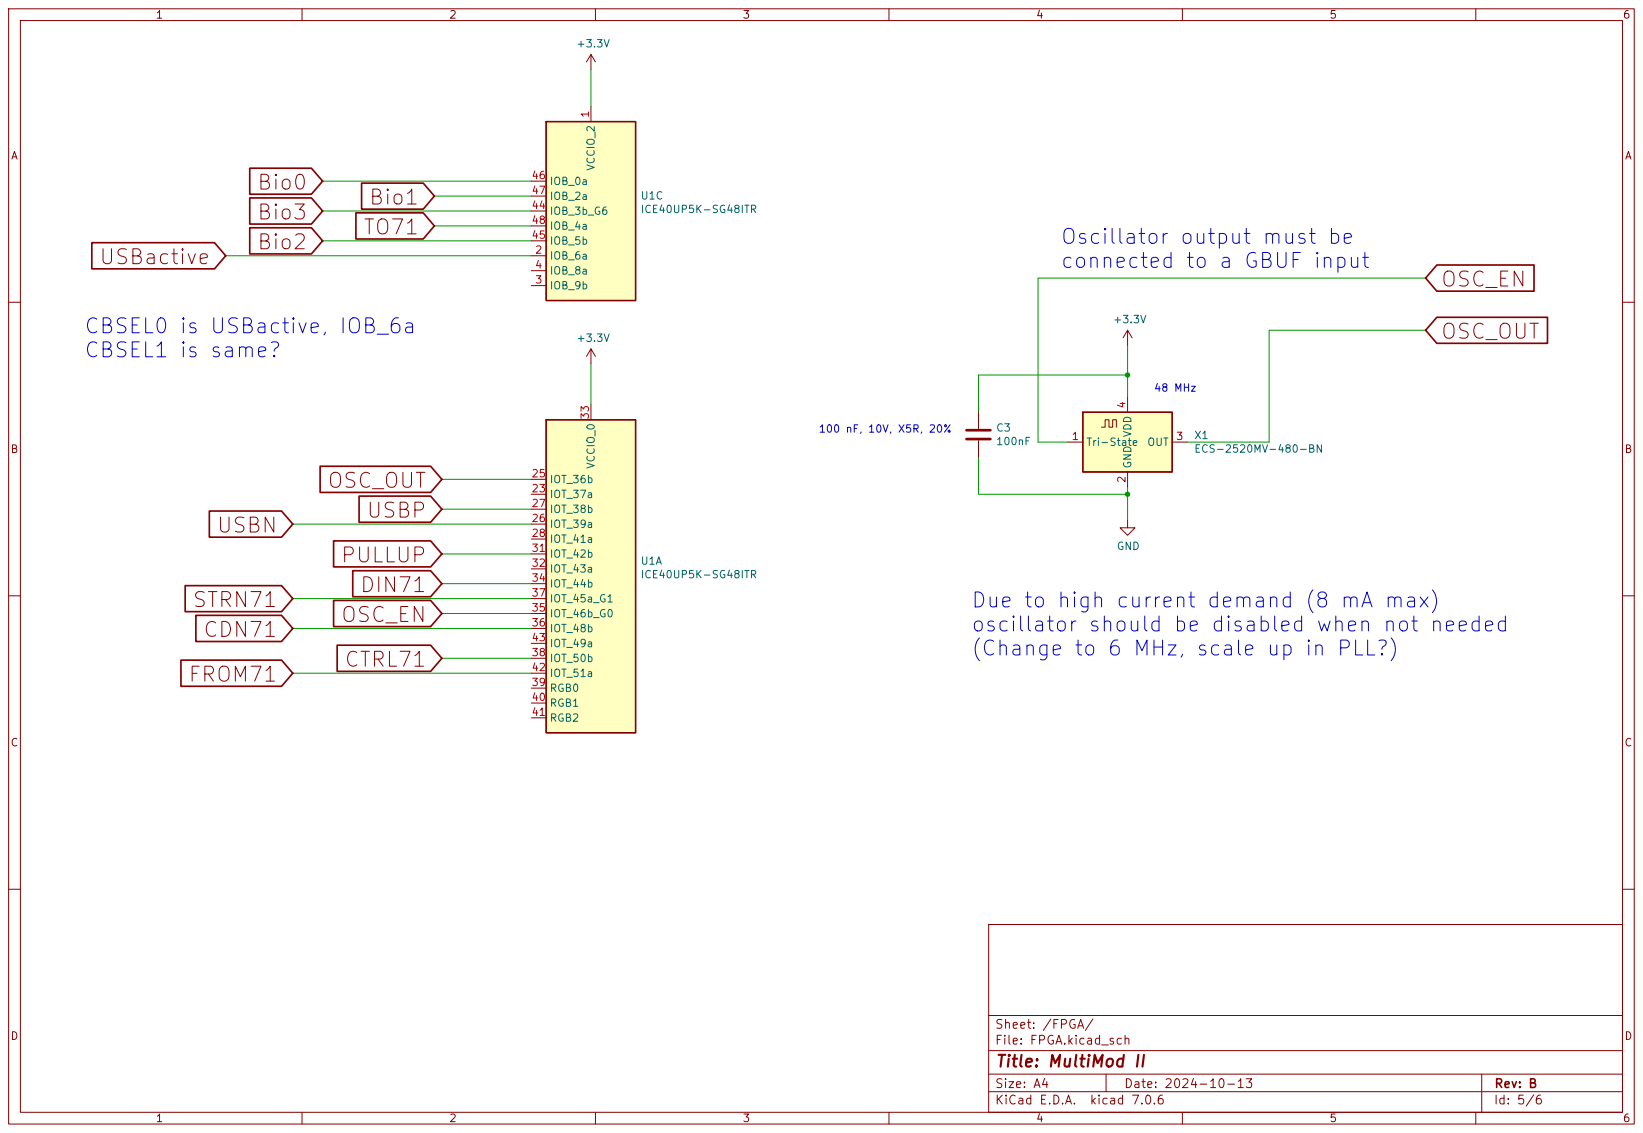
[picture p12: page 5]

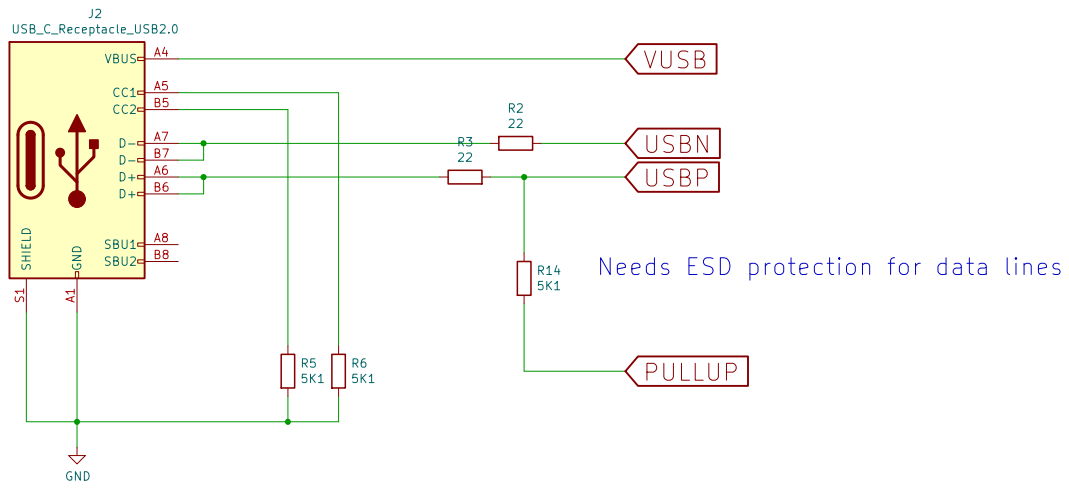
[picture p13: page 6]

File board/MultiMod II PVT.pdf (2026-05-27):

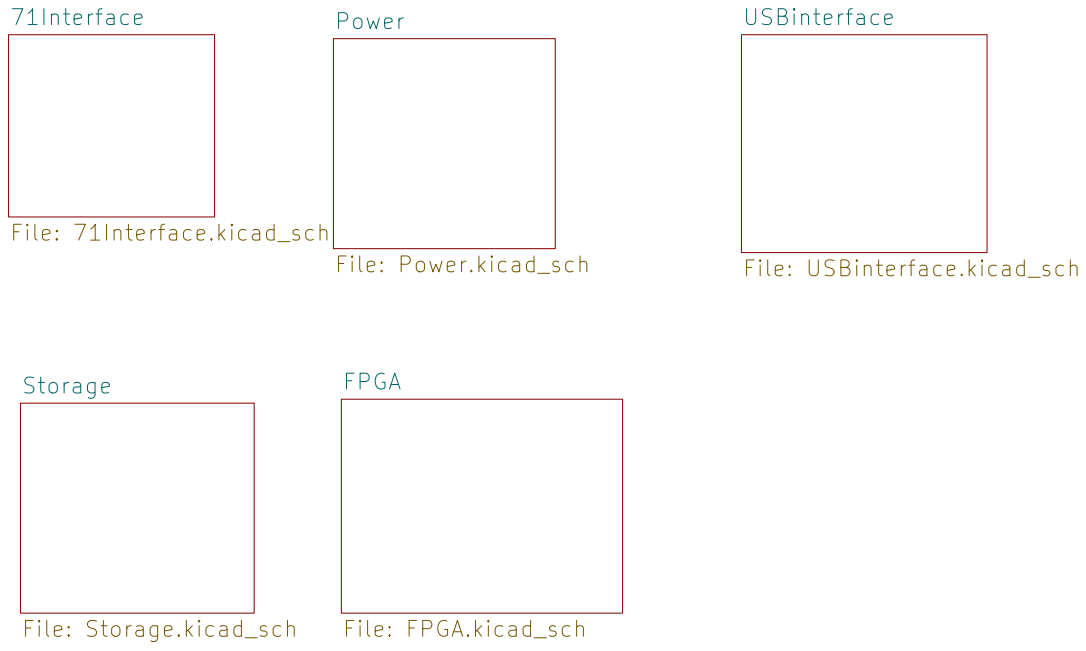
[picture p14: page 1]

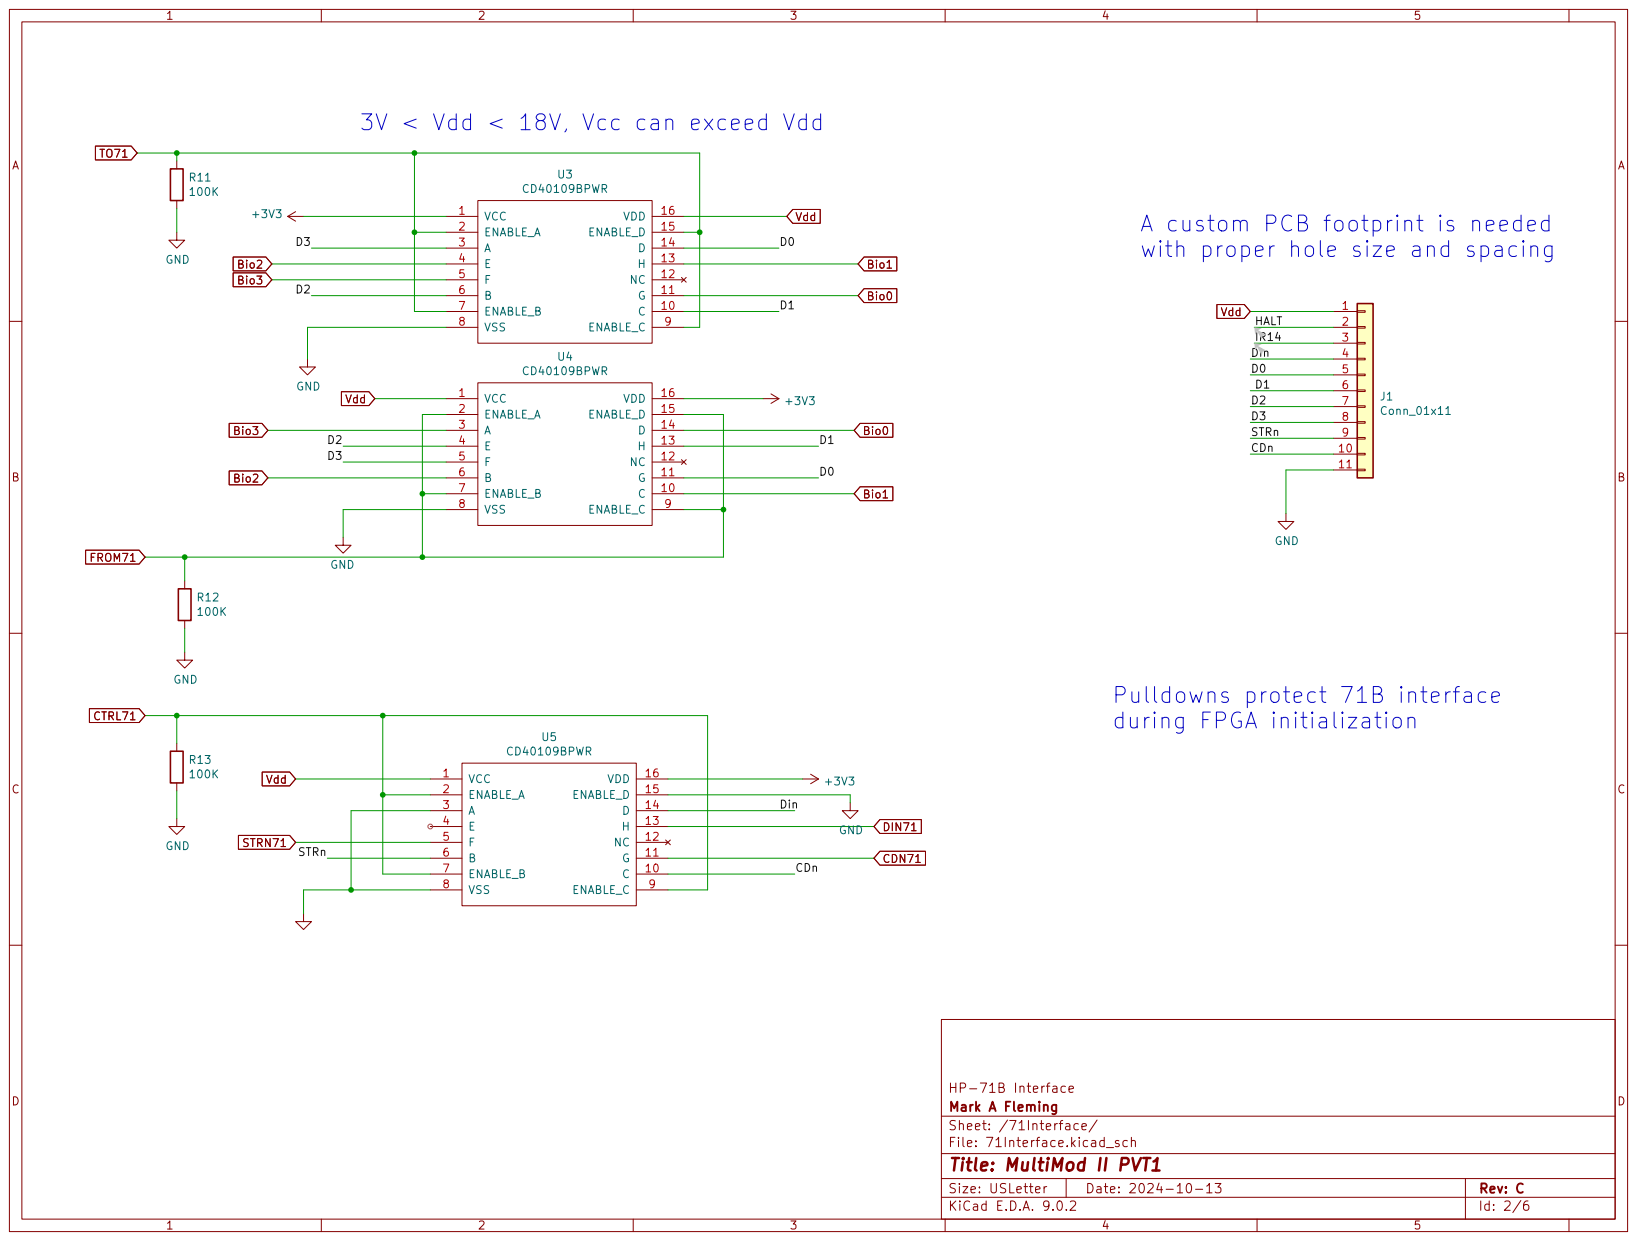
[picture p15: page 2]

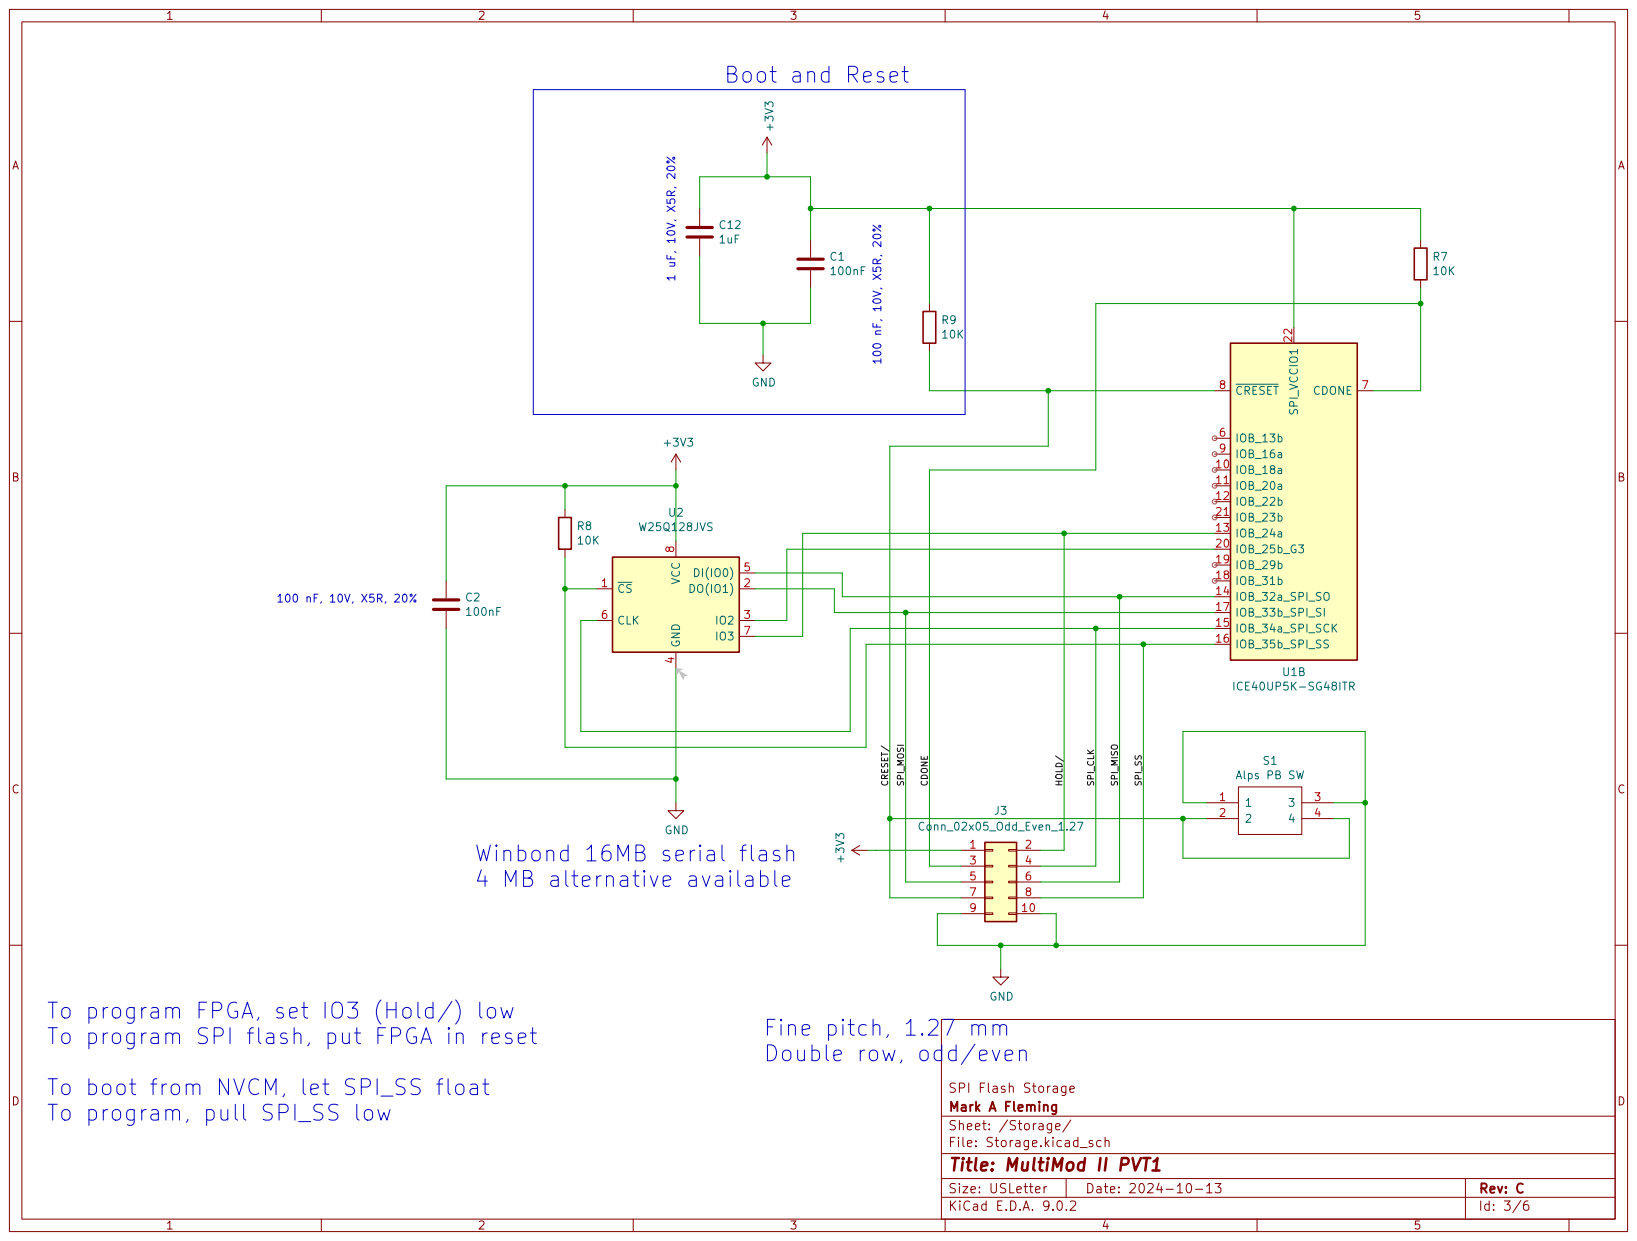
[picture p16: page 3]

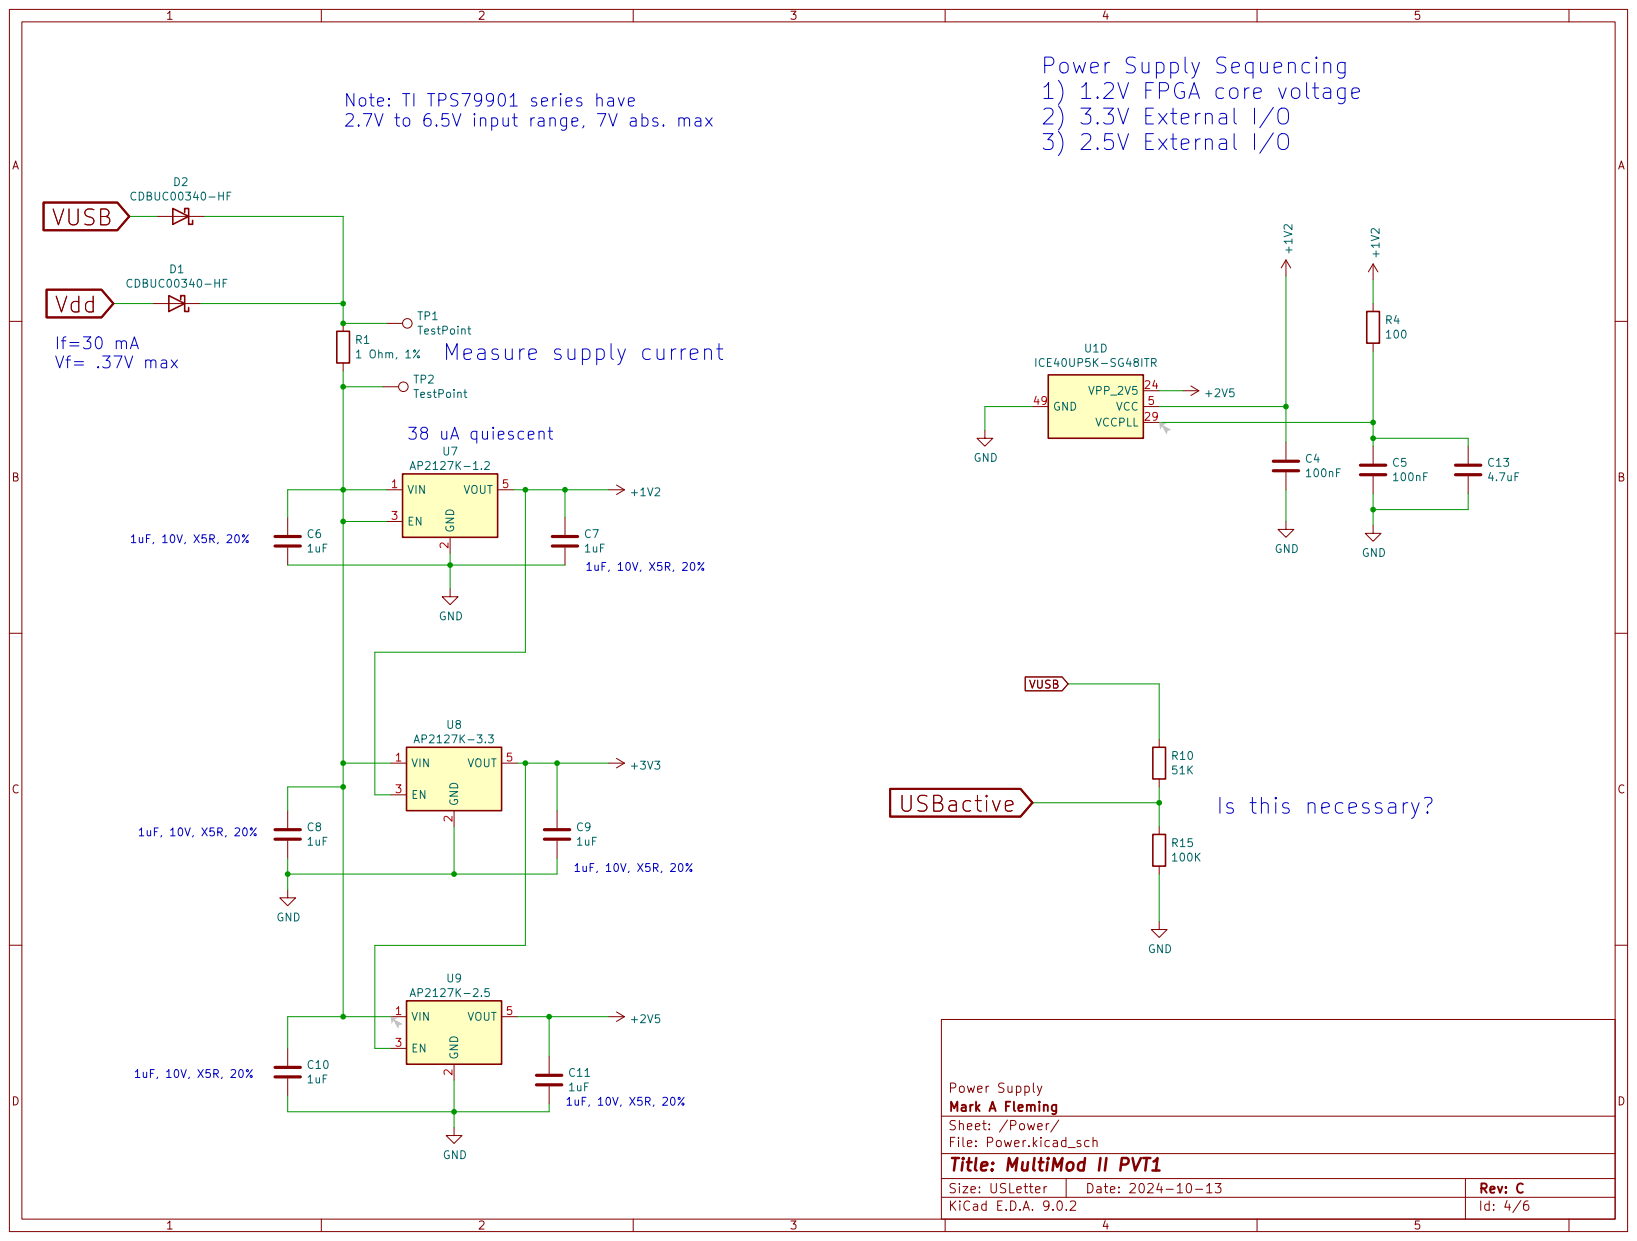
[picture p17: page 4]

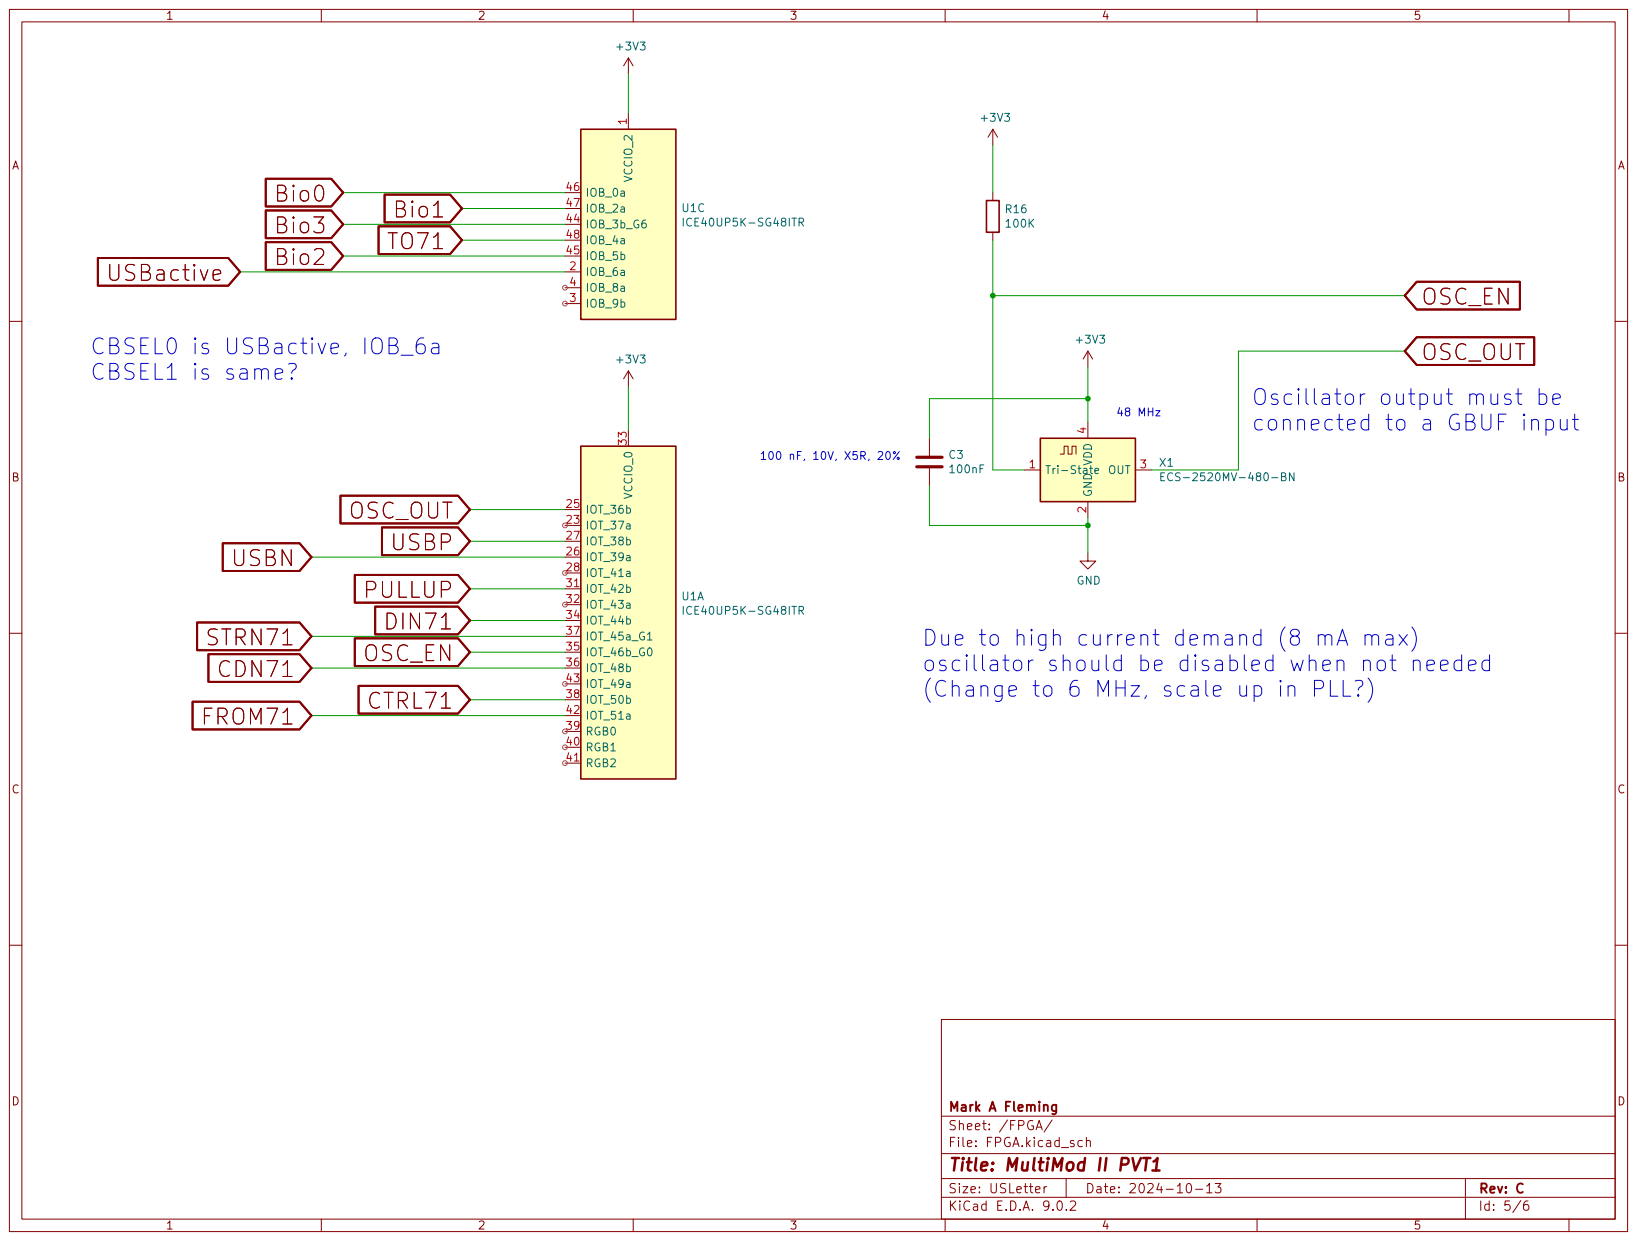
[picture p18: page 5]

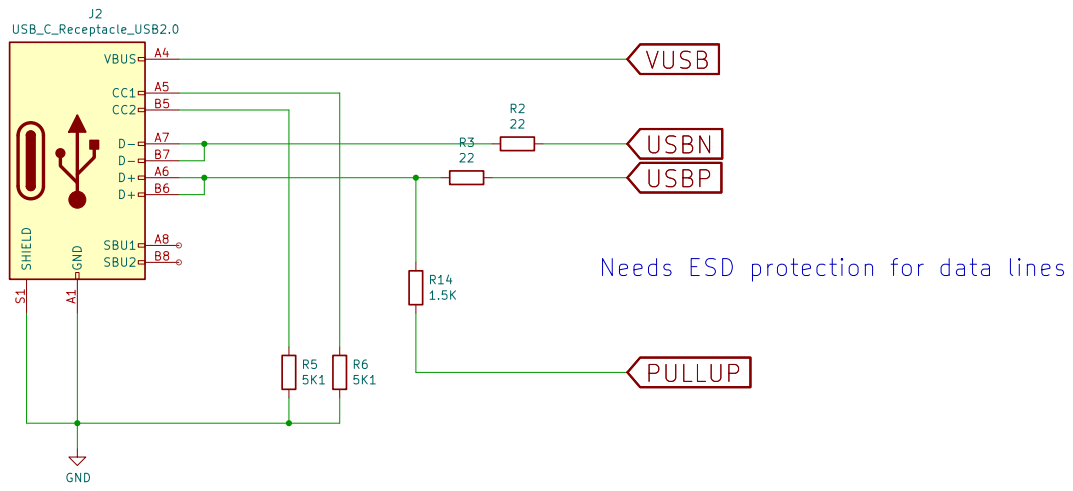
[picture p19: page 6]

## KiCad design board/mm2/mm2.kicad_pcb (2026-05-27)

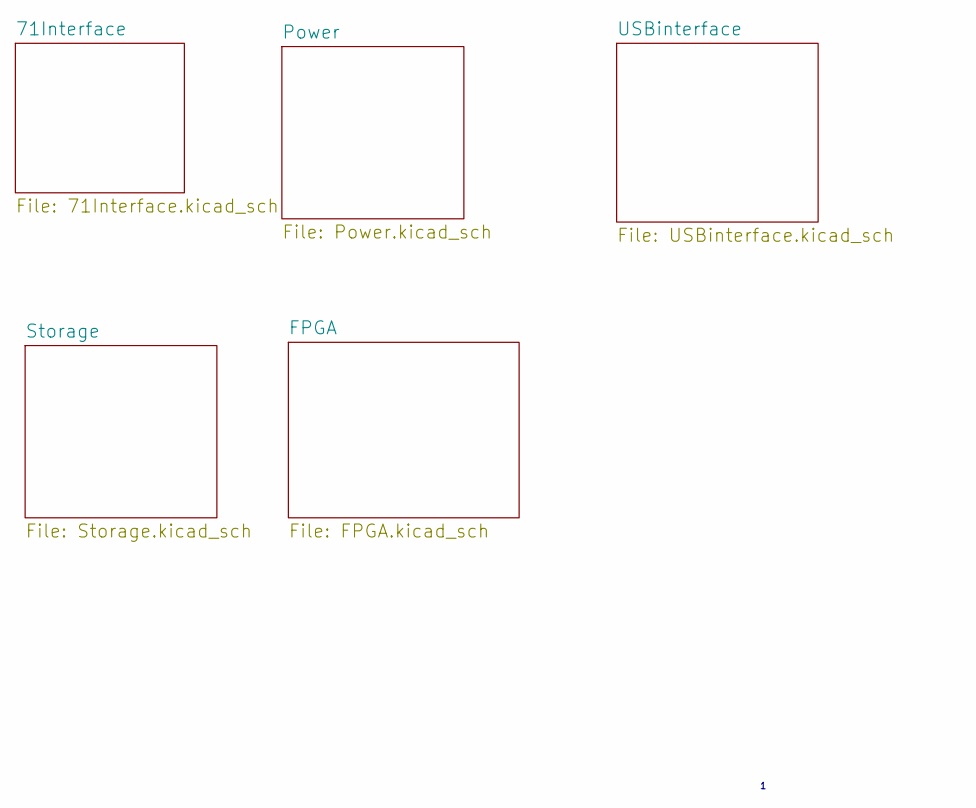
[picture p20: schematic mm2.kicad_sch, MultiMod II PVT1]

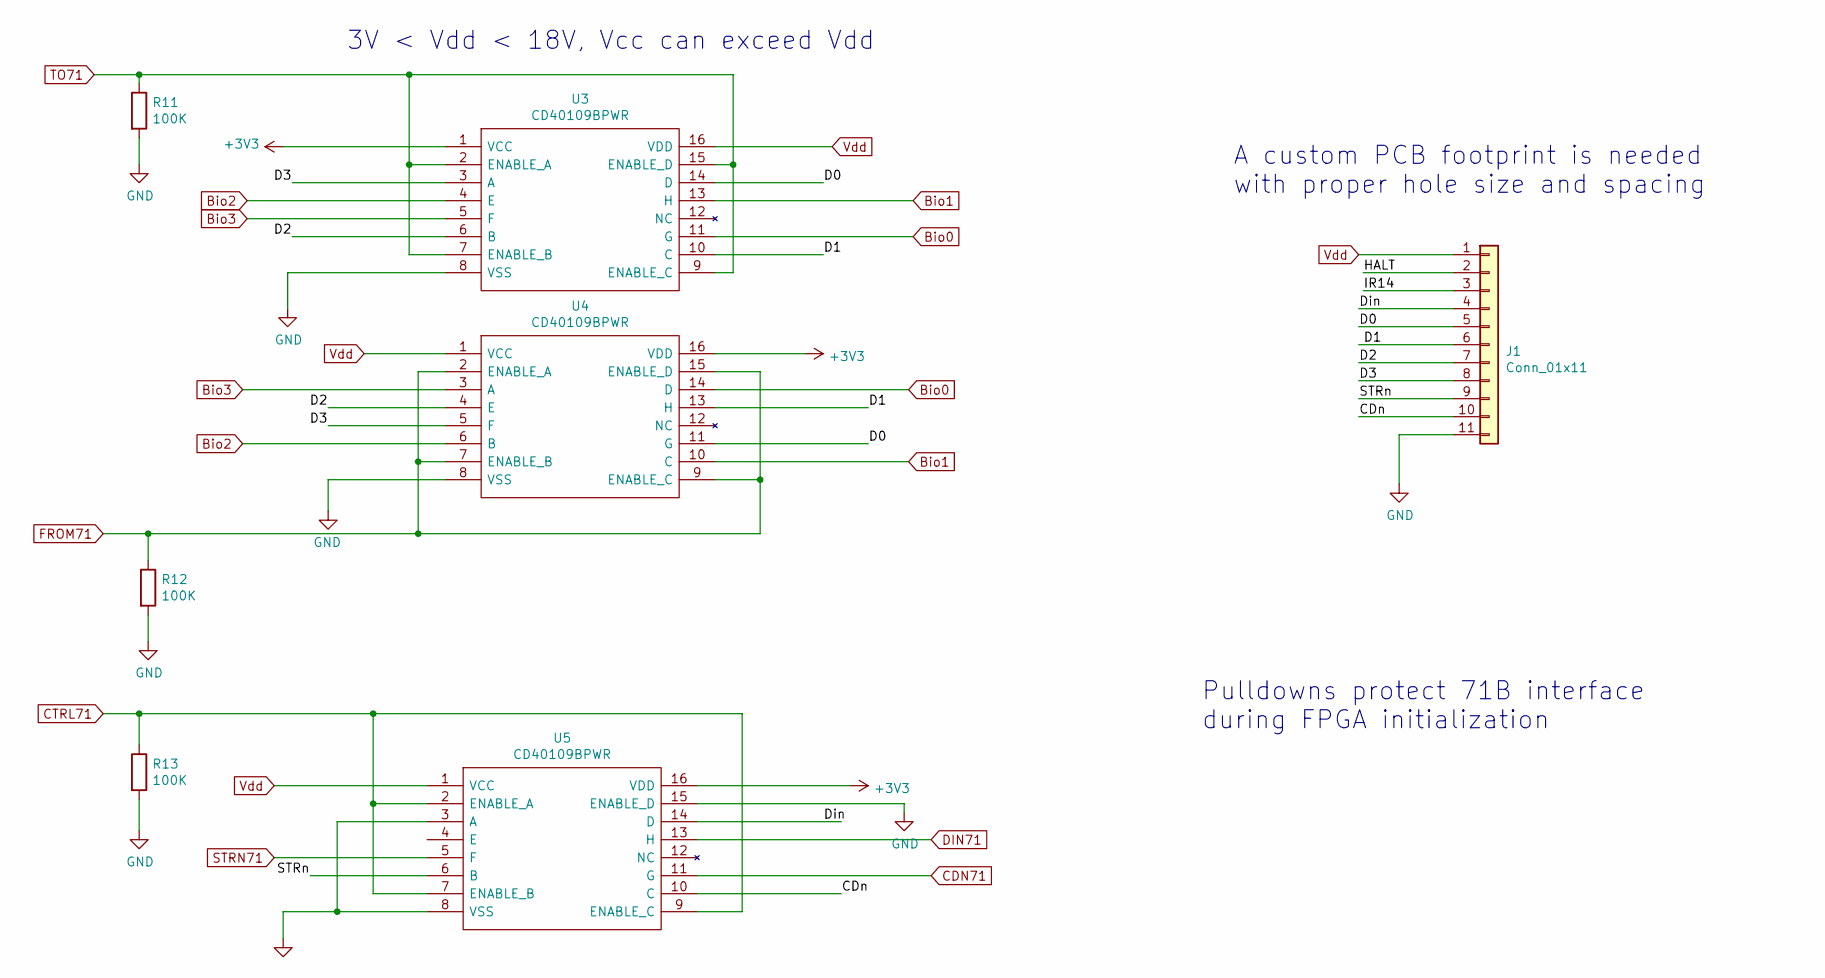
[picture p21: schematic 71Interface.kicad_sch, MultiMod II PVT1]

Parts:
J1: Conn_01x11; SIP-11
R11, R12, R13: 100K; R_0603_1608Metric
U3, U4, U5: CD40109BPWR; TSSOP-16_4.4x5mm_P0.65mm; Mouser2 Part Number 595-CD40109BPWR

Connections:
+3V3: U3.1 (VCC), U4.16 (VDD), U5.16 (VDD); also elsewhere on the board
/71Interface/CDn: J1.10, U5.10 (C)
/71Interface/D0: J1.5, U3.14 (D), U4.11 (G)
/71Interface/D1: J1.6, U3.10 (C), U4.13 (H)
/71Interface/D2: J1.7, U3.6 (B), U4.4 (E)
/71Interface/D3: J1.8, U3.3 (A), U4.5 (F)
/71Interface/Din: J1.4, U5.14 (D)
/71Interface/HALT: J1.2
/71Interface/IR14: J1.3
/71Interface/STRn: J1.9, U5.6 (B)
Bio0: U3.11 (G), U4.14 (D); also elsewhere on the board
Bio1: U3.13 (H), U4.10 (C); also elsewhere on the board
Bio2: U3.4 (E), U4.6 (B); also elsewhere on the board
Bio3: U3.5 (F), U4.3 (A); also elsewhere on the board
CDN71: U5.11 (G); also elsewhere on the board
CTRL71: R13.1, U5.2 (ENABLE_A), U5.7 (ENABLE_B), U5.9 (ENABLE_C); also elsewhere on the board
DIN71: U5.13 (H); also elsewhere on the board
FROM71: R12.1, U4.2 (ENABLE_A), U4.7 (ENABLE_B), U4.9 (ENABLE_C), U4.15 (ENABLE_D); also elsewhere on the board
GND: J1.11, R11.2, R12.2, R13.2, U3.8 (VSS), U4.8 (VSS), U5.3 (A), U5.8 (VSS), U5.15 (ENABLE_D); also elsewhere on the board
STRN71: U5.5 (F); also elsewhere on the board
TO71: R11.1, U3.2 (ENABLE_A), U3.7 (ENABLE_B), U3.9 (ENABLE_C), U3.15 (ENABLE_D); also elsewhere on the board
Vdd: J1.1, U3.16 (VDD), U4.1 (VCC), U5.1 (VCC); also elsewhere on the board

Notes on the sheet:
A custom PCB footprint is needed with proper hole size and spacing
Pulldowns protect 71B interface during FPGA initialization
3V < Vdd < 18V, Vcc can exceed Vdd

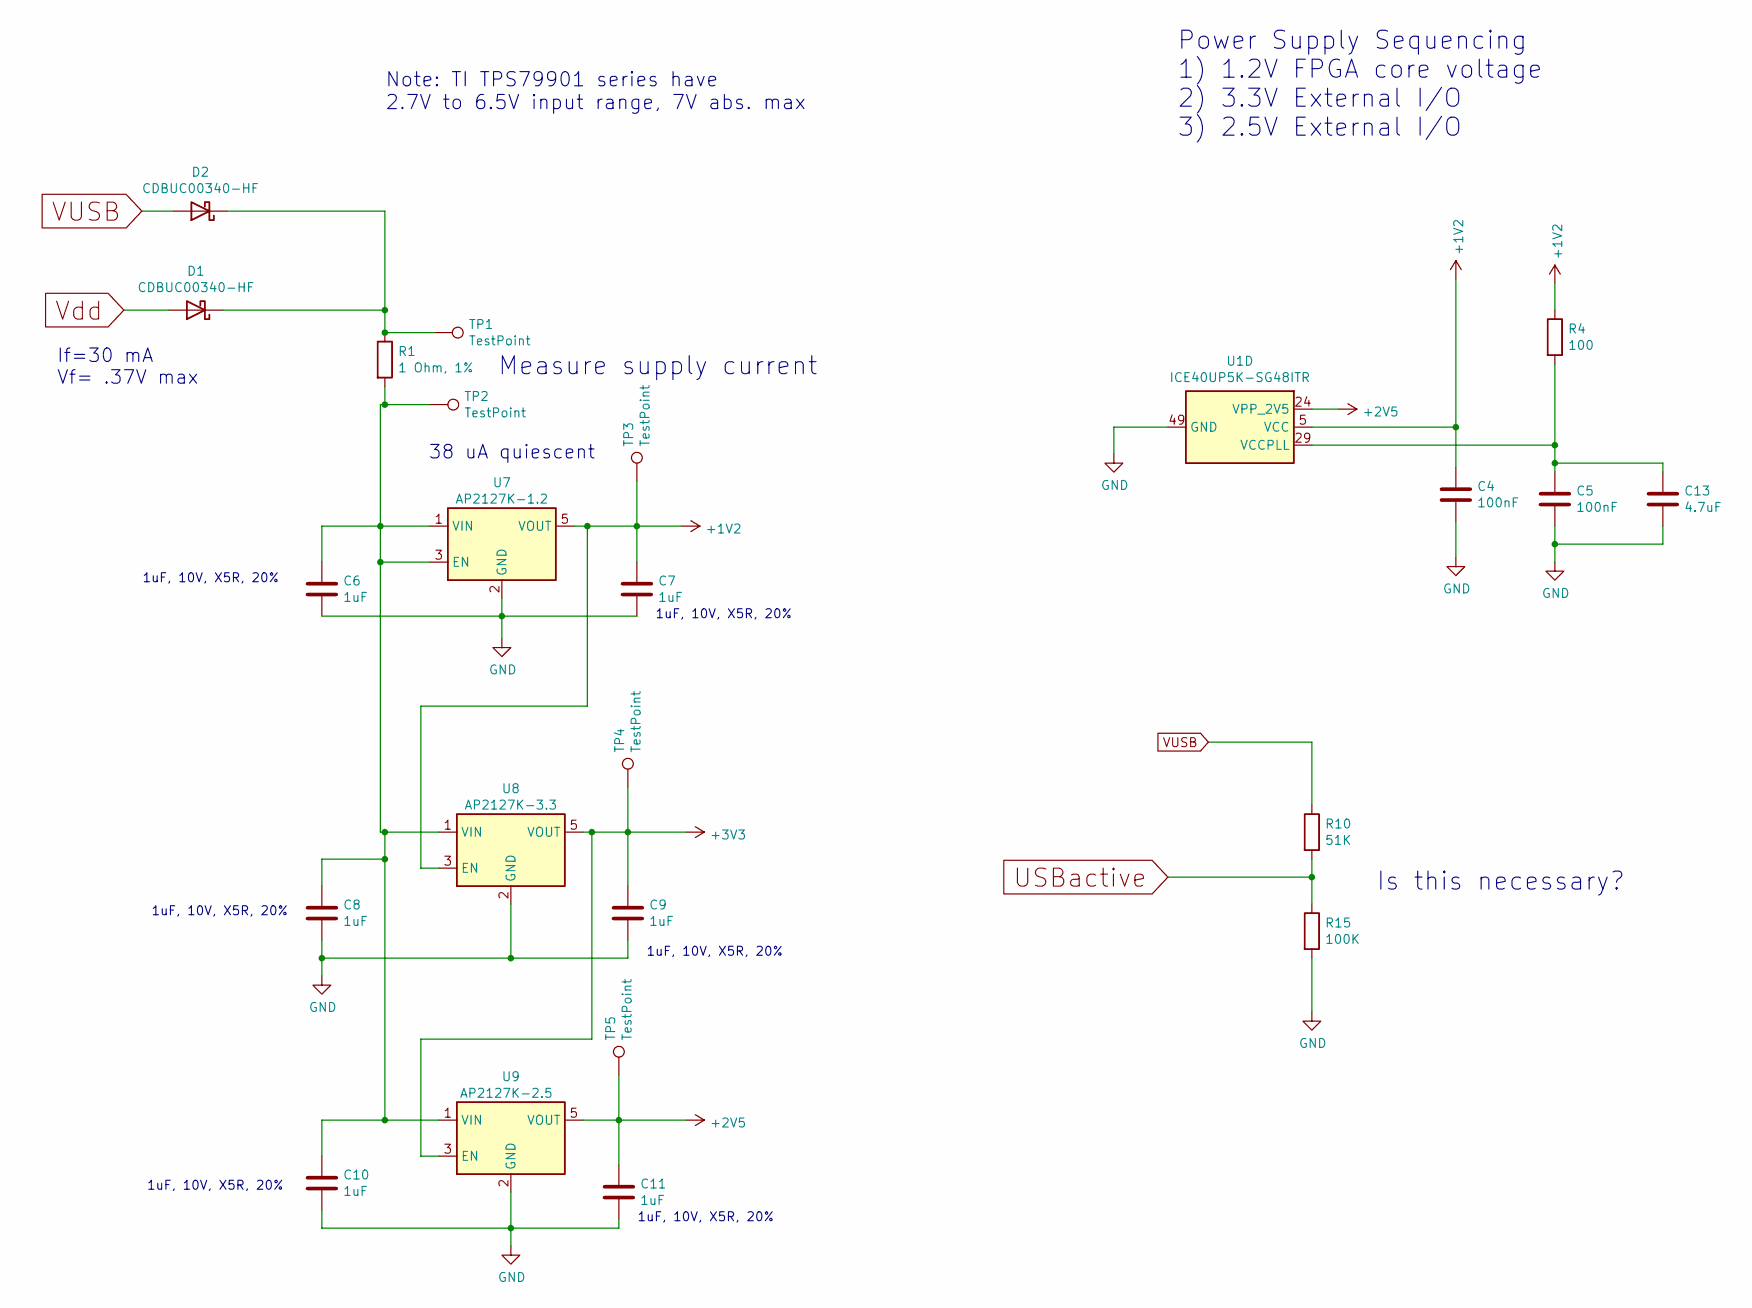
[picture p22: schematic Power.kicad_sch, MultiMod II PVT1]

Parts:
C4, C5: 100nF; C_0603_1608Metric
C6, C7, C8, C9, C10, C11: 1uF; C_0603_1608Metric
C13: 4.7uF; C_0603_1608Metric
D1, D2: CDBUC00340-HF; D_0603_1608Metric
R1: 1 Ohm, 1%; R_0603_1608Metric
R4: 100; R_0603_1608Metric
R10: 51K; R_0603_1608Metric
R15: 100K; R_0603_1608Metric
TP1, TP2, TP3, TP4, TP5: TestPoint; TestPoint_Pad_1.0x1.0mm
U1: ICE40UP5K-SG48ITR; QFN-48-1EP_7x7mm_P0.5mm_EP5.6x5.6mm
U7: AP2127K-1.2; SOT-23-5
U8: AP2127K-3.3; SOT-23-5
U9: AP2127K-2.5; SOT-23-5

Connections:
+1V2: C4.1, C7.1, R4.1, TP3.1, U1.5 (VCC), U1.30 (VCC), U7.5 (VOUT), U8.3 (EN)
+2V5: C11.1, TP5.1, U1.24 (VPP_2V5), U9.5 (VOUT)
+3V3: C9.1, TP4.1, U8.5 (VOUT), U9.3 (EN); also elsewhere on the board
GND: C4.2, C5.2, C6.2, C7.2, C8.2, C9.2, C10.2, C11.2, C13.2, R15.2, U1.49 (GND), U7.2 (GND), U8.2 (GND), U9.2 (GND); also elsewhere on the board
unnamed: D1.1 (K), D2.1 (K), R1.1, TP1.1
unnamed: C5.1, C13.1, R4.2, U1.29 (VCCPLL)
unnamed: C6.1, C8.1, C10.1, R1.2, TP2.1, U7.1 (VIN), U7.3 (EN), U8.1 (VIN), U9.1 (VIN)
USBactive: R10.2, R15.1; also elsewhere on the board
VUSB: D2.2 (A), R10.1; also elsewhere on the board
Vdd: D1.2 (A); also elsewhere on the board

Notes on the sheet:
1uF, 10V, X5R, 20%
Measure supply current
Power Supply Sequencing 1) 1.2V FPGA core voltage 2) 3.3V External I/O 3) 2.5V External I/O
Note: TI TPS79901 series have 2.7V to 6.5V input range, 7V abs. max
Is this necessary?
If=30 mA Vf= .37V max
38 uA quiescent

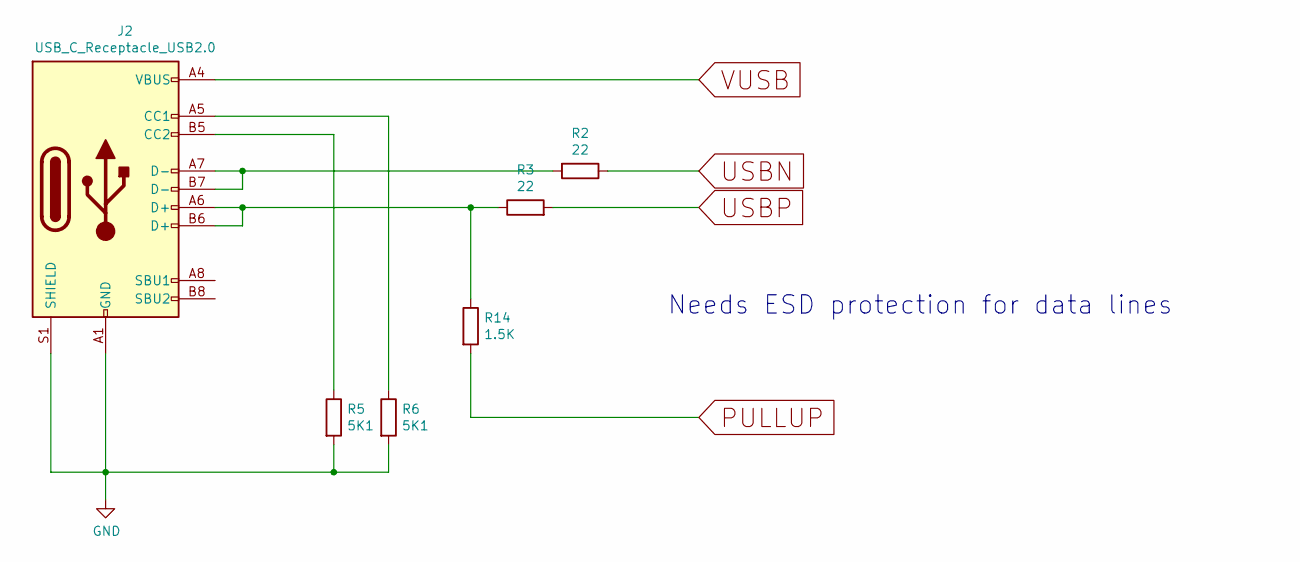
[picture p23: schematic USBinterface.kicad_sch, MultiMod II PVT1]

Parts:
J2: USB_C_Receptacle_USB2.0; USB_C_Receptacle_JAE_DX07S016JA1R1500
R2, R3: 22; R_0603_1608Metric
R5, R6: 5K1; R_0603_1608Metric
R14: 1.5K; R_0603_1608Metric

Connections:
GND: J2.A1 (GND), J2.A12 (GND), J2.B1 (GND), J2.B12 (GND), J2.S1 (SHIELD), R5.2, R6.2; also elsewhere on the board
unnamed: J2.A5 (CC1), R6.1
unnamed: J2.B5 (CC2), R5.1
unnamed: J2.A6 (D+), J2.B6 (D+), R3.1, R14.1
unnamed: J2.A7 (D-), J2.B7 (D-), R2.2
PULLUP: R14.2; also elsewhere on the board
USBN: R2.1; also elsewhere on the board
USBP: R3.2; also elsewhere on the board
VUSB: J2.A4 (VBUS), J2.A9 (VBUS), J2.B4 (VBUS), J2.B9 (VBUS); also elsewhere on the board

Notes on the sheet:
Needs ESD protection for data lines

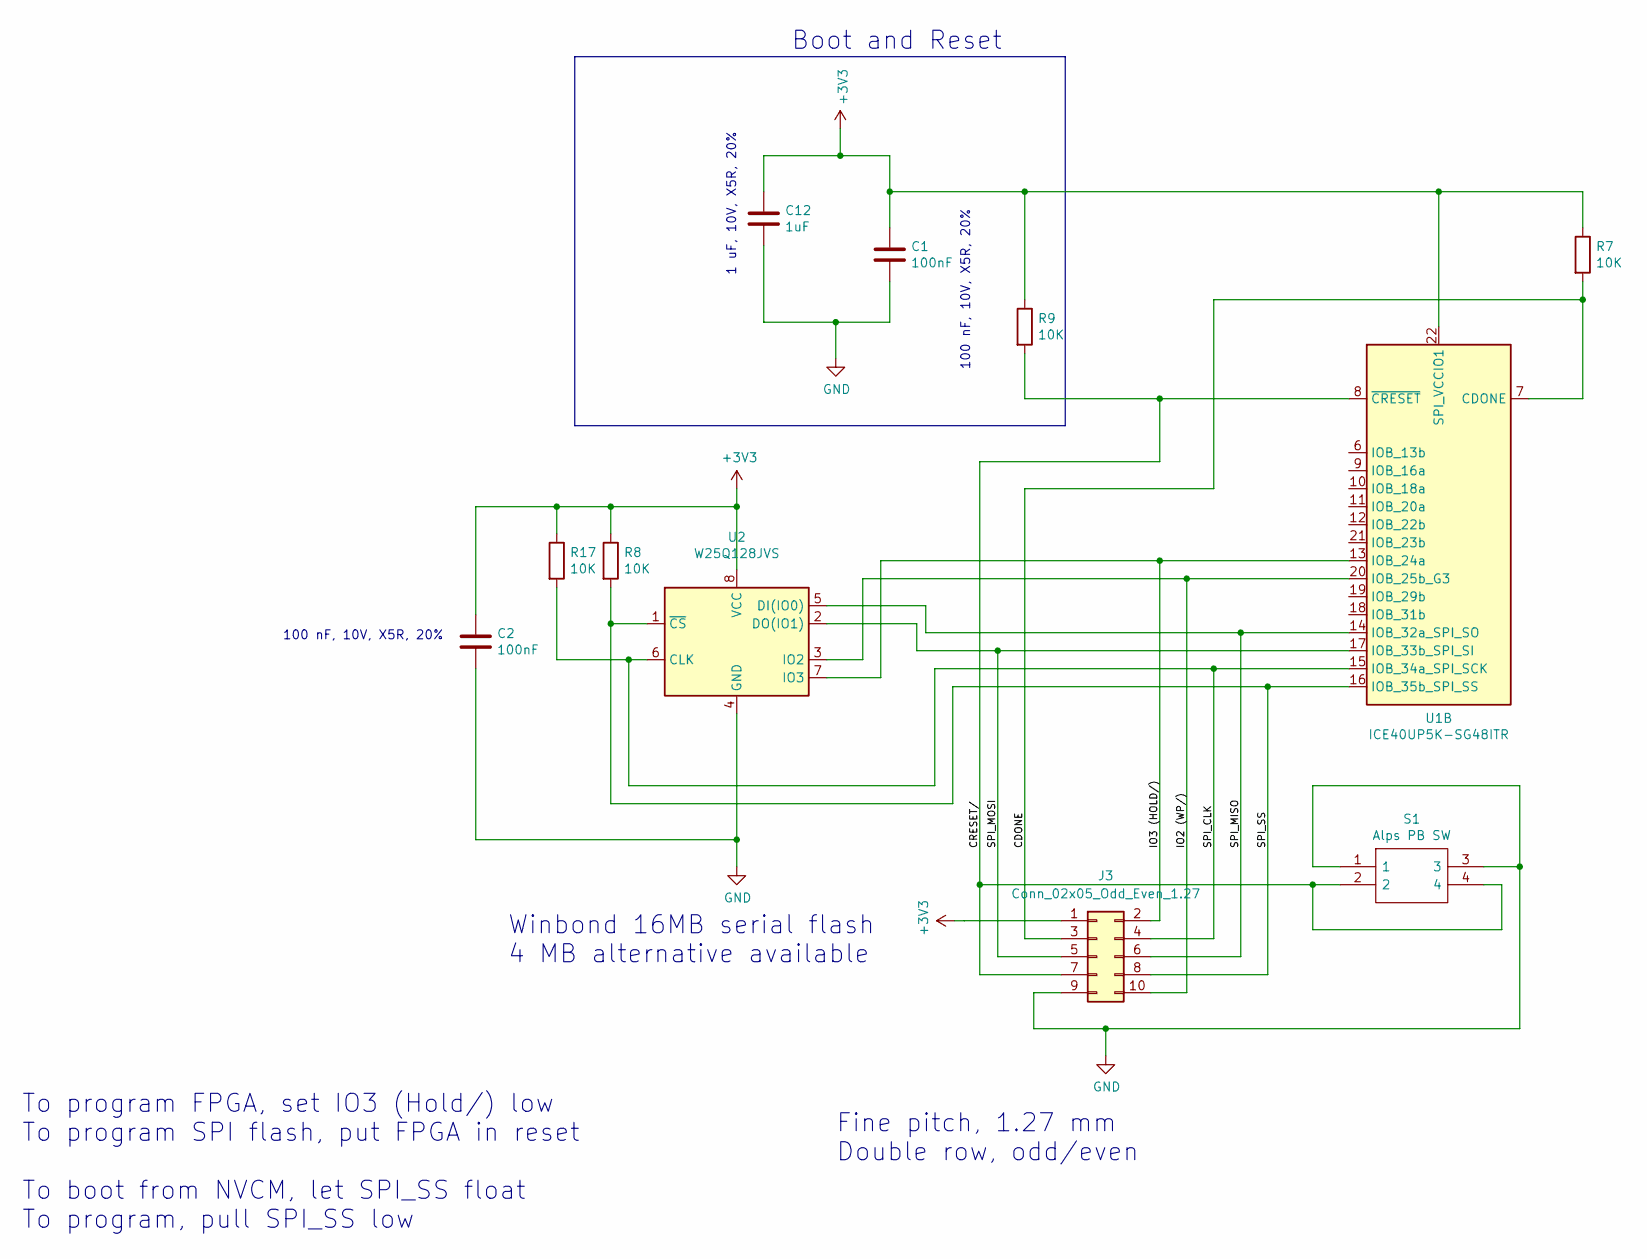
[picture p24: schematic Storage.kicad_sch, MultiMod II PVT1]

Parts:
C1, C2: 100nF; C_0603_1608Metric
C12: 1uF; C_0603_1608Metric
J3: Conn_02x05_Odd_Even_1.27; PinHeader_2x05_P1.27mm_Vertical
R7, R8, R9, R17: 10K; R_0603_1608Metric
S1: Alps PB SW; SKSVCBE010; Manufacturer_Part_Number SKSVCBE010
U1: ICE40UP5K-SG48ITR; QFN-48-1EP_7x7mm_P0.5mm_EP5.6x5.6mm
U2: W25Q128JVS; SOIC-8_5.23x5.23mm_P1.27mm

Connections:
+3V3: C1.1, C2.1, C12.1, J3.1, R7.1, R8.1, R9.1, R17.1, U1.22 (SPI_VCCIO1), U2.8 (VCC); also elsewhere on the board
/Storage/CDONE: J3.3, R7.2, U1.7 (CDONE)
/Storage/CRESET/: J3.7, R9.2, S1.2, S1.4, U1.8 (~CRESET)
/Storage/IO2 (WP/): J3.10, U1.20 (IOB_25b_G3), U2.3 (IO2)
/Storage/IO3 (HOLD/): J3.2, U1.13 (IOB_24a), U2.7 (IO3)
/Storage/SPI_CLK: J3.4, R17.2, U1.15 (IOB_34a_SPI_SCK), U2.6 (CLK)
/Storage/SPI_MISO: J3.6, U1.14 (IOB_32a_SPI_SO), U2.5 (DI(IO0))
/Storage/SPI_MOSI: J3.5, U1.17 (IOB_33b_SPI_SI), U2.2 (DO(IO1))
/Storage/SPI_SS: J3.8, R8.2, U1.16 (IOB_35b_SPI_SS), U2.1 (~CS)
GND: C1.2, C2.2, C12.2, J3.9, S1.1, S1.3, U2.4 (GND); also elsewhere on the board

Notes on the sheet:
Fine pitch, 1.27 mm Double row, odd/even
1 uF, 10V, X5R, 20%
Boot and Reset
100 nF, 10V, X5R, 20%
Winbond 16MB serial flash 4 MB alternative available
To program FPGA, set IO3 (Hold/) low To program SPI flash, put FPGA in reset To boot from NVCM, let SPI_SS float To program, pull SPI_SS low

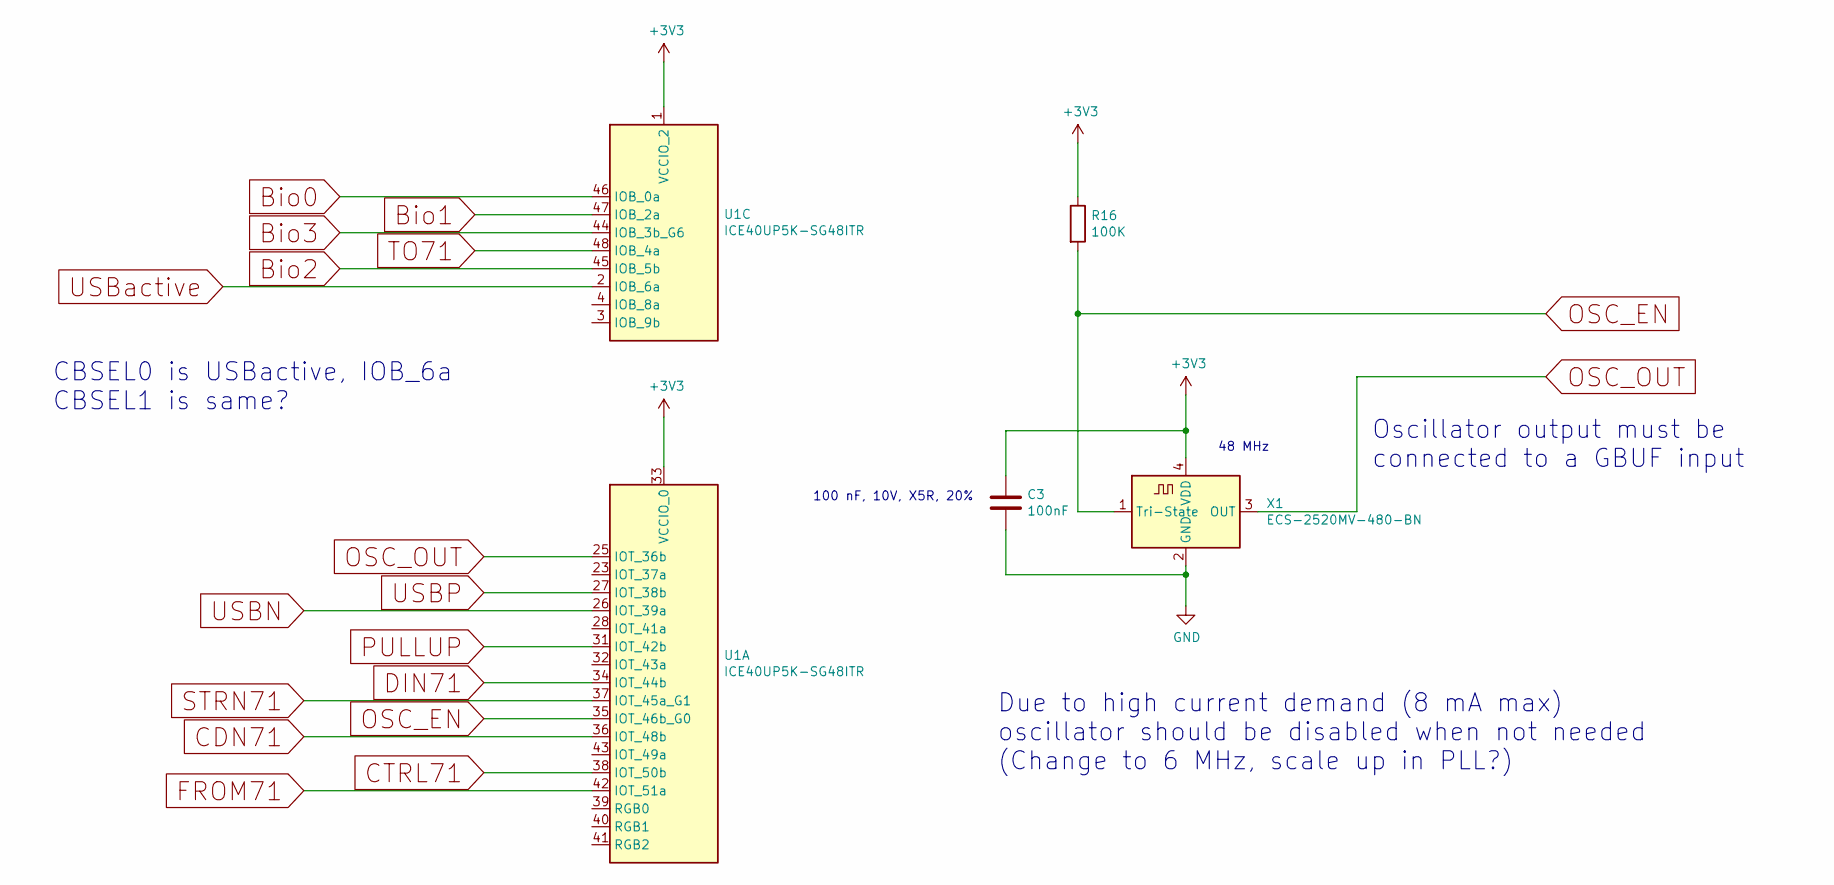
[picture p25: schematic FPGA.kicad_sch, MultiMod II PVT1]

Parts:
C3: 100nF; C_0603_1608Metric
R16: 100K; R_0603_1608Metric
U1: ICE40UP5K-SG48ITR; QFN-48-1EP_7x7mm_P0.5mm_EP5.6x5.6mm
X1: ECS-2520MV-480-BN; Oscillator_SMD_ECS_2520MV-xxx-xx-4Pin_2.5x2.0mm

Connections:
+3V3: C3.1, R16.1, U1.1 (VCCIO_2), U1.33 (VCCIO_0), X1.4 (VDD); also elsewhere on the board
Bio0: U1.46 (IOB_0a); also elsewhere on the board
Bio1: U1.47 (IOB_2a); also elsewhere on the board
Bio2: U1.45 (IOB_5b); also elsewhere on the board
Bio3: U1.44 (IOB_3b_G6); also elsewhere on the board
CDN71: U1.36 (IOT_48b); also elsewhere on the board
CTRL71: U1.38 (IOT_50b); also elsewhere on the board
DIN71: U1.34 (IOT_44b); also elsewhere on the board
FROM71: U1.42 (IOT_51a); also elsewhere on the board
GND: C3.2, X1.2 (GND); also elsewhere on the board
OSC_EN: R16.2, U1.35 (IOT_46b_G0), X1.1 (Tri-State)
OSC_OUT: U1.25 (IOT_36b), X1.3 (OUT)
PULLUP: U1.31 (IOT_42b); also elsewhere on the board
STRN71: U1.37 (IOT_45a_G1); also elsewhere on the board
TO71: U1.48 (IOB_4a); also elsewhere on the board
USBN: U1.26 (IOT_39a); also elsewhere on the board
USBP: U1.27 (IOT_38b); also elsewhere on the board
USBactive: U1.2 (IOB_6a); also elsewhere on the board

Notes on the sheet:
Oscillator output must be connected to a GBUF input
CBSEL0 is USBactive, IOB_6a CBSEL1 is same?
48 MHz
Due to high current demand (8 mA max) oscillator should be disabled when not needed (Change to 6 MHz, scale up in PLL?)
100 nF, 10V, X5R, 20%

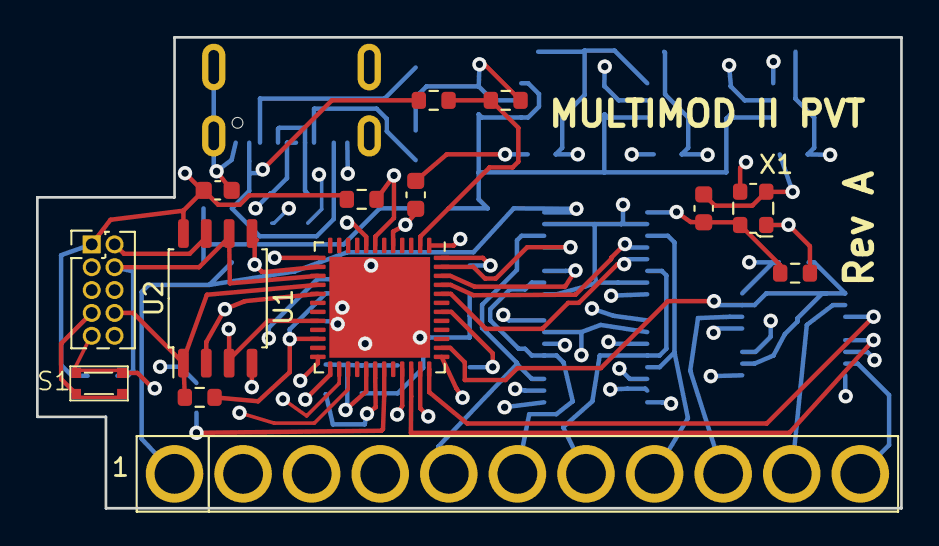
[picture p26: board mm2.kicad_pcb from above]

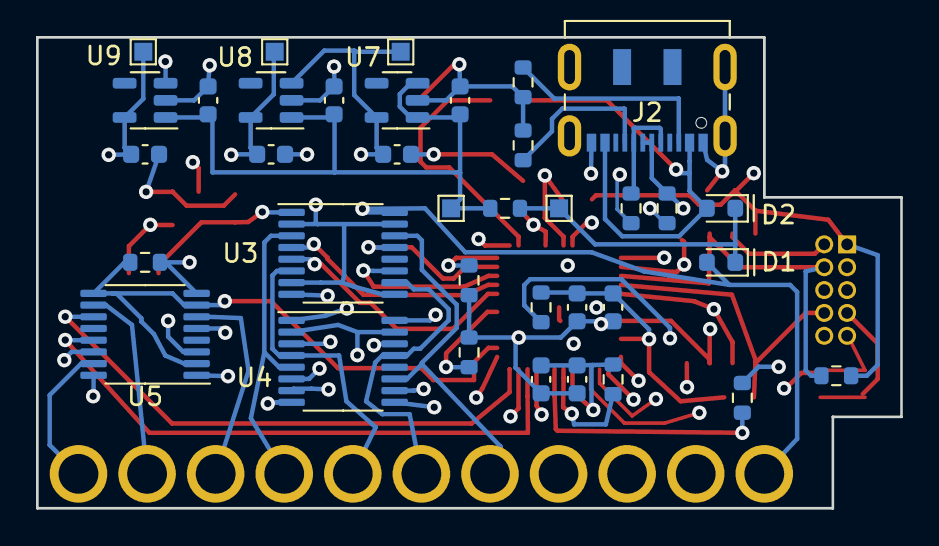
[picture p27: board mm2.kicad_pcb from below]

Board: 4 copper layers, 48.0 x 26.2 mm, 50 parts (36 on the bottom side), 44 nets.

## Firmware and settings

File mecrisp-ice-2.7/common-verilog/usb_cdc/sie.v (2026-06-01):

//  USB 2.0 full speed Serial Interface Engine.
//  Written in verilog 2001

// SIE module shall manage physical and protocol layers of full
//   speed USB 2.0 (USB2.0 Chapters 7 and 8):
//   - Packet recognition, transaction sequencing.
//   - CRC generation and checking (Token and Data).
//   - Packet ID (PID) generation and checking/decoding.
//   And through PHY_RX and PHY_TX submodules:
//   - Start-Of-Packet (SOP) and Sync Pattern detection/generation.
//   - NRZI Data decoding/encoding.
//   - Bit Stuffing removal/insertion.
//   - End-Of-Packet (EOP) detection/generation.
//   - USB Reset detection.
//   - Serial-Parallel/Parallel-Serial conversion.

module sie
  #(parameter CTRL_MAXPACKETSIZE = 'd8,
    parameter IN_BULK_MAXPACKETSIZE = 'd8,
    parameter ENDP_CTRL = 4'd0,
    parameter ENDP_BULK = 4'd1,
    parameter BIT_SAMPLES = 'd4)
   (
    // ---- to/from USB_CDC module ------------------------------------
    output        usb_reset_o,
    // When rx_dp_i/rx_dn_i change and stay in SE0 condition for 2.5us, usb_reset_o shall be high.
    // When usb_reset_o changes from low to high, usb_reset_o shall return low after 330ns.
    // When usb_reset_o changes from high to low and rx_dp_i/rx_dn_i are in SE0 condition,
    //   usb_reset_o shall return high after 2.5us.
    output [3:0]  endp_o,
    // endp_o shall be last recognized endpoint address and shall be
    //   updated at the end of next valid token packet.
    output [10:0] frame_o,
    // frame_o shall be last recognized frame number and shall be
    //   updated at the end of next valid Start-of-Frame token packet.
    input         clk_i,
    input         rstn_i,

    // ---- to/from OUT Endpoints ------------------------------------
    output [7:0]  out_data_o,
    output        out_valid_o,
    // While out_valid_o is high, the out_data_o shall be valid and both
    //   out_valid_o and out_data_o shall not change until consumed.
    output        out_err_o,
    // When both out_err_o and out_ready_o are high, SIE shall abort the
    //   current packet reception and OUT Endpoints shall manage the error
    //   condition.
    output        out_ready_o,
    // When both out_valid_o and out_ready_o are high, the out_data_o shall
    //   be consumed.
    // When setup_o is high and out_ready_o is high, a new SETUP transaction shall be
    //   received.
    // When setup_o, out_valid_o and out_err_o are low and out_ready_o is high, the
    //   on-going OUT transaction shall end or an ACK packet shall be received.
    // out_ready_o shall be high only for one clk_i period.
    input         out_nak_i,
    // When out_nak_i is high at the end of an OUT transaction, SIE shall send a NAK
    //   packet.

    // ---- to/from IN Endpoints -------------------------------------
    output        in_req_o,
    output        in_ready_o,
    // When both in_ready_o and in_valid_i are high, in_data_i or zero length
    //   packet shall be consumed.
    // When in_data_i or zlp is consumed, in_ready_o shall be high only for
    //   one clk_i period.
    input         in_valid_i,
    // While in_req_o is high and IN Endpoints have data or zero length packet
    //   available, IN Endpoints shall put in_valid_i high.
    input [7:0]   in_data_i,
    // While in_valid_i is high and in_zlp_i is low, in_data_i shall be valid.
    input         in_zlp_i,
    // While in_req_o is high and IN Endpoints have zero length packet available,
    //   IN Endpoints shall put both in_zlp_i and in_valid_i high.

    // ---- to/from CONTROL Endpoint ---------------------------------
    output        setup_o,
    // While last correctly checked PID (USB2.0 8.3.1) is SETUP, setup_o shall
    //   be high, otherwise shall be low.
    input [6:0]   addr_i,
    // addr_i shall be the device address.
    // addr_i shall be updated at the end of SET_ADDRESS control transfer.
    input         stall_i,
    // While control pipe is addressed and is in stall state, stall_i shall
    //   be high, otherwise shall be low.
    input         in_toggle_reset_i,
    // When in_toggle_reset_i is high, data toggle synchronization of
    //   IN bulk pipe shall be reset to DATA0.
    input         out_toggle_reset_i,
    // When out_toggle_reset_i is high, data toggle synchronization of
    //   OUT bulk pipe shall be reset to DATA0.

    // ---- to/from USB bus physical transmitters/receivers ----------
    output        tx_en_o,
    output        tx_dp_o,
    output        tx_dn_o,
    input         rx_dp_i,
    input         rx_dn_i
    );

   function integer ceil_log2;
      input integer arg;
      begin
         ceil_log2 = 0;
         while ((2 ** ceil_log2) < arg)
           ceil_log2 = ceil_log2 + 1;
      end
   endfunction

   localparam [4:0] POLY5 = 5'b00101;
   function [4:0] crc5;
      input [10:0] data;
      reg [3:0]        i;
      begin
         crc5 = 5'b11111;
         for (i = 0; i <= 10; i = i + 1) begin
            if ((data[i] ^ crc5[4]) == 1'b1)
              crc5 = {crc5[3:0], 1'b0} ^ POLY5;
            else
              crc5 = {crc5[3:0], 1'b0};
         end
      end
   endfunction

   function [4:0] rev5;
      input [4:0] data;
      reg [2:0]   i;
      begin
         for (i = 0; i <= 4; i = i + 1) begin
            rev5[i] = data[4-i];
         end
      end
   endfunction

   localparam [15:0] POLY16 = 16'h8005;
   function [15:0] crc16;
      input [7:0] data;
      input [15:0] crc;
      reg [3:0]         i;
      begin
         crc16 = crc;
         for (i = 0; i <= 7; i = i + 1) begin
            if ((data[i[2:0]] ^ crc16[15]) == 1'b1)
              crc16 = {crc16[14:0], 1'b0} ^ POLY16;
            else
              crc16 = {crc16[14:0], 1'b0};
         end
      end
   endfunction

   function [7:0] rev8;
      input [7:0] data;
      reg [3:0]   i;
      begin
         for (i = 0; i <= 7; i = i + 1) begin
            rev8[i[2:0]] = data[7-i];
         end
      end
   endfunction
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

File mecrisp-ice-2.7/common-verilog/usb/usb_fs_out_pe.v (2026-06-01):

// The OUT Protocol Engine receives data from the host.
module usb_fs_out_pe #(
  parameter NUM_OUT_EPS = 1,
  parameter MAX_OUT_PACKET_SIZE = 32
) (
  input clk,
  input reset,
  input [NUM_OUT_EPS-1:0] reset_ep, 
  input [6:0] dev_addr,

  ////////////////////
  // endpoint interface 
  ////////////////////
  output [NUM_OUT_EPS-1:0] out_ep_data_avail,
  output reg [NUM_OUT_EPS-1:0] out_ep_setup = 0,
  input [NUM_OUT_EPS-1:0] out_ep_data_get,
  output reg [7:0] out_ep_data = 0,
  input [NUM_OUT_EPS-1:0] out_ep_stall,
  output reg [NUM_OUT_EPS-1:0] out_ep_acked = 0,


  ////////////////////
  // rx path 
  ////////////////////

  // Strobed on reception of packet.
  input rx_pkt_start,
  input rx_pkt_end,
  input rx_pkt_valid,

  // Most recent packet received.
  input [3:0] rx_pid,
  input [6:0] rx_addr,
  input [3:0] rx_endp,
  input [10:0] rx_frame_num,

  // rx_data is pushed into endpoint controller.
  input rx_data_put,
  input [7:0] rx_data,


  ////////////////////
  // tx path 
  ////////////////////

  // Strobe to send new packet.
  output reg tx_pkt_start = 0,
  input tx_pkt_end,
  output reg [3:0] tx_pid = 0
);
  ////////////////////////////////////////////////////////////////////////////////
  // endpoint state machine
  ////////////////////////////////////////////////////////////////////////////////
  localparam READY_FOR_PKT = 0;
  localparam PUTTING_PKT = 1;
  localparam GETTING_PKT = 2;
  localparam STALL = 3;
  
  reg [1:0] ep_state [NUM_OUT_EPS - 1:0];
  reg [1:0] ep_state_next [NUM_OUT_EPS - 1:0];


  ////////////////////////////////////////////////////////////////////////////////
  // out transfer state machine
  ////////////////////////////////////////////////////////////////////////////////
  localparam IDLE = 0;
  localparam RCVD_OUT = 1;
  localparam RCVD_DATA_START = 2; 
  localparam RCVD_DATA_END = 3; 
  
  reg [1:0] out_xfr_state = IDLE;
  reg [1:0] out_xfr_state_next;

  reg out_xfr_start = 0;
  reg new_pkt_end = 0;
  reg rollback_data = 0;


  reg [3:0] out_ep_num = 0;
  

  reg [NUM_OUT_EPS - 1:0] out_ep_data_avail_i = 0;
  reg [NUM_OUT_EPS - 1:0] out_ep_data_avail_j = 0;

  // set when the endpoint buffer is unable to receive the out transfer
  reg nak_out_transfer = 0;

  // data toggle state
  reg [NUM_OUT_EPS - 1:0] data_toggle = 0;

  // latched on valid OUT/SETUP token
  reg [3:0] current_endp = 0;
  wire [1:0] current_ep_state = ep_state[current_endp];

  // endpoint data buffer
  reg [7:0] out_data_buffer [(MAX_OUT_PACKET_SIZE * NUM_OUT_EPS) - 1:0];

  // current get_addr when outputting a packet from the buffer
  reg [5:0] ep_get_addr [NUM_OUT_EPS - 1:0];
  reg [5:0] ep_get_addr_next [NUM_OUT_EPS - 1:0];
  

  // endpoint put_addrs when inputting a packet into the buffer
  reg [5:0] ep_put_addr [NUM_OUT_EPS - 1:0];

  // total buffer put addr, uses endpoint number and that endpoints current
  // put address
  wire [8:0] buffer_put_addr = {current_endp[3:0], ep_put_addr[current_endp][4:0]};
  wire [8:0] buffer_get_addr = {out_ep_num[3:0], ep_get_addr[out_ep_num][4:0]};

  wire token_received = 
    rx_pkt_end &&
    rx_pkt_valid &&
    rx_pid[1:0] == 2'b01 &&
    rx_addr == dev_addr &&
    rx_endp < NUM_OUT_EPS;

  wire out_token_received =
    token_received &&
    rx_pid[3:2] == 2'b00;

  wire setup_token_received =
    token_received &&
    rx_pid[3:2] == 2'b11;

  wire invalid_packet_received =
    rx_pkt_end &&
    !rx_pkt_valid;

  wire data_packet_received =
    rx_pkt_end &&
    rx_pkt_valid &&
    rx_pid[2:0] == 3'b011;

  wire non_data_packet_received =
    rx_pkt_end &&
    rx_pkt_valid &&
    rx_pid[2:0] != 3'b011;

  //reg last_data_toggle = 0;

  wire bad_data_toggle =
    data_packet_received &&
    rx_pid[3] != data_toggle[rx_endp];

    //last_data_toggle == data_toggle[current_endp];

  ////////////////////////////////////////////////////////////////////////////////
  // endpoint state machine
  ////////////////////////////////////////////////////////////////////////////////

  genvar ep_num;
  generate
    for (ep_num = 0; ep_num < NUM_OUT_EPS; ep_num = ep_num + 1) begin
      always @* begin

        ep_state_next[ep_num] <= ep_state[ep_num];

        if (out_ep_stall[ep_num]) begin
          ep_state_next[ep_num] <= STALL;

        end else begin
          case (ep_state[ep_num])
            READY_FOR_PKT : begin
              if (out_xfr_start && rx_endp == ep_num) begin
                ep_state_next[ep_num] <= PUTTING_PKT;

              end else begin
                ep_state_next[ep_num] <= READY_FOR_PKT;
              end
            end

            PUTTING_PKT : begin
              if (new_pkt_end && current_endp == ep_num) begin
                ep_state_next[ep_num] <= GETTING_PKT;

              end else if (rollback_data && current_endp == ep_num) begin
                ep_state_next[ep_num] <= READY_FOR_PKT;

              end else begin
                ep_state_next[ep_num] <= PUTTING_PKT;
              end
            end

            GETTING_PKT : begin

              if (ep_get_addr[ep_num][5:0] >= (ep_put_addr[ep_num][5:0] - 6'H2)) begin
                ep_state_next[ep_num] <= READY_FOR_PKT;

              end else begin
                ep_state_next[ep_num] <= GETTING_PKT;
              end
            end

            STALL : begin
              if (setup_token_received && rx_endp == ep_num) begin
                ep_state_next[ep_num] <= READY_FOR_PKT;

              end else begin
                ep_state_next[ep_num] <= STALL;
              end
            end

            default begin
              ep_state_next[ep_num] <= READY_FOR_PKT;
            end
          endcase
        end

        if (ep_state_next[ep_num][1:0] == READY_FOR_PKT) begin
          ep_get_addr_next[ep_num][5:0] <= 0;
        end else if (ep_state_next[ep_num][1:0] == GETTING_PKT && out_ep_data_get[ep_num]) begin
          ep_get_addr_next[ep_num][5:0] <= ep_get_addr[ep_num][5:0] + 6'H1;
        end else begin
          ep_get_addr_next[ep_num][5:0] <= ep_get_addr[ep_num][5:0];
        end
      end

      always @(posedge clk) begin
        if (reset || reset_ep[ep_num]) begin
          ep_state[ep_num] <= READY_FOR_PKT;
        end else begin
          ep_state[ep_num] <= ep_state_next[ep_num];
        end

        ep_get_addr[ep_num][5:0] <= ep_get_addr_next[ep_num][5:0];
      end
      

      assign out_ep_data_avail[ep_num] = 
        (ep_get_addr[ep_num][5:0] < (ep_put_addr[ep_num][5:0] - 6'H2)) &&
        (ep_state[ep_num][1:0] == GETTING_PKT);



    end
  endgenerate

  integer i;
  always @(posedge clk) begin
    if (reset) begin
      out_ep_setup <= 0;

    end else begin
      if (setup_token_received) begin
        out_ep_setup[rx_endp] <= 1;
      end else if (out_token_received) begin
        out_ep_setup[rx_endp] <= 0;
      end
    end

    for (i = 0; i < NUM_OUT_EPS; i = i + 1) begin
      if (reset_ep[i]) begin
        out_ep_setup[i] <= 0;
      end
    end
  end
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

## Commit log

2026-05-27 MultiMod II Board Design Files
    Finished Kicad design files and BOM.
    [71Interface.kicad_sch, AAPCB_BOM_Format.xlsx, AAPCB_BOM_Format_MM2.xlsx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]
2026-06-01 MultiMod II Bootloader Using Mecrisp-ice
    This is version 2.7 of mecrisp-ice, an enhancement of James Bowman's J1A Forth CPU and Swapforth. Subdirectories for ports to other boards have been removed.
2026-07-18 Dual/Quad SPI Transfer Hardware Support
    Still using standard transfer protocol. Dual/Quad software support to follow.
2026-09-24 First Development Release, HP-71B Embedded Design
    The Forth code to plug, unplug, save, and create ROM/RAM images for the 71B is present. The Verilog design currently supports development and testing. Transition to standalone embedded operation will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
2026-11-10 Additional Test Benches Using Macros
    The use of #define macros within each C++ test bench helps reduce text clutter and simplify test case construction.

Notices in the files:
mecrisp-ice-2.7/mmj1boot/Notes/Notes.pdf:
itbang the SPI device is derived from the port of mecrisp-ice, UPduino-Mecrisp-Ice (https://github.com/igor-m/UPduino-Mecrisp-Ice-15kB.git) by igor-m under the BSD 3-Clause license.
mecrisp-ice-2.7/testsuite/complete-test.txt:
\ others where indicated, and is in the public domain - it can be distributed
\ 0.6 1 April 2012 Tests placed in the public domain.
